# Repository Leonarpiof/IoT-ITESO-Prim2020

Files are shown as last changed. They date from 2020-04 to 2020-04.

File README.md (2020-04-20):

# IoT-ITESO-Prim2020
This repo contains the documentation and generated files during the IoT project of spring 2020 at ITESO, by Leon Arpio Fernandez

## Folders
### Arduino
Contains the source code of the project, in which the sensors are read, and data is sent through cellular network, 
using MQTT. This project is made for the Arduino MKR GSM 1400.

This project uses the following libraries:
- [Arduino MKR GSM libraries](https://github.com/arduino-libraries/MKRGSM)
- [MQTT library for Arduino](https://github.com/256dpi/arduino-mqtt)
- [I2C Soil Moisture Sensor](https://github.com/Apollon77/I2CSoilMoistureSensor)

### Documentation
Contains the documentation made during the project, which contains the research plan, comparative tables, requirements, business model,
customer journey, and others. **All documentas are in Spanish**.

### Lambda
Contains the Lambda deploy package, which has the lambda function handler, and the necessary libraries for the project to work, that are not included in AWS Lambda. Developed in Python 3.8. For the Lambda deploy package download Python library [requests](https://requests.readthedocs.io/en/master/).

To install the library in a specific folder, navigate in the command line to the desired folder, and use the following command.

```
pip install requests -t .
```
- Download [pip](https://pip.pypa.io/en/stable/reference/pip_download/)

### Schematics
Contains the schematic, board file and BOM. Schematic based on [Arduino MKR GSM 1400 schematic](https://store.arduino.cc/usa/mkr-gsm-1400).

### Scripts
Contains Python scripts to test different elements such as Ubidots, Mosquitto, and other features. For this scripts to work, it is necessary to install paho-mqtt and requests. Scripts developed in Python 3.8.1

# Author
León Arpio Fernández

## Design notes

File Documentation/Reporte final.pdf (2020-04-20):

## Instituto Tecnológico y de Estudios

## Superiores de Occidente – ITESO

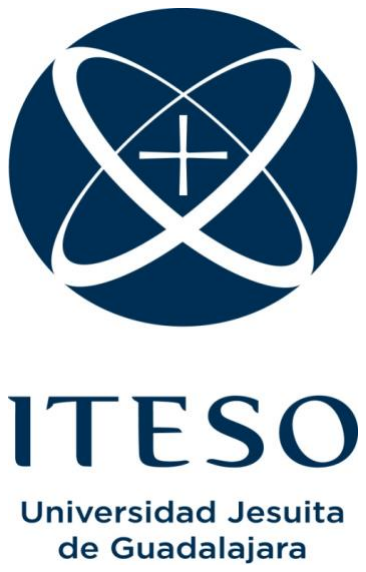
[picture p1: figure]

Reporte final

Materia: | Internet of Things
Maestro: | Héctor Edmundo Ramírez Gómez
Fecha: | 20 de abril de 2020
Autor: | Arpio Fernández, León. IE702086

Índice

Introducción

Planteamiento del problema

Conforme aumenta la población, cada día es más importante el manejo correcto de los

recursos a nuestro alrededor, ya que la demanda de estos aumenta de manera directa e

indirecta, viéndose la agricultura cada vez más afectada por este incremento, ya que no solo

debe de cumplir con el mercado, sino que es más costoso acceder a los recursos necesarios

para mantener la producción. A esto se suma el impacto ambiental de la agricultura, debido al

consumo constante de agua, suelo y energía que requiere para poder proveer alimentos a la

población.

Por eso, se existe la problemática del uso ineficiente de los recursos en la agricultura, ya que

muchas veces se desperdician algunos recursos como agua, sustratos, abonos, y no se

aprovechan de manera correcta otros, como la luz solar. Esto genera una amplia variedad de

problemas, que van desde generar un producto de mala calidad, hasta perder cosechas por

causa de enfermedades y plagas. A esto, se suma el hecho de que se invirtiera mucho dinero,

tiempo, mano de obra y materias primas en el plantío.

También, aunque un plantío no tenga problemas en la calidad del producto, o con

enfermedades en las plantas, este puede ser víctima de un uso muy ineficiente de recursos,

ya sea que estos se utilicen de más o de menos, lo que se ve reflejado en un impacto

monetario, que tal vez no sea tan obvio, pero que, manejando estas materias de manera

correcta, podría aumentar el margen de utilidad.

Objetivo

El objetivo de este proyecto es el de desarrollar un dispositivo capaz de monitorear las

variables más importantes en un cultivo de lechuga, y que pueda transmitir la información a un

servidor remoto, de manera que esta sea desplegada en tiempo real utilizando un tablero para

dar un formato visual y de fácil entendimiento, para de esta manera ayudar a los agricultores

a reducir los desperdicios tanto de productos como de recursos dedicados al cuidado de los

cultivos.

Validaciones

Se realizaron entrevistas a personas con conocimiento sobre el cuidado de cultivos,

especialmente de la lechuga, para conocer cuales son los principales riesgos y desperdicios,

así como las variables más importantes a monitorear para reducir o prevenir estos problemas.

Entrevistas

Laura Bucio – Proyecto de hidroponía para asignatura Internet of Things

¿Cuáles son los riesgos más comunes en el cultivo de la lechuga?

Muy sensible a la falta de higiene, ya que se pueden generar muchas bacterias. Lo más

recomendable es tener el área lo más limpio posible, para evitar que la lechuga se empiece a

pudrir.

¿Qué recursos y/o materias primas se desperdician más en un cultivo?

Los solutos, pues a veces no hay una medición precisa para saber cuánto se necesita para la

hidroponía.

¿Qué es lo que más valor te agregaría a tu negocio?

Tener un sistema autónomo que permita tener el monitoreo del cultivo a través de cualquier

dispositivo. Conectividad y medición de variables.

Si pudieras tener un dispositivo para el monitoreo de cultivos:

¿Cuáles son las variables más importantes por monitorear en un cultivo de lechugas?

Conductividad, luz, temperatura, pH.

¿Con qué frecuencia te gustaría actualizar la información de las variables?

Aproximadamente cada media hora, dependiendo de las hectáreas de lechuga que se tenga.

¿A qué alertas te gustaría tener acceso?

Alertas de todas las mediciones, aunque dependerá de la lechuga a la que se quiera enfocar;

romana, italiana, entre otras. Cada una tiene un tipo de pH, aunque hay un estándar para las

lechugas en general, hay ligeras variaciones para cada una.

¿Te gustaría ver alguna otra característica en el dispositivo?

Que sea visual, ya que algunos agrónomos prefieren que se les dé el dato y otros prefieren

que al final del día se les proporcione una gráfica con la información recolectada.

Álvaro – Verde tu vida

¿Cuáles son los riesgos más comunes en el cultivo de la lechuga?

Plagas, las más comunes son la mosca blanca y el pulgón amarillo. También la refrigeración y

almacenamiento del producto.

¿Qué recursos y/o materias primas se desperdician más en un cultivo?

Comúnmente, el agua, aunque depende mucho del diseño del sistema, también, los

fertilizantes, ya que se desperdician si estos no son asimilables o útiles para la planta, e incluso

se puede ver afectado el rendimiento del cultivo

¿Qué es lo que más valor te agregaría a tu negocio?

Incluir un envase, ya que estos aumentan mucho el precio del producto, y es necesario pues

al consumidor le da mucha confianza ver el producto empacado. Además, esto tiene un

impacto ecológico negativo.

Si pudieras tener un dispositivo para el monitoreo de cultivos:

¿Cuáles son las variables más importantes por monitorear en un cultivo de lechugas?

La luminosidad, el control de la humedad te puede evitar problemas con hongos y con plagas,

así como la temperatura. Otras variables importantes son la conductividad eléctrica y el nivel

de oxígeno en el agua. Sería útil un sistema de detección de plagas, para que la detección sea

en una fase temprana y no cuando el problema sea evidente y mucho más difícil de erradicar

o controlar.

¿Con qué frecuencia te gustaría actualizar la información de las variables?

Sería suficiente cada hora, ya que con este tiempo es suficiente reaccionar ante cualquier

cambio o fluctuación de las variables. Menos de una hora no sería necesario, incluso en

algunas variables por un periodo más prolongado, tal vez 3 horas.

¿A qué alertas te gustaría tener acceso?

Sería interesante tener alertas de bajas y altas temperaturas, de humedad baja y alta, niveles

de pH. Una alerta para detección temprana de presencia de plagas también sería atractiva.

Incluso sería interesante un monitoreo del crecimiento de la planta, por si la producción está

de algún modo escalonada, saber que lote es el más próximo a cosecha, para tenerlas en el

momento más oportuno.

Víctor Mojarro – Inncampo

¿Cuáles son los riesgos más comunes en el cultivo de la lechuga?

Primero, están los climáticos, que son los que tienen que ver con la temperatura, la radiación

solar, la luminosidad, entre otros. También puede haber daños físicos a las plantas, como falta

de cuidado en la manipulación de las plantas, mal manejo de herbicidas, sustratos, abono, etc.

Y están los daños biológicos, que son las plagas, hongos, patógenos y bacterias indeseadas

en el ambiente de cultivo.

Además de estos riesgos, también puede haber una mala selección de la lechuga, ya que

estas se dan por temporadas, una mala planificación del terreno, logística o los recursos

humanos.

¿Qué recursos y/o materias primas se desperdician más en un cultivo?

El principal es el dinero, ya que, como no hay un estándar de “los pasos a seguir”, no se utilizan

correctamente el agua, los fertilizantes y químicos, pues no se usan las cantidades necesarias

en el momento indicado.

Muchas veces el suelo no se aprovecha de manera correcta, ya que este no se estudia lo

suficiente antes de determinar cuántas plantas se cultivarán por metro cuadrado.

¿Qué es lo que más valor te agregaría a tu negocio?

Tener datos tanto climatológicos como eficiencias administrativas. El análisis de datos en todo

momento ayuda para mejorar el uso de los recursos destinados al cultivo, ya que solo se

utilizan las cantidades necesarias, y se disminuye el desperdicio. Además, el uso incorrecto de bienes como el agua, o los sustratos, pueden influir en la presencia de hongos o enfermedades

en la planta de lechuga.

Si pudieras tener un dispositivo para el monitoreo de cultivos:

¿Cuáles son las variables más importantes por monitorear en un cultivo de lechugas?

Humedad en el ambiente y suelo, luminosidad, radiación UVA y UVB, velocidad del viento,

temperatura ambiente y en el suelo, PH en el suelo y en el agua, conductividad eléctrica y

salinidad en el suelo.

También sería interesante tener mediciones del sistema de riego, para tener un control del

volumen de agua que está siendo utilizada para el riego.

¿Con qué frecuencia te gustaría actualizar la información de las variables?

Cada 30 minutos, aproximadamente, a lo largo del día y la noche.

Aproximadamente, ¿Cuantos dispositivos por unidad de área son necesarios?

Dependerá de la planta, y del terreno, pero se necesita al menos 1 dispositivo por cada 100

m2.

¿A qué alertas te gustaría tener acceso?

A mediciones altas y bajas de todas las variables leídas por el dispositivo.

¿Hay alguna relación entre los valores de las variables y la existencia de plagas?

Hay enfermedades, como la cenicilla, que se presenta cuando tienes alta humedad,

temperatura y un pH desfavorable. También, el exceso de ácido nítrico (Compuesto químico

usado en abonos) puede generar putrefacción en la planta.

Hay que tomar en cuenta que estas condiciones favorecen las enfermedades en las plantas,

mas no son indicadores de que el cultivo presenta estos males.

¿Te gustaría ver alguna otra característica en el dispositivo?

Algo que no he visto en ningún dispositivo, y que sería muy útil su monitoreo, es el de la vida

microbiana en el suelo, aunque esto es extremadamente difícil de lograr.

Consideraciones

La lechuga es muy sensible, y necesita mucho cuidado, desde la selección de la semilla, ya

que las diferentes lechugas son para diferentes temporadas; hay de frío a frío, frío a calor,

calor a calor y calor a frío.

La lechuga puede crecer en invernadero, marcotúnel, hidroponía o en campo abierto, y

siempre es necesario hacer un análisis de suelo adecuado, ya que, por ejemplo, un suelo

arenoso no tiene mucha retención de agua, lo que significa que se necesitará un riego constate,

o utilizar sustratos para cambiar esta propiedad. Además, es importante considerar que la

planta requiere de diferentes cantidades de recursos durante el día, por ejemplo, en la mañana,

consume más agua y nutrientes, ya que está en proceso de fotosíntesis.

También, es importante diseñar el sistema, y el monitoreo que sea de fácil uso, pues la mayoría

de los agricultores prefieren no invertir mucho tiempo en configurar una aplicación, o en instalar

un dispositivo, además de que, si se presentan problemas en el sistema, rápidamente

desecharán la solución.

Investigación en fuentes secundarias

Se realizó una investigación sobre el cuidado de la lechuga en fuentes secundarias para validar

y extender la información obtenida de las entrevistas. Específicamente de las variables a

monitorear, sus rangos óptimos, para poder determinar también las alarmas.

Temperatura

La lechuga necesita diferentes rangos de temperatura durante el día y la noche, además de

que estos rangos cambian dependiendo de la etapa de crecimiento de la lechuga.

Durante la germinación la temperatura requerida por la lechuga oscila entre los 18°C y los 20C.

En la fase de crecimiento la lechuga requiere de 14°C a 18°C durante el día y 5°C a 8°C

durante la noche. Por último, en la fase de acogollado, se requieren 12°C durante el día y 3°C

a 5°C durante la noche.

Humedad relativa

Durante toda la vida de la lechuga, se requiere una humedad relativa de 60% a 80%.

Suelo

El pH óptimo para el crecimiento de la lechuga se encuentra entre 6.7 a 7.4

Luz

La lechuga se desarrolla mejor entre 10 klx y 40 klx, que corresponde a disminuir la luz de un

día soleado con una protección, como plástico lechoso o malla sombra.

Cuando los recursos mencionados anteriormente no se controlan o suministran de manera

correcta, se aumenta el riesgo de que la planta contraiga alguna enfermedad, que afecte la

calidad del producto, o incluso, implique la pérdida parcial o total del cultivo. Algunas de estas

enfermedades son las siguientes.

Cenicilla

La cenicilla polvorienta es una enfermedad que ataca a diferentes hortalizas, causada por

hongos. Esta enfermedad ataca primeramente la hoja de la planta, y generando un polvo

blanco, que la cubre. Cuando evoluciona la enfermedad, la planta se defolia, y se deshidrata,

causando la pérdida total del producto, además de que es altamente contagiosa. Esta

enfermedad se presenta cuando el clima es seco, y demasiado humedad.

Botritis

Esta enfermedad genera manchas de aspecto húmedo en las hojas, las cuales se tornan

amarillas, y se cubren de moho gris. Si la humedad aumenta, la planta quedará cubierta de

hongo blanco, pero, si disminuye demasiado, se produce putrefacción en la planta. Esta

enfermedad se puede controlar disminuyendo la profundidad y densidad del cultivo, y

reduciendo los excesos de humedad.

Mancha parda

Esta enfermedad se caracteriza por manchas grandes de color amarillo rojizo en los nervios

de las hojas, las cuales pueden se pueden obscurecer o agrandar con el tiempo. Esta

enfermedad es causada por la exposición a atmósferas frías, con CO2 mayor al 3%.

Mosca blanca

La mosca blanca es una plaga que se alimenta de la savia de las plantas, robándoles nutrientes

y agua, lo que daña a las plantas. Además, la mosca blanca atrae hormigas, hongos y bacterias

indeseadas. Esta plaga se puede dar cuando la planta es regada en de más o de menos,

cuando hay demasiado nitrógeno en la tierra, y cuando hay demasiado o muy poca luz.

Estas y otras plagas y enfermedades se pueden evitar teniendo un mejor control de los

recursos dedicados al cultivo, evitando pérdidas innecesarias, que, además, pueden afectar a

futuros cultivos, ya que muchas de estas enfermedades se quedan en la tierra. Aquí, la solución

presentada puede prevenir estos agentes indeseados, ya que son causados por no controlar

variables como la humedad, temperatura, luz solar, y otras variables.

Análisis de alternativas

Tecnología de comunicación

Se realizó una comparación de diferentes tecnologías de comunicación inalámbrica, de

manera tal que se elija la que mejor se adecúe a la necesidad de tener un dispositivo con bajo

consumo de energía, posiblemente un gran tamaño de los mensajes, seguridad en la red, amplia

cobertura y bajo costo.

LoRa

Descripción

Es una tecnología de Red de Área Amplia de Bajo Consumo (LPWAN, por sus siglas en inglés),

creada en 2015 para cubrir necesidades de Internet de las Cosas, con el objetivo de permitir

al usuario controlar su propia red. La banda de operación está entre 433 MHz y 915 MHz

dependiendo de la ubicación (En América es de 915 MHz).

Ventajas

- Alta tolerancia a interferencias y jammers.
- Bajo consumo de potencia.
- Largo alcance (10 – 20 km).
- Bidireccional.
- Más capacidad de configuración.

- El uso de la red no requiere costo adicional.

Desventajas

- Más complejidad de uso.
- No ofrece encriptación.
- Se necesita instalar un servidor central para comunicar datos a internet.

ZigBee

Descripción

Tecnología de Redes Inalámbricas de Área Personal (WPAN, por sus siglas en inglés)

diseñada en 2004 para usos industriales, científicos y médicos, ya que esta ofrece espacio

para una gran cantidad de dispositivos conectados al mismo tiempo asegurando la integridad

de la red y los datos. La banda de operación es de 868 MHz para Europa y 915 para América,

aunque a nivel mundial se puede utilizar la banda de 2.4 GHz.

Ventajas

- No se ve afectada por la existencia de otras redes dentro de la misma banda (Bluetooth,

Wifi y otras).

- Permite alta densidad de operación.
- Permite la existencia de muchas redes y nodos ZigBee sin afectar su comunicación

(Hasta 16,000 diferentes redes, cada una con 65,000 dispositivos).

- Autorrecuperación en caso de fallas dentro de la red.
- Encriptación AES128.
- Enfocada al bajo consumo.

Desventajas

- Corto rango de cobertura (10 – 75 m).
- Requiere un servidor central (Coordinador) y varios intermediarios (Ruteador) para el

funcionamiento de la red.

- Diseñada para paquetes de información pequeños.

Sigfox

Descripción

LPWAN desarrollada en 2010 por la empresa homónima y diseñada para ultra bajo consumo

manteniendo una amplia cobertura. Además, Sigfox ofrece una API sencilla de utilizar, y

servicio en la nube para almacenamiento y manejo de datos, incluida con la subscripción. La

banda de operación es de 868 MHz para Europa y 902 MHz para América.

Ventajas

- Diseñada para bajo consumo.
- Bajo costo por paquete.
- Alta tolerancia a interferencias y jammers.
- Sigfox se encarga de la instalación de la red.
- Ofrece servicio de un servidor para almacenamiento de datos y ejecución de callbacks.
- Ofrece encriptación para mensajes pequeños (Propia de Sigfox).

Desventajas

- Límite de paquetes y de tamaño de cada paquete.
- Unidireccional.
- Tecnología patentada por Sigfox, por lo que reduce las opciones del servicio.
- Al ser provista por otra empresa, no se tiene control sobre la red como si fuera

desarrollada por el usuario.

- Al ser patentada, no permite un desarrollo más eficiente de múltiples compañías como

en tecnologías libres.

- Requiere una subscripción por dispositivo.

Wifi

Descripción

Estándar de la IEEE que define una tecnología para interconexión inalámbrica de dispositivos

entre sí, permitiendo, además, la conexión con internet, lo que facilita el acceso de dispositivos

a diversos servidores en la nube. Trabaja sobre las bandas de 2.4 GHz o 5 GHz, en todo el

mundo. Wifi permite tanto redes locales o públicas.

Ventajas

- Soporta encriptación, aunque no está configurada por defecto.
- Soporta diferentes protocolos de comunicación (MQTT, TCP, SSH, HTTP, etc.).
- Soporta varios niveles de encriptación.
- Puede utilizarse para comunicación tanto local como pública.
- Alta velocidad de comunicación (Hasta 54 Mbps).

Desventajas

- Fácil de interferir.
- Requiere de mediadores entre los dispositivos y un servidor central (AP/Routers).
- Corto alcance (100 m).
- No está enfocado al bajo consumo.
- Alto costo para una red con acceso a internet.

Red celular (2G/3G/4G)

Descripción

Medio de comunicación inalámbrico, utilizado para dispositivos móviles, que permite la

conexión de ellos a internet, además de la intercomunicación entre ellos por medio de

protocolos como SMS. El acceso a la web es provisto por diversos operadores. Las bandas de

operación van desde 800 MHz hasta 2.1 GHz.

Ventajas

- Gran cobertura en todo el mundo.
- Costo ajustable dependiendo del uso.
- Encriptación por defecto de A5/1 y A5/2.
- Posibilidad de incluir más capas de encriptación como SSL y TLS.
- Variedad de proveedores de red.
- Fácil cambio entre 2G/3G/4G y futuras.
- Futuro cambio de 2G a NB, red celular diseñada para IoT (Bajo consumo, bajo costo y

pago por uso).

Desventajas

- “Huecos” de cobertura en ciertas áreas geográficas.
- Alto costo por mensaje.
- Sensible a interferencias o jammers.
- No se tiene control sobre la red.
- No diseñada para bajo consumo.
- Actualización de la red no dependiente del usuario.
- Obliga a trabajar con un operador y al pago por el uso del servicio.

Elección de la tecnología

Tomando en cuenta las redes investigadas, se llegó a la conclusión de que la red celular es la

mejor opción, ya que permite la mayor libertad para métodos tanto de encriptación y protocolos

de comunicación, además de que no se requiere instalar mediadores entre el dispositivo y un

servidor. El mayor inconveniente es que la red no está diseñada para el bajo consumo, pero

dado que la frecuencia de muestreo es baja (Al menos un mensaje cada minuto), es posible

llevar al dispositivo a modo de bajo consumo de energía para el ahorro de esta. Por último,

esta tecnología permite una gran variación en el tamaño del mensaje, y seguridad mucho más

robusta que otras redes.

Sensores

Se realizó una tabla comparativa de diferentes sensores de temperatura en el ambiente,

humedad relativa en la tierra, luminosidad y conductividad eléctrica en la tierra, que son las

variables más importantes por monitorear, de acorde a las entrevistas realizadas.

Nombre | Precio (USD) | Protocolo de comunicación | Voltaje de alimentación | Variables que mide | Rango | Precisión
Catnip I2C Soil Moisture Sensor | $ 13.00 | I2C | 3.3V - 5V | Temperatura en el ambiente | 0°C - 85°C | ± 2%
| | | | Humedad relativa en la tierra | 10% - 100% | ± 2%
SEN0114 | $ 6.23 | Analógico | 3.3V - 5V | Humedad relativa en la tierra | 0% - 100% | No especificado
SHT11 | $ 51.87 | I2C | 3V - 5V | Temperatura en el ambiente | -40°C - 123°C | ± 0.4°C
| | | | Humedad relativa en la tierra | 0% - 100% | ± 3% RH

LM35 | $ | 7.31 | Analógico | 4V - 30V | Temperatura en el ambiente
-55°C - 150°C | ± 0.1°C
MAX6627 | $ 8.57 | SPI | 3V - 5.5V | Temperatura en el ambiente | -55°C - 125°C | ± 2.4°C
VEML7700 | $ 6.44 | I2C | 2.5V - 3.6V | Luz ambiental | 0.0072lx -120000 lx | ± 0.0036 lx
APDS9007 | $ 2.07 | Analógico | 2V - 3.6V | Luz ambiental | 3lx - 75000lx | ± 10 lx
GA1AS202WP | $ 1.16 | Analógico | 2.3V - 3.2V | Luz ambiental | 3lx - 55000lx | ± 0.5 lx
Liyuan conductivity, temperature and humidity | $ 51.00 | RS232 (UART) | 5V - 30V | Temperatura en el ambiente | 0 μS/m -200000 μS/m | ± 3%
| | | | Humedad relativa en la tierra | 0% - 100% | ± 3%
| | | | Conductividad eléctrica de la tierra | -40°C - 80°C | ± 3%
Arduino Conductivity Sensor | $ 85.00 | Analógico | 5V - 12V | Conductividad eléctrica de la tierra | 0 μS/m - 5000 μS/m | ± 0.2%
Isolated EC probe | $ 60.00 | I2C | 2V - 5V | Conductividad eléctrica de la tierra | 0.5 mS/cm - 20 mS/m | No especificado
| | | | Sólidos disueltos | 250 PPM -10000 PPM | No especificado
| | | | Temperatura en el ambiente | -55°C - 125°C | No especificado

Tabla 1. Tabla comparativa de los posibles sensores a utilizar. Referencias en capítulo Hojas de

datos consultadas.

De la tabla 1, se decidió elegir Catnip I2C Soil Moisture Sensor, ya que cubre 2 variables

(Temperatura en el ambiente, y humedad en la tierra), cubriendo el rango necesario para ser

medido, pues la temperatura mínima que soporta la lechuga es de 3°C, y este sensor es capaz

de leer hasta los 0°C sin problema alguno. La planta de lechuga requiere una humedad relativa

en la tierra entre el 60% y el 80%, entrando también en el rango de lectura del sensor. Por

último, aunque otros sensores tienen una mejor precisión, no es indispensable que esta sea

muy pequeña, ya que no se trata de un sistema extremadamente sensible.

Para la luminosidad, se decidió elegir el sensor GA1AS202WP, ya que cubre el rango

necesario, pues la lechuga necesita entre 10 klx y 40 klx, y el sensor es capaz de medir entre

3 lx y 50 klx. Además, ofrece el mejor precio, y tiene una muy buena precisión de 0.5 lx.

Por último, se decidió no elegir ningún sensor de conductividad eléctrica en la tierra, ya que,

además de que ya se están cubriendo las variables más esenciales, el menor precio por unidad

es de $51 USD, lo cual implica un aumento en el costo total que dificultaría la compra del

dispositivo por muchos usuarios.

Plataforma de desarrollo

Se realizó una tabla comparativa para elegir la plataforma de desarrollo y su respectivo

microcontrolador que se utilizará para resolver la problemática, para esto, se deberá tomar en

cuenta los sensores a utilizar, es decir, si la plataforma soporta el protocolo de comunicación

del sensor y la tecnología de comunicación utilizada.

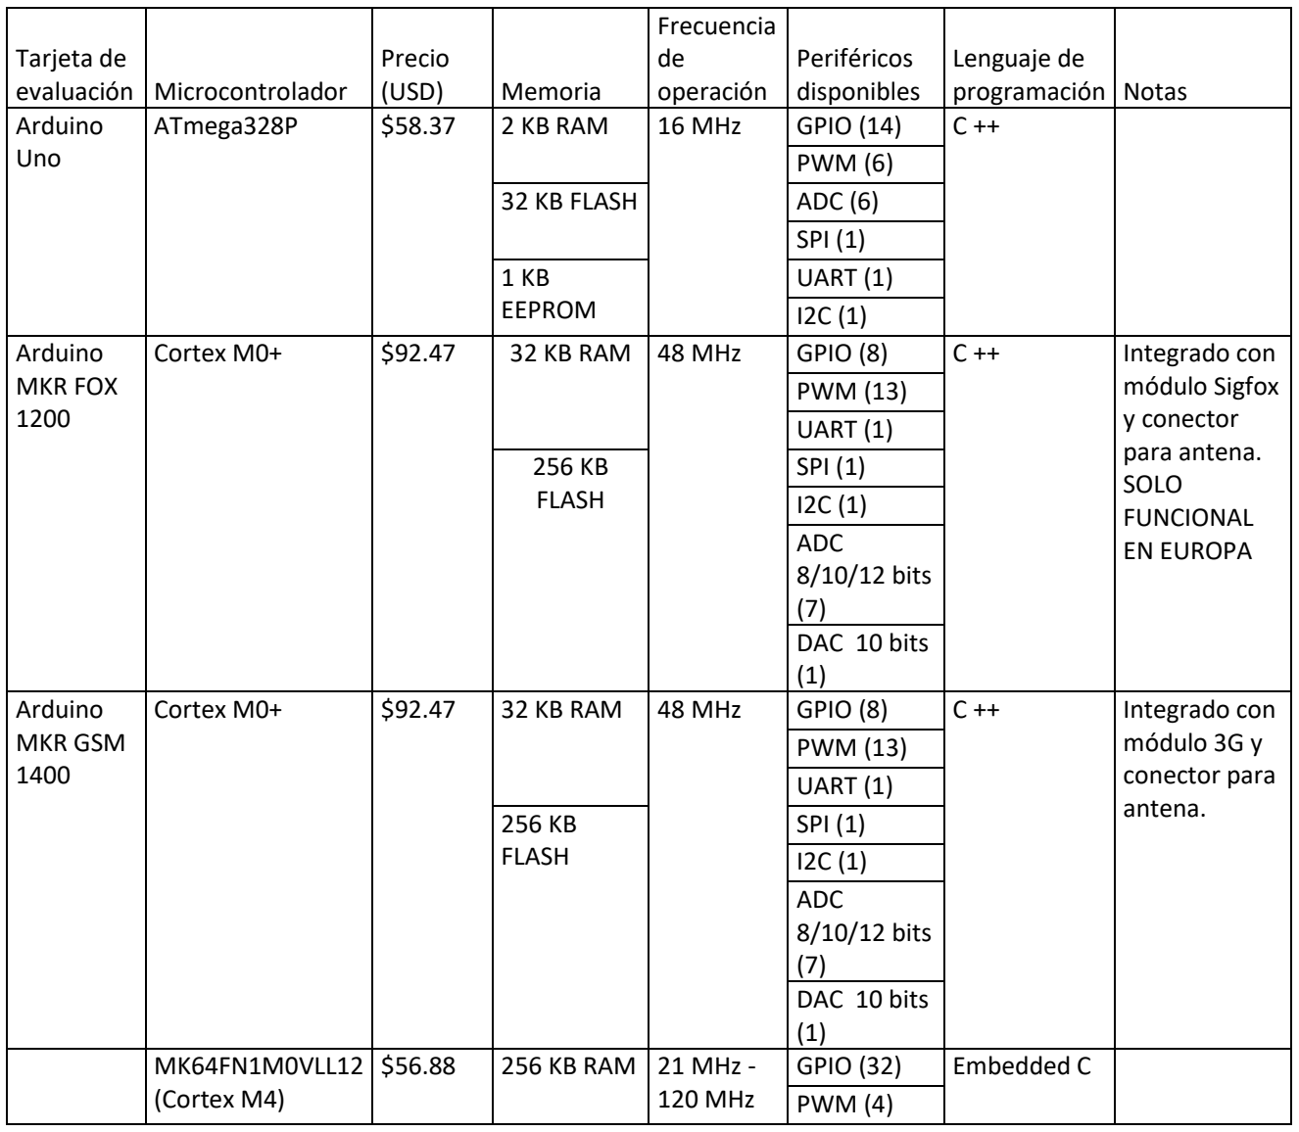
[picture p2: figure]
PWM (6); 32 KB FLASH; ADC (6); SPI (1); 1 KB EEPROM; UART (1) I2C (1); Arduino MKR FOX 1200; módulo Sigfox y conector para antena. SOLO FUNCIONAL EN EUROPA; PWM (13) UART (1); 256 KB FLASH; SPI (1) I2C (1) ADC 8/10/12 bits (7) DAC 10 bits (1); Arduino MKR GSM 1400; módulo 3G y conector para antena.; MK64FN1M0VLL12 (Cortex M4); 256 KB RAM; 21 MHz -; 120 MHz; GPIO (32); Embedded C; PWM (4)

Tarjeta de evaluación | Microcontrolador | Precio (USD) | Memoria | Frecuencia de operación | Periféricos disponibles | Lenguaje de programación | Notas
Arduino Uno | ATmega328P | $58.37 | 2 KB RAM | 16 MHz | GPIO (14) | C ++
Cortex M0+ | $92.47 | 32 KB RAM | 48 MHz | GPIO (8) | C ++ | Integrado con
Cortex M0+ | $92.47 | 32 KB RAM | 48 MHz | GPIO (8) | C ++ | Integrado con

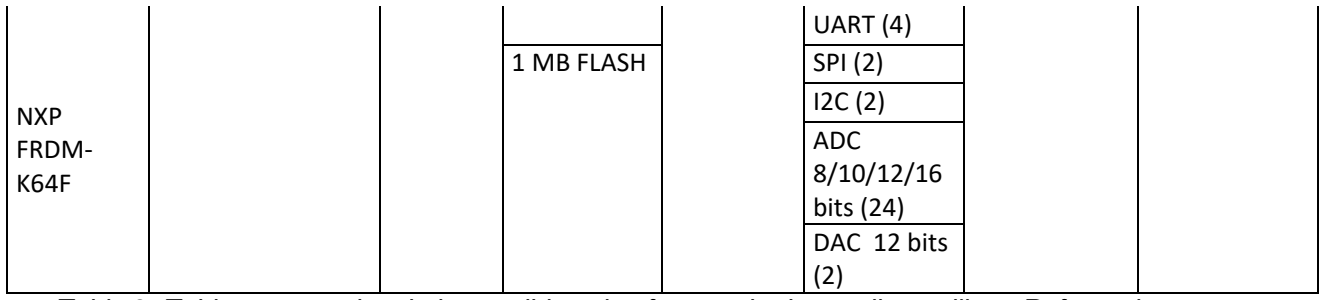
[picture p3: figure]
NXP FRDM- K64F; UART (4); 1 MB FLASH; SPI (2); I2C (2) ADC 8/10/12/16 bits (24) DAC 12 bits (2)

Tabla 2. Tabla comparativa de las posibles plataformas de desarrollo a utilizar. Referencias en capítulo: Hojas de datos consultadas.

Tomando como base la tabla 2, y en conjunto con la elección de la red a utilizar (Red celular),

se decidió elegir la plataforma Arduino MKR GSM 1400. Esta tarjeta viene integrada con un

módulo GSM 3G, y con un Cortex-M0 con los periféricos necesarios para comunicarse casi

con cualquier sensor (ADC, UART, SPI, I2C, etc), además de tener una alta frecuencia de

operación, que permite operaciones en tiempo real. Dado que la frecuencia de muestreo del

sistema es lenta (Mínimo 15 minutos entre una muestra y otra), esta frecuencia de operación

es más que suficiente para ejecutar los cálculos necesarios antes de enviar la información.

La programación de este módulo es por medio de C++, en el IDE (Integrated Developmente

Environment) de Arduino. Al ser abierto tanto el hardware como el software, se tiene acceso a

los esquemáticos, en caso de que se desee diseñar una PCB para el proyecto. También, se

tiene acceso a las librerías para el manejo del módulo GSM, de manera que facilita el desarrollo

de la solución.

Por último, una ventaja de esta plataforma es el hecho de que la documentación de este

dispositivo es extensa, y muy utilizada, por lo que también se pueden encontrar foros en donde

se presentan soluciones a diversos problemas que se pueden presentar durante su uso.

Servidor

Se realizó una comparación entre diferentes servidores para recibir la información enviada por

el dispositivo, procesarla y almacenarla, así como redirigirla a la aplicación en la que se

presentarán los datos.

Amazon Web Services (AWS)

Servidor en la nube de Amazon, que ofrece servicios como bases de datos, procesamiento de

información, respuestas a eventos, y comunicación por MQTT y HTTP de manera segura. AWS permite el manejo de los datos por medio de la función Lambda, la cual, ante un mensaje u

otro tipo de evento, se ejecuta, a manera de callback, permitiendo manejar la información de

la manera deseada. Además, el servicio de Dynamo DB, permite el almacenamiento de datos

de manera rápida y segura. Este servicio es gratuito hasta 25 GB de almacenamiento, y un

millón de solicitudes de Lambda al mes.

Microsoft Azure

Este proveedor de servicios en la nube ofrece beneficios similares a los mencionados en AWS,

pues ofrece comunicación por MQTT y HTTP, también con posibilidad de brindar una conexión

segura. También, Azure ofrece Function como procesador de eventos, permitiendo hasta 1

millón de solicitudes cada mes, sin embargo, Azure no provee un servicio de bases de datos

gratuito, de manera que, o habría que pagar este servicio, o se debe de implementar en un

servidor aparte, una base de datos controlada por el usuario.

Mosquitto

Mosquitto es un proyecto open-source que ofrece comunicación MQTT de manera segura y

siempre gratis. A diferencia de las otras dos opciones revisadas anteriormente, esta solución

debe de ser instalada en un servidor por el usuario, además de que no ofrece un servicio de

base de datos. La ventaja del uso de este broker es el de tener el control total del servidor, sin

tener que pagar en ningún momento por su uso, aunque, si en algún momento el hardware ya

no es capaz de procesar las solicitudes, se tendrá que mudar a otro dispositivo, o aumentar de

alguna manera su capacidad.

Después de revisar las opciones para el servidor, se decidió utilizar AWS, ya que ofrece un

servicio de base de datos, comunicación por MQTT y procesamiento de los mensajes recibidos

de manera gratis. Aunque el servidor de Amazon tiene un límite para su uso gratuito, este

permitirá, a una frecuencia de envío de 15 minutos, aproximadamente 320 dispositivos. A

diferencia de Azure o Mosquitto, el servicio de Amazon también ofrece almacenamiento de la

información recibida, lo cual es benéfico pues ya no se requiere instalar un servidor para

manejar la información, o pagar extra por el espacio de almacenamiento.

Costos de desarrollo

Elemento | Costo (USD)
Arduino MKR 1400 | $ 92.47
Antena GSM | $ 5.71
Batería Li-Po | $ 14.95
I2C Soil Moisture Sensor | $ 13.00
GA1AS202 | $ 5.14
AWS | $ -
Ubidots | $ -
SIM | $ 1.00
Saldo | $ 2.50
Protoboard | $ 4.00
Componentes extra (Alambre, resistencias, capacitores, LED) | $ 2.00
Envios | $ 5.00
Total | $ 145.77
Tabla 3. Costos de desarrollo.

Diseños y desarrollos técnicos

Arquitectura general

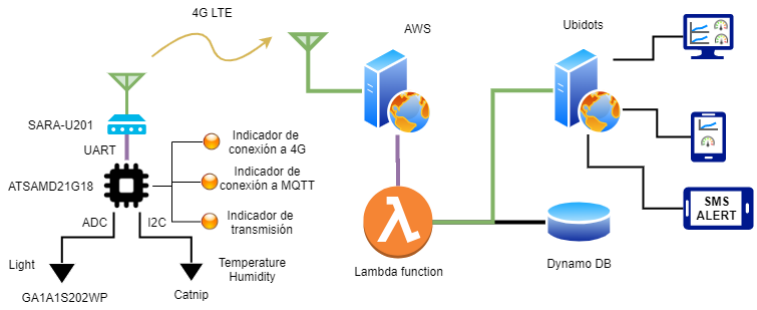
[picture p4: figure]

Figura 1. Arquitectura general del sistema.

La primera etapa del sistema consiste en la lectura de los sensores utilizando el

microcontrolador ATSAMD21G18, donde este enviará la información encriptada al módulo de

comunicación celular SARA-U201, el cual se encargará de transmitir la información recibida

por medio del protocolo de Transporte de Colas de Mensajes por Telemetría (MQTT), encriptada con Capa de Puertos Seguros (SSL) a la plataforma de Amazon Web Services

(AWS).

Una vez recibido el mensaje por el servidor, la función Lambda desencriptará la información y

la guardará en el servicio de bases de datos de Amazon llamado Dynamo DB, además, enviará

la información a Ubidots, plataforma utilizada para presentar los datos, la cual puede ser

accedida por medio de una computadora, tableta o un celular inteligente, en esta aplicación se

presentará la información tanto en forma de gráfica, pudiendo el usuario elegir el periodo de

tiempo que se mostrará en la gráfica. Además, Ubidots enviará una alerta en caso de que una

variable esté en un modo indeseado durante cierto tiempo, permitiendo reaccionar

rápidamente al evento sin necesidad de estar al pendiente de la información arrojada por la

aplicación.

Diseño electrónico

Para el desarrollo con el Arduino, no fue necesaria ninguna etapa de adecuación, ya que el

sensor de luminosidad ya viene integrado con una resistencia, necesaria para la interpretación

del sensor, y un capacitor para filtrar ruido, de manera que solo se necesita conectar a voltaje

y tierra para que la salida de un valor interpretable. La salida de este sensor está definida de

la siguiente manera.

Io = 10 log(Ev

)

Donde:

Ev: Luminosidad en Lux.

Io: Corriente de salida del sensor.

Dado que la resistencia que viene integrada con el transductor es de 68 kΩ, el cálculo de la

corriente con respecto a la iluminación está dado de la siguiente manera.

Io[μA] =

Vo
R

= 10(1μA) log(Ev

)

Donde:
R: Resistencia del sensor (68 kΩ).

Vo = Voltaje de salida del sensor.

Despejando para Ev.

log(Ev

) =

Vo
(10)(R)(1μA)

Ev = 10

Vo
(10)(R)(1μA) = 10

Vo
(10)(68x10³)(1x10⁻⁶)

De igual manera, el sensor de humedad y temperatura de I2C no necesita nada extra de

hardware para se usado con el Arduino MKR 1400, ya que este cuenta con resistencias

integradas de pull-up necesarias para el funcionamiento de I2C. Este sensor devuelve la

temperatura en decimales de °C y la humedad en decimales de % RH, por lo que únicamente

hay que dividir el valor obtenido de cada variable entre 10 para obtener su valor en unidades.

Se agregaron 3 LED indicadores para conocer el estatus del microcontrolador sin necesidad

de conectarse al puerto serial, estos LED representan la conexión a red 4G, conexión al

servidor MQTT y envío de mensaje exitoso; este último se encenderá durante 2 segundos,

cada vez que se publique exitosamente a AWS. Para esto, se utilizaron resistencias de 1kΩ

para proveer la corriente necesaria al LED.

Nota: Nunca se deberá de utilizar el dispositivo sin antena de red celular, ya que este se puede

dañar parcial o totalmente.

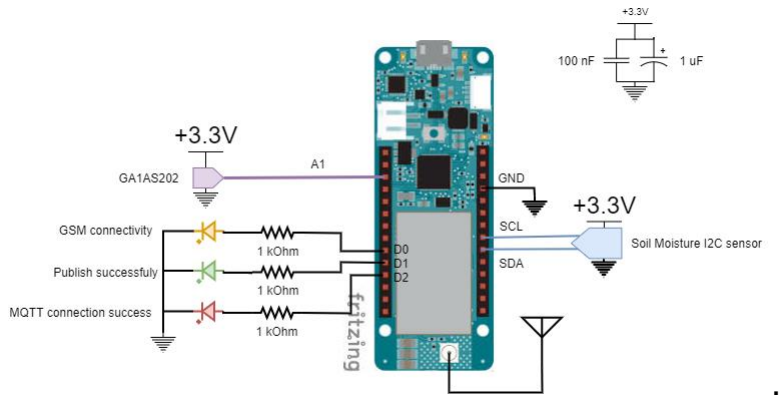
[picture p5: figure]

Figura 2. Esquemático del sistema con Arduino GSM 1400.

El mensaje enviado por el dispositivo a AWS es una cadena de caracteres, en formato JSON,

con el siguiente formato:

{
"time":timestamp,
"IMEI":"imei",
"temp":temperature,
"hum":humidity,
"lum":luminosity
}

Donde:

- Timpestamp: Cantidad de segundos que han pasado desde el 1 de enero de 1970

(Tiempo Unix).

- IMEI (Identidad Internacional de Equipo Móvil, por sus siglas en inglés): Identificador

único del dispositivo, compuesto por una cadena de 16 dígitos.

- Temperatura: Temperatura en decimas de °C.
- Humidity: Humedad relativa en decimas de %.
- Luminosity: Luminosidad en lx.

Todos los valores enviados deberán estar en formato ASCII.

Seguidamente se procedió a diseñar el esquemático, en Eagle, para el diseño de la PCB,

tomando como referencia el del Arduino MKR GSM 1400, al cual se eliminaron los elementos

que no son requeridos para el producto final, como los headers, y hardware extra, y se

agregaron los pads para soldar los sensores, así como los LED y sus respectivas resistencias.

Para poder acceder a todos los componentes, tanto la figura del esquemático, como su

footprint para la PCB, ir a File>Import>EAGLE drawing y seleccionar el archivo .sch deseado.

Al ir al botón Generate/switch to board, aparecerán todos los footprint correspondientes del

esquemático.

Figura 3. Botón para generar o cambiar al diseño de la PCB.

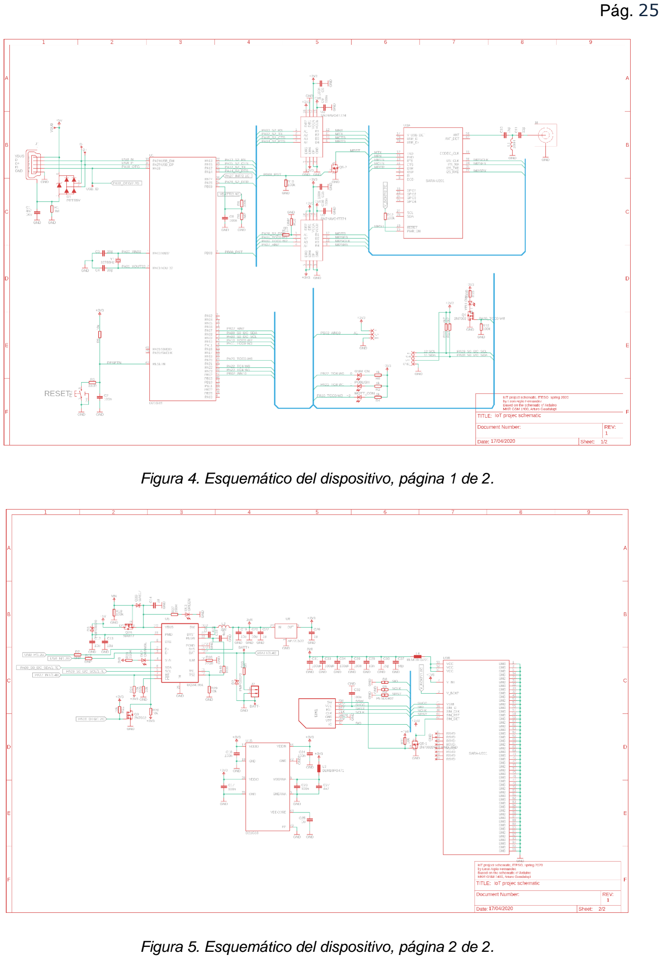
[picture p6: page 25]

Figura 4. Esquemático del dispositivo, página 1 de 2.

Figura 5. Esquemático del dispositivo, página 2 de 2.

Después de diseñar el esquemático, se procedió al diseño de la PCB, utilizando también Eagle.

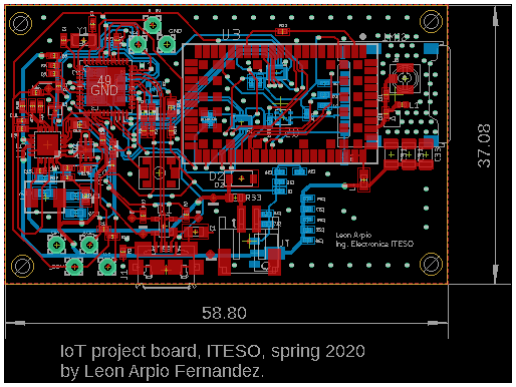
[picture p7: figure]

Figura 6. Diseño de la PCB.

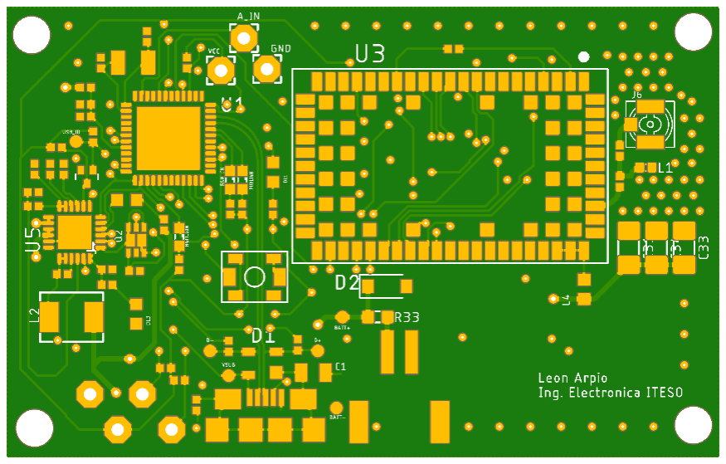
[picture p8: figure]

Figura 7. Vista de la PCB final (Top).

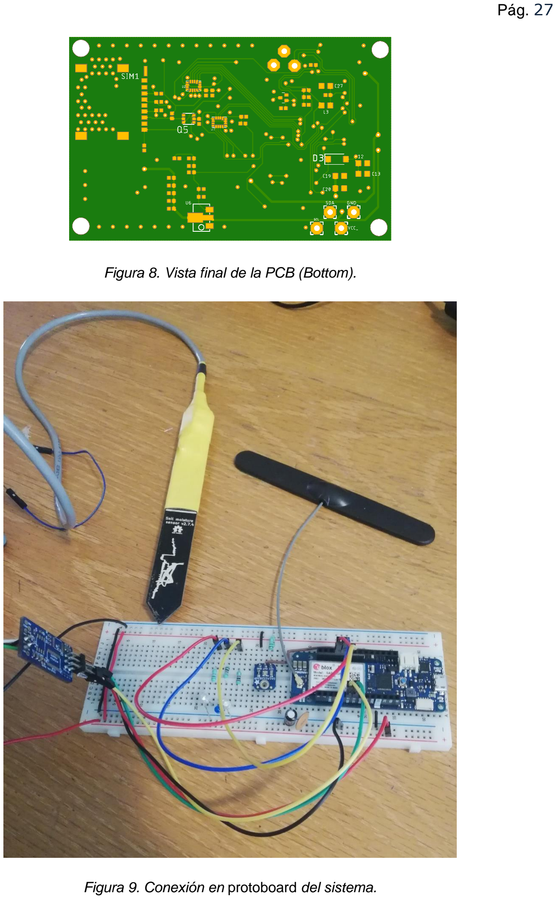
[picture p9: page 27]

Figura 8. Vista final de la PCB (Bottom).

Figura 9. Conexión en protoboard del sistema.

Diseño informático

Para el desarrollo informático, primero se procedió a configurar AWS de manera que el

dispositivo se pueda conectar, publicar y recibir mensajes por medio del protocolo de

Transporte de Colas de Mensajes por Telemetría (MQTT, por sus siglas en inglés). Una vez

configurados los dispositivos que podrán publicar o recibir información de un tema por MQTT

(Ver el tutorial de AWS, en el repositorio de este proyecto), se procedió a programar la función

Lambda que se encargará de recibir y procesar los mensajes para mandarlos al servicio de

bases de datos Dynamo DB, así como a la aplicación Ubidots, publicando la información por

medio HTTPS.

Dado los datos por almacenar no requieren de una base de datos compleja, además de que el

servicio DynamoDB provee de una base de datos NoSQL, solamente se requiere que el

dispositivo envíe su IMEI, el cual será la clave principal, y el timestamp, el cual será la clave

de ordenación, dando la flexibilidad de que se utilicen dispositivos que midan diferentes

variables y envíen la información recolectada al mismo servidor. En otras palabras, cualquier

otro campo puede ser enviado y será almacenado sin mayor problema en la base de datos.

La aplicación Ubidots, recibirá la información de cada dispositivo, reenviado a este por la

función Lambda, y la graficará permitiendo un análisis rápido y sencillo de este. Además, esta

plataforma podrá enviar una alarma, ya sea un correo, mensaje SMS u otro, en caso de que

una alarma tenga un valor mayor o menor que cierto umbral.

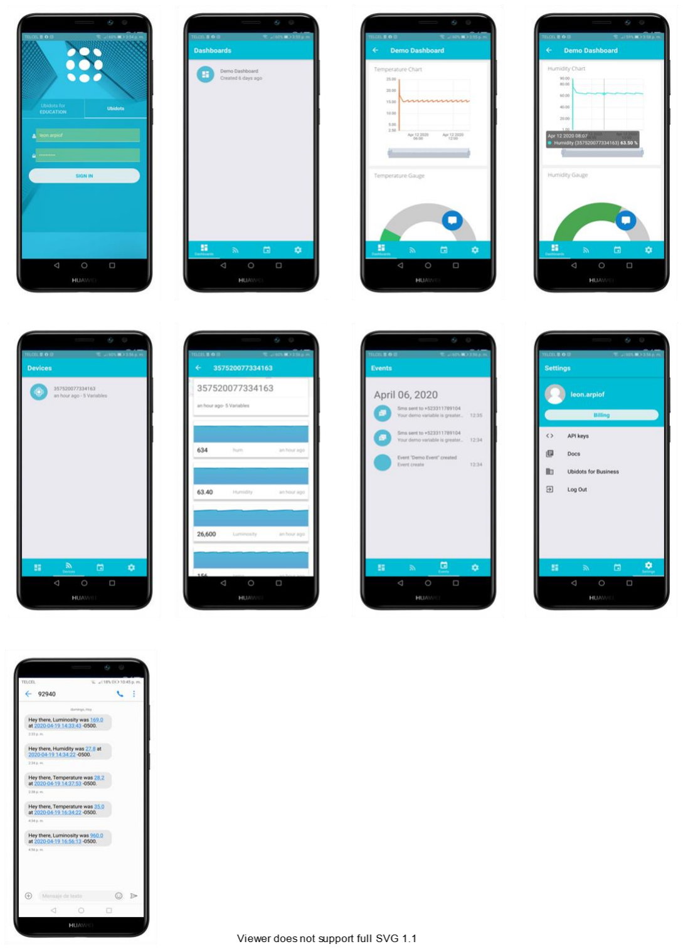
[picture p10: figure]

Figura 10. Interfaz de usuario en aplicación móvil de Ubidots.

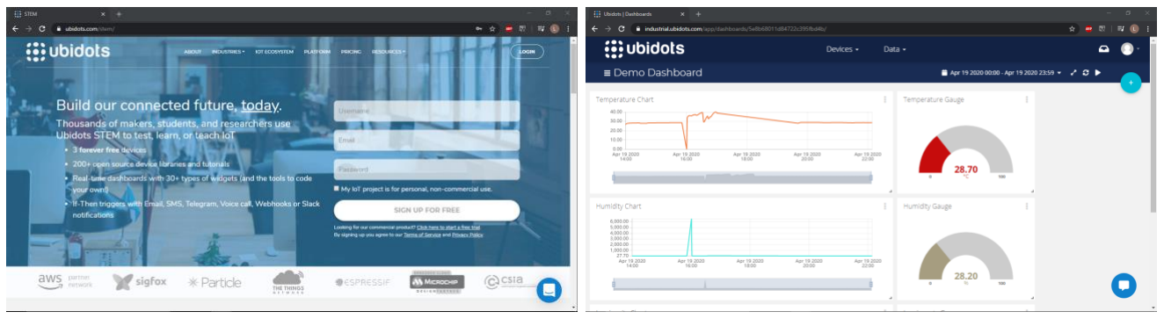
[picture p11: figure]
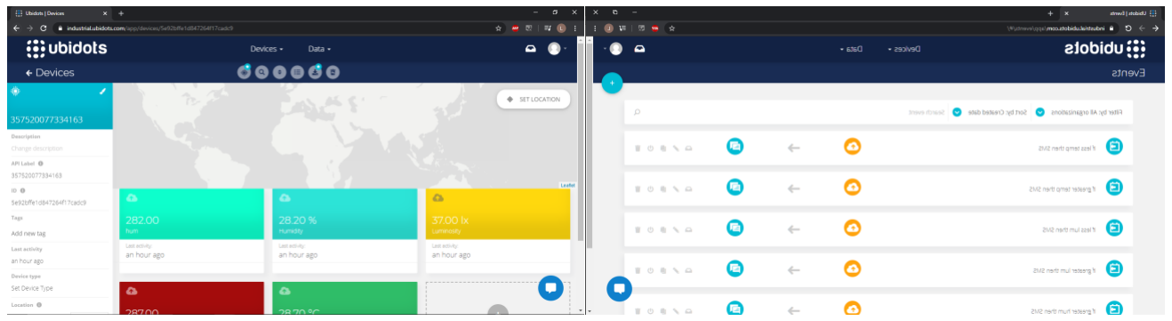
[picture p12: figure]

Figura 11. Interfaz de usuario en aplicación web de Ubidots.

Análisis de riesgos y seguridad de la información

Tras analizar la arquitectura del sistema, se lograron identificar los siguientes riesgos:

Comunicación entre microcontrolador y módulo celular

Dado que el microcontrolador y el módulo celular se encuentran conectados por UART,

fácilmente alguien podría conectarse a estas líneas y recibir la información que se enviará por

MQTT, ya que el dispositivo enviará la información recolectada para que esta pueda ser

transmitida a internet.

Comunicación del dispositivo a AWS

Al enviar los datos por comunicación celular, la información se vuelve accesible para quien

tenga una antena de 2.4 GHz, ya que, al ser comunicación inalámbrica, cualquiera puede

escuchar los datos transmitidos. Además, esta información llega a internet, donde es

susceptible a ataques.

Comunicación de AWS a Ubidots

Al igual que en el punto anterior, la información enviada a la aplicación en la que se desplegará

la información es vulnerable, si esta no tiene la seguridad suficiente, aunque es menos

propensa a ataques porque se ve protegida por la seguridad de los servidores que la emiten.

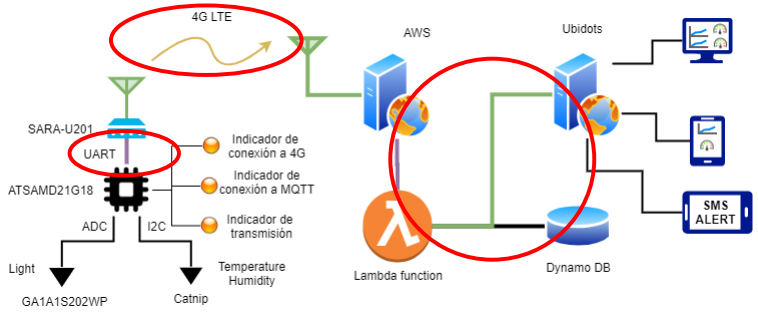
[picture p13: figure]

Figura 12. Riesgos de seguridad en la arquitectura.

Para resolver el primer riesgo, solamente se requiere una encriptación sencilla de los datos

sensibles, por ejemplo, cifrado por XOR. Aunque este método es fácil de descifrar, para lograrlo

se tiene que estar físicamente con el dispositivo, además de que, para encontrar la contraseña,

se debe de alimentar con datos conocidos al sistema, lo cual se dificulta debido a que la

manera de que el sistema recibe los datos es por medio de ADC o de I2C. Es importante hacer

notar que sólo se puede cifrar la información medida, es decir, dado que los datos se envían

en formato JSON, sólo podemos cifrar el valor de algunos datos, pues AWS solamente recibe

mensajes en dicho formato. Además, una encriptación más compleja pudiera afectar el

rendimiento del dispositivo.

La manera más efectiva de resolver el segundo riesgo es encriptando la conexión por medio

de TLS, ya que con este protocolo se vuelve prácticamente imposible descifrar la información

sin los certificados y llaves con los que fueron encriptados. Además, la red celular ya viene con

encriptación A1/5 por defecto, aunque esta capa no es lo suficientemente segura. De igual

manera, el tercer riesgo se debe de resolver con TLS.

Código desarrollado

Descripción de la arquitectura del software y firmware

Códigos en capítulo Anexos.

Arduino

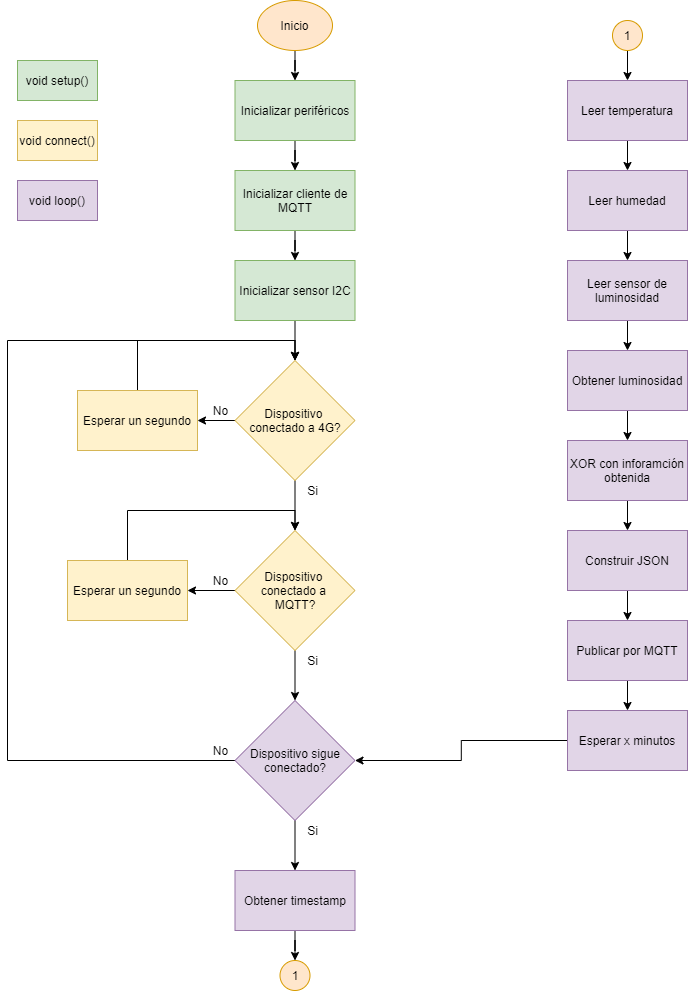
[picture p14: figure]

Figura 13. Diagrama de flujo del código de Arduino.

En la figura 13 se puede observar el proceso que lleva a cabo el Arduino, el cual inicializa el

módulo celular, y el sensor de I2C (El sensor de luminosidad no requiere de inicialización), y

después intenta conectarse a la red celular, y después al servidor MQTT, una vez que se logra

esto, se obtiene la información de los sensores de humedad, temperatura, luminosidad, y

también obtiene el timestamp del módulo celular, construye el mensaje en formato JSON, para

lo cual, convierte todas las variables a string, y finalmente lo publica por MQTT al servidor de

AWS. Por último, después de esperar x tiempo, definido por el usuario, revisa la que la conexión con el servidor MQTT, o con la red GSM, no se haya perdido; en caso de falla en la

conexión, repite el proceso inicial, de lo contrario, continúa leyendo los sensores.

En el proceso de desarrollo del código de Arduino, se descubrió que, debido a un bug del

módulo celular, este no acepta certificados, necesarios para la comunicación por SSL, y por lo

tanto con AWS. Para resolver este problema se configuró el Arduino para que este publicara,

por MQTT, a un servidor de pruebas público llamado Mosquitto, el cual no requiere de conexión

segura para recibir la información. Por otro lado, se desarrolló un código en Python el cual se

conecta a Mosquitto y a AWS, y envía la información recibida de el primer servidor al segundo,

utilizando TLS v1.2.

Lambda

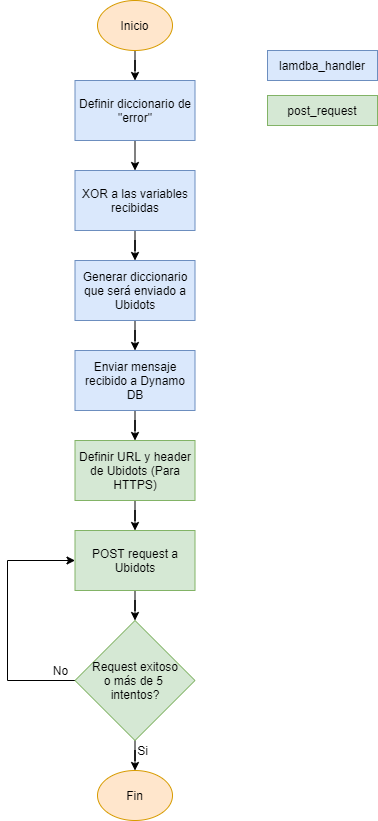
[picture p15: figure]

Figura 14. Diagrama de flujo de la función Lambda.

En la figura 14, se muestra el proceso de la función Lambda al recibir un mensaje por MQTT.

Este mensaje se recibe como un diccionario de Python, aunque éste se enviado como una

cadena de caracteres, y se envía a Dynamo DB. También, se extrae la información necesaria

para Ubidots, y se envía por medio de HTTPS. Originalmente, esta transmisión iba a ser por

medio de MQTT, utilizando la librería de paho-mqtt, pero no funcionaba correctamente, sin

razón alguna, y la información no siempre la recibía Ubidots, por lo que se decidió utilizar el

protocolo HTTP.

Repositorio en GitHub

https://github.com/Leonarpiof/IoT-ITESO-Prim2020

Modelo de negocios

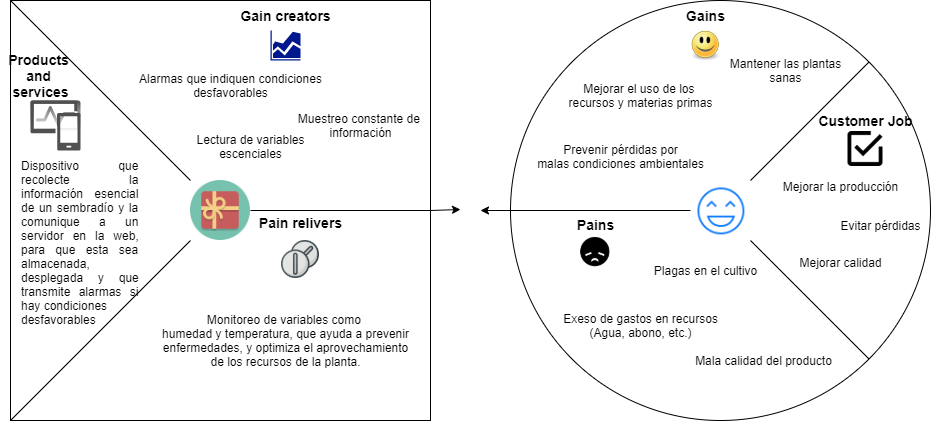
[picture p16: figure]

Figura 15. Canvas de propuesta de valor.

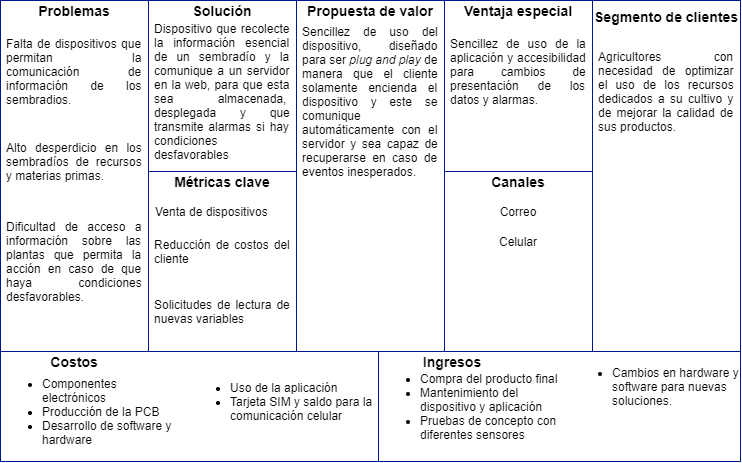
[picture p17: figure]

Figura 16. Lean canvas.

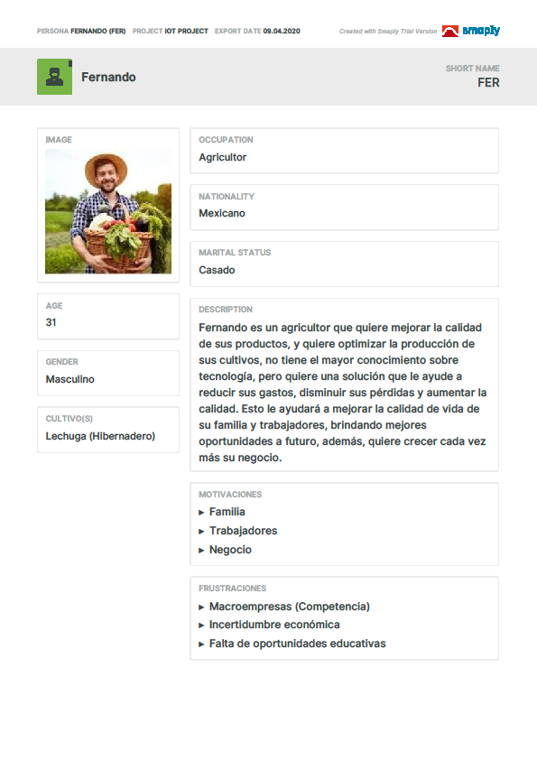
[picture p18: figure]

Figura 17. Arquetipo de persona.

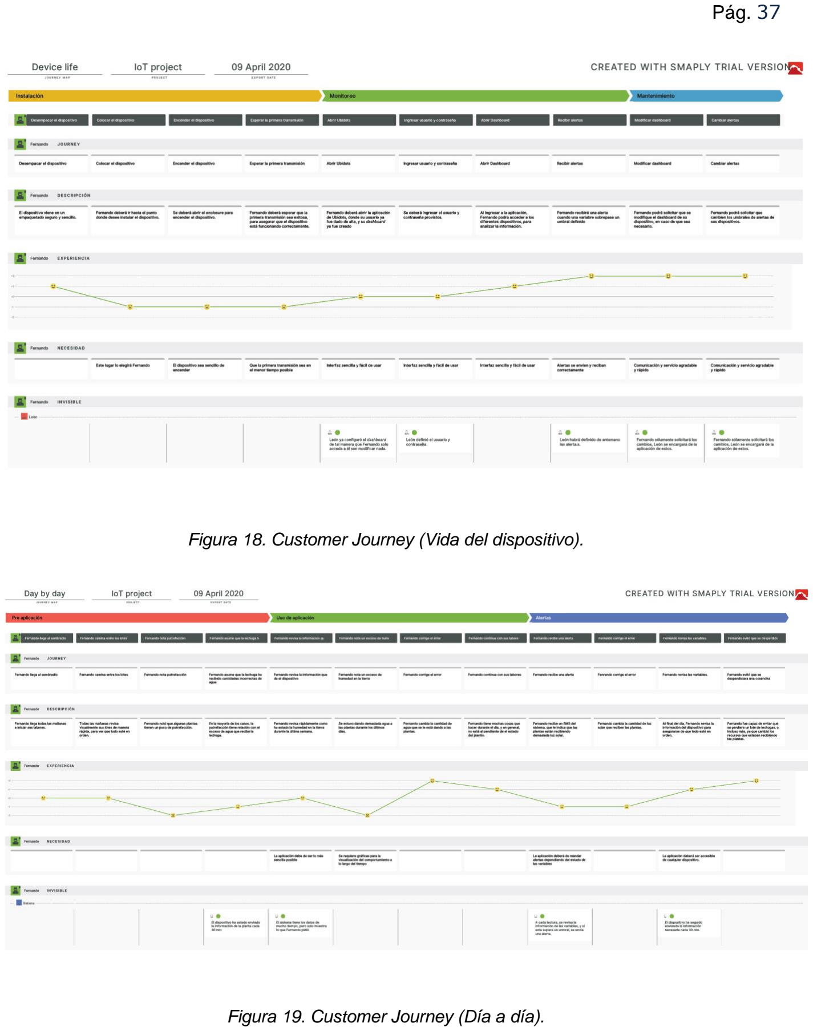
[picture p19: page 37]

Figura 18. Customer Journey (Vida del dispositivo).

Figura 19. Customer Journey (Día a día).

Next steps

Para lograr concluir este proyecto, lo primero es revisar una alternativa para el módulo celular,

especialmente otras alternativas del mismo fabricante, y la misma línea, para verificar si es

que existe otro módulo que utilice el mismo instruction set de comandos AT, y que sea pin-to-

pin compatible, de manera que el dispositivo se pueda comunicar directamente con AWS, es

decir, utilizando SSL/TLS. En caso de que no exista un módulo que cumpla estos

requerimientos, se deberá buscar otro módulo de comunicación celular que permita lograr una

conexión por MQTT segura.

Otro paso importante que debe de ejecutarse es el de la producción de un prototipo de la PCB,

y la prueba de este, para asegurarse de que esta fue diseñada correctamente, y en caso de

que haya algún error, corregirlo, para poder producir el dispositivo en masa, ya con una PCB

funcional. De igual manera, aunque este paso se deberá adecuar a cada cliente, encontrar un

contenedor para el dispositivo que permita que este pueda ser instalado al aire libre sin el

riesgo a que el agua, el sol u otras variables afecten al dispositivo.

Un posible paso, que dependerá de que tanto se quiera escalar el proyecto, sería el de generar

librerías específicas para el control del dispositivo, de manera que se optimice el

funcionamiento del microcontrolador, y que se exploten todos los recursos que este contiene,

como watchdog, RTC, unidad de bajo consumo, y otras, pudiendo así generar una solución

mucho más robusta.

Conclusiones

De este proyecto se concluye la importancia de todo lo que se tiene que hacer antes y después

de desarrollar un dispositivo o un servicio, es decir, la parte innovadora de un producto no es

solo el dispositivo, o el desarrollo tecnológico que hay detrás de este, si no la toma correcta de

decisiones para lograr algo que se vaya a vender, esto implica hacer un análisis asertivo de

las personas a quienes vaya dirigido el producto o servicio, y hacer todo el desarrollo siguiendo

este análisis, pues si no, es altamente probable que no se venda, y que se desperdicie todo el

tiempo, dinero y esfuerzo dedicados.

También, siempre es importante tener en mente las dificultades que se pueden presentar, y

estar preparados para pivotear o incluso cambiar radicalmente uno o varios elementos durante

el desarrollo, como ejemplo, es posible que, para generar un producto que se pueda vender, se tenga que volver a desarrollar casi toda la parte electrónica por un bug del módulo celular,

e incluso es posible que sea conveniente cambiar de tecnología de comunicación, por causa

de un problema que difícilmente se iba a conocer de antemano, pues la manera de descubrirlo

fue haciendo pruebas, y revisando muy a fondo los foros, pues el fabricante no anuncia este

problema.

Estos cambios, ante los cuales se tiene que estar abierto, no solo pueden venir por problemas

en el desarrollo, sino también por necesidades del mercado, es decir, puede ser que algún

mercado más grande requiera de la medición de otras variables, aunque esto impacte en el

costo del dispositivo, o tal vez se descubre que también las personas con interés de tener

cultivos en casa son un mercado más amplio que el de agricultores. Todas estas posibilidades

de cambio siempre están presentes en todos los proyectos, por lo que es importante tener en

cuenta diferentes planes de acción, tanto para cambios pequeños como para cambios grandes,

de manera que se pueda modificar el proyecto rápidamente, y lograr un producto o servicio

exitoso.

Anexos

Video del proyecto

https://www.youtube.com/watch?v=3qBIEVxmApw

Código de Arduino

/**************** INCLUDES **************************************************/ #include <I2CSoilMoistureSensor.h>
#include <Wire.h>

#include <String.h>

#include <GSMSSLClient.h>

#include <GSMSecurity.h>

#include <GSMModem.h>

#include <GPRS.h>

#include <PubSubClient.h>

#include <MQTT.h>

#include "secrets.h"

/**************** INCLUDES **************************************************/

/**************** DEFINES ***************************************************/ /** Use Telcel's APN*/
#define TELCEL | (1)

/** Use AT&T's APN (Mexico)*/
#define AT_T | (0)

/** Use Movistar's APN*/

#define MOVISTAR | (0)

/** Sets a test message to the buffer*/
#define TEST_MSG | (0)

/** Enables or disables the use of SSL*/
#define SSL_EN | (0)

/** Use Mosquitto test broker DO NOT PUBLISH SENSITIVE DATA*/ /** Mosquitto test broker is public, so anyone may be listening, do not publish any sensitive data.*/
#define MOSQUITTO_BRK (1)

/** Use AWS broker*/
#define AWS_BRK | (0)

/** Port to which the device will connect. Usually:
1883 -> MQTT not secure
8883 -> MQTT secure*/
#define PORT | (1883)

/** Max message size*/
#define MSG_SIZE | (100)

/** IMEI size*/
#define IMEI_SIZE | (16)

/** Size for the temp buffer*/ #define TEMP_BUFF_SIZE (20)

/** Serial port baud rate*/
#define SER_PORT_BR | (115200)

/** Defines the time between two messages (ms)*/
#define DELAY_TIME | (60000)

/** Defines the delay between two I2C readings (ms)*/
#define I2C_DELAY | (50)

/** Defines the value to set decimal base (itoa function)*/
#define DECIMAL_BASE | (10)

/** Defines the digital pin 0*/
#define DIG_0 | (0)

/** Defines the digital pin 1*/
#define DIG_1 | (1)

/** Defines the digital pin 2*/
#define DIG_2 | (2)

/** LED off state for pull-down*/
#define LED_OFF | (LOW)

/** LED on stat for pull-down*/
#define LED_ON | (HIGH)

/** Reference voltage for the ADC*/
#define V_REF | (3.3)

/** ADC resolution of the MKR GSM 1400*/
#define ADC_RES_BITS | (1023)

/** Resistor of the luminosity sensor*/ #define LIGHT_SENSOR_R (68000)
/** Value to define 1 micro A*/
#define uA_1 | (0.000001)

/** Defines a delay of 1 second*/
#define ONE_SEC_DELAY (1000)

/** Defines the time the publish LED will be on (ms)*/
#define PUB_LED_DELAY (2000)

/**************** DEFINES ***************************************************/

/**************** VARIABLES *************************************************/ /** Object for the I2C sensor*/
I2CSoilMoistureSensor sensor;

/** Analog pin for the light sensor*/
int light_pin = A1;
/** Variable for the light sensor reading*/ int light_read = 0;
/** Variable to calculate the luminosity*/ double light_calc = 0;

/** Variable for the humidity*/
int humidity = 0;
/** Variable for the temperature*/
int temperature = 0;
/** Variable to store light as an integer*/ int luminosity = 0;

/** Variable for the timestamp*/
unsigned long timestamp = 0;

/** LED for when de device is connected to GPRS*/ int gprs_led = DIG_0;
/** LED for when the device has published*/
int publish_led = DIG_1;
/** LED for when the device has connected to MQTT*/ int mqtt_led = DIG_2;

/** SIM pin*/
const char pin[] = "1111";

#if(TELCEL)

/** Telcel APN*/
const char apn[] = "internet.itelcel.com"; const char login[] = "webgprs";
const char password[] = "webgprs2002"; #elif(AT_T)
/** AT&T APN*/
const char apn[] = "modem.nexteldata.com.mx"; /** AT&T no tiene usuario ni contraseña para la APN utilizar NULL para ambos parámetros*/
#else

/** Movistar APN*/
const char apn[] = "internet.movistar.mx"; const char login[] = "movistar";
const char password[] = "movistar"; #endif

#if(MOSQUITTO_BRK)

/** Mosquitto server address*/
const char mqtt_server[] = "test.mosquitto.org";
#else

/** AWS server address*/
const char mqtt_server[] = "your-aws.broker.address.dom"; #endif

/** Variables to store the device's IMEI*/
String imei_str;
char IMEI[IMEI_SIZE] = {0};

/** MQTT topic into which the data will be published*/ const char topic[] = "/your/topic";

/** Array to store the message to be sent*/
char msg_to_be_sent[MSG_SIZE] = {0};
/** Buffer to construct the message and then send it*/ String msg_buff = "";
/** Length of the message to be sent*/
int msg_to_be_sent_len = 0;
/** Temporal buffer to convert from integers to ASCII*/ char temp_buff[TEMP_BUFF_SIZE] = {0};
/** Length of the content of the temporal buffer*/
int temp_buff_len = 0;

/** Password to encrypt temperature value*/
int temperature_pswd = 0x4D3;
/** Password to encrypt humidity value*/ int humidity_pswd = 0x6FA;
/** Password to encrypt luminosity value*/ int luminosity_pswd = 0xC37B8;

/** Counter for the XOR application*/ int xor_counter = 0;

/** JSON string for IMEI*/
const char imei_json[] = "{\"IMEI\":"; /** JSON string for timestamp*/
const char time_json[] = "\"timestamp\":"; /** JSON string for temperature*/
const char temp_json[] = "\"temp\":"; /** JSON string for humidity*/
const char hum_json[] = "\"hum\":"; /** JSON string for luminosity*/
const char lum_json[] = "\"lum\":"; /** Quotes character for JSON message*/ const char quotes[] = "\"";
/** Comma character for JSON message*/ const char comma[] = ",";
/** Closing braces for JSON message*/ const char eom[] = "}";

#if(SSL_EN)

/** Object for the SSL client*/

GSMSSLClient net_client;
/** Secure MQTT SSL client*/
PubSubClient mqttClient(mqtt_server, PORT, net_client);

#else

/** Object for the client (Not SSL)*/
GSMClient net_client;
/** Object for the MQTT client*/ MQTTClient client;

#endif

/** Object for security*/
GSMSecurity profile;
/** Object to access IMEI*/ GSMModem modem;
/** Object to attach to a network*/ GPRS gprs;
/** Object to acces the SIM*/
GSM gsmAccess;

/** Variable to keep count of time*/
unsigned long lastMillis = 0;
/**************** VARIABLES *************************************************/

/**************** CONNECT ***************************************************/ /** Connects to both cellular network, and MQTT server*/
void connect()
{
/** Connection state*/
bool connected = false;

Serial.print("\nconnecting to cellular network ...");

/** After starting the modem with gsmAccess.begin()
attach to the GPRS network with the APN, login and password */ while (!connected)
{
if ((gsmAccess.begin(pin) == GSM_READY) && (gprs.attachGPRS(apn, login, password) == GPRS_READY)) {
connected = true;
}

else
{
Serial.print(".");
delay(ONE_SEC_DELAY);
}
/** Repeats process until connected to network*/ }
/** Turns on connectivity LED*/ digitalWrite(gprs_led, LED_ON);

Serial.print("\nconnecting...");

/** Connects to the MQTT server*/ #if(SSL_EN)
while (!mqttClient.connect(IMEI)) #else
while (!client.connect(IMEI)) #endif
{
Serial.print(".");
delay(ONE_SEC_DELAY);
}

/** Turns on MQTT connection LED*/ digitalWrite(mqtt_led, LED_ON);

Serial.println("\nconnected!");
}
/**************** CONNECT ***************************************************/

/**************** SETUP *****************************************************/ /** Setup functions*/
void setup()
{
/** Initializes serial communication through USB*/ Serial.begin(SER_PORT_BR); Serial.print("Initialized\n");

/** Initializes the 3 LED pins*/ pinMode(gprs_led, OUTPUT); pinMode(publish_led, OUTPUT); pinMode(mqtt_led, OUTPUT);

/** Turns off the 3 LEDs*/ digitalWrite(gprs_led, LED_OFF); digitalWrite(publish_led, LED_OFF); digitalWrite(mqtt_led, LED_OFF);

#if(!SSL_EN)

/** Connects to MQTT broker*/ client.begin(mqtt_server, PORT, net_client); #endif
/** Initializes modem functions*/
modem.begin();

/** Gets the device's IMEI, and sets it to a char variable*/ imei_str = (modem.getIMEI());
imei_str.toCharArray(IMEI, sizeof(IMEI)); Serial.print(imei_str);

/** Initializes I2C for sensor reading*/ Wire.begin();
/** Initializes the I2C Soil Moisture sensor*/ sensor.begin();

/** Connects to cellular network and MQTT broker*/

connect();
}
/**************** SETUP *****************************************************/

/**************** LOOP ******************************************************/ /** Loop forever*/
void loop()
{
/** MQTT loop*/
client.loop();

/** If the device is disconnected, tries to connect again */
#if(SSL_EN)

if (!mqttClient.connected())
#else

if (!client.connected())
#endif

{
/** Turns off both MQTT and GPRS connection LEDs*/ digitalWrite(gprs_led, LED_OFF); digitalWrite(mqtt_led, LED_OFF);
connect();
}

/** Publish a message roughly every minute*/ if(DELAY_TIME < (millis() - lastMillis))
{
/** Gets current time*/
lastMillis = millis();

/** Gets the timestamp
The timestamp format for MKR GSM 1400 is the seconds passed since January 1st, 1970*/
timestamp = gsmAccess.getTime();

/** Reads the temperature*/
temperature = sensor.getTemperature();
/** Gives a small delay for the I2C buffer to respond*/ delay(I2C_DELAY);
/** Reads the humidity*/
humidity = sensor.getCapacitance();

/** Reads the light sensor*/
light_read = analogRead(light_pin);
/** Gets the voltage value read by the ADC*/
light_calc = ((double)(light_read) * V_REF) / (ADC_RES_BITS); /** Calculates the luminosity in Lux*/
light_calc = (light_calc / (10 * LIGHT_SENSOR_R * uA_1)); light_calc = pow(10, light_calc); Serial.println(light_calc);

/** Cast into integer to be sent by the device*/ luminosity = (int)(light_calc);

/** Pass the variables through the passwords*/ temperature ^= temperature_pswd;
humidity ^= humidity_pswd;
luminosity ^= luminosity_pswd;

#if(TEST_MSG)

msg_to_be_sent[0] = 'W';
msg_to_be_sent[1] = 'o';
msg_to_be_sent[2] = 'r';
msg_to_be_sent[3] = 'l';
msg_to_be_sent[4] = 'd';
msg_to_be_sent_len = 5;
#else

/** Erases string buffers*/
memset(msg_to_be_sent, '\0', sizeof(msg_to_be_sent));

/** Sets the first variable {"IMEI":"value"*/ strcat(msg_to_be_sent, imei_json); strcat(msg_to_be_sent, quotes); strcat(msg_to_be_sent, IMEI); strcat(msg_to_be_sent, quotes);

strcat(msg_to_be_sent, comma);

/** Sets the timestamp "timestamp":value*/ strcat(msg_to_be_sent, time_json); memset(temp_buff, '\0', sizeof(temp_buff)); itoa(timestamp, temp_buff, DECIMAL_BASE); strcat(msg_to_be_sent, temp_buff);

strcat(msg_to_be_sent, comma);

/** Sets the temperature "temp":value*/ strcat(msg_to_be_sent, temp_json); memset(temp_buff, '\0', sizeof(temp_buff)); itoa(temperature, temp_buff, DECIMAL_BASE); strcat(msg_to_be_sent, temp_buff);

strcat(msg_to_be_sent, comma);

/** Sets the humidity "hum":value*/ strcat(msg_to_be_sent, hum_json); memset(temp_buff, '\0', sizeof(temp_buff)); itoa(humidity, temp_buff, DECIMAL_BASE); strcat(msg_to_be_sent, temp_buff);

strcat(msg_to_be_sent, comma);

/** Sets the luminosity "lum":value*/ strcat(msg_to_be_sent, lum_json); memset(temp_buff, '\0', sizeof(temp_buff)); itoa(luminosity, temp_buff, DECIMAL_BASE); strcat(msg_to_be_sent, temp_buff);

strcat(msg_to_be_sent, eom);

/** Gets the string length*/ msg_to_be_sent_len = strlen(msg_to_be_sent); #endif

/** Publishes a message*/
#if(SSL_EN)

mqttClient.publish(topic, msg_to_be_sent, msg_to_be_sent_len); #else
client.publish(topic, msg_to_be_sent, msg_to_be_sent_len); #endif

/** Turns off the publish LED only for one second*/ digitalWrite(publish_led, LED_ON);
delay(PUB_LED_DELAY);
digitalWrite(publish_led, LED_OFF);

Serial.println("\nPublish!");
}
}
/**************** LOOP ******************************************************/

Script de comunicación entre Mosquitto y AWS:

import paho.mqtt.client as mqtt
import datetime
import json
import ssl
import logging, traceback
import sys
import time

# Port for Mosquitto connection PORT = 1883

# Port for AWS connection

SSL_PORT = 443

# Mosquitto broker address mosq_broker = "test.mosquitto.org"

# Mosquitto client ID (Random string) mosq_client_id = "e275e7835e404b4a7ca"

# ALPN protocol name (AWS) IoT_protocol_name = "x-amzn-mqtt-ca"

# AWS broker address

aws_broker = "aws.broker.example.com"
# AWS client ID (Configured in AWS policies) aws_client_id = "AWS_Client_ID_Example"

# CA certificate path

ca = "C:/your/path/to/cartificate/cert_name.pem"
# Client certificate path

cert = "C:/your/path/to/cartificate/cert_name.pem.crt" # Private Key path
private = "C:/your/path/to/key/key_name.pem.key"

# Variable to define if a message must be sent msg_ready = False

# Message to be sent

msg_to_be_sent = ""

# Topic to which the data will be published and received from topic = "/topic/to/publish/example"

# Callback for Mosquitto connection

def on_connect_mosq(client, userdata, flags, rc):
# Message to state a connection

print("Connected to Mosquitto with result code " + str(rc))

# Subscribe to Mosquitto topic to which the data will be

# published by Arduino

client.subscribe(topic)

# Callback for when a message is received from Mosquitto def on_message_mosq(client, userdata, msg):

global msg_ready
global msg_to_be_sent

# Sets the message to be sent as ready msg_ready = True

# Sets the message to be sent

msg_to_be_sent = msg.payload

# Sets the SSL configuration for a secure connection def ssl_alpn():

try:
# Creates an SSL context

ssl_context = ssl.create_default_context()
# Sets the AWS protocol for ALPN ssl_context.set_alpn_protocols([IoT_protocol_name]) # Sets the CA certificate

ssl_context.load_verify_locations(cafile = ca)
# Sets the client certificate and the private key ssl_context.load_cert_chain(certfile= cert, keyfile = private)

# Returns the SSL context to be configured into MQTT

return ssl_context

except Exception as e:
print("exception ssl_alpn()") raise e

if __name__ == '__main__':

try:
# Creates the Mosquitto MQTT aws_client mosq_client = mqtt.Client(mosq_client_id) # Sets the callbacks

mosq_client.on_connect = on_connect_mosq mosq_client.on_message = on_message_mosq

# Connects to Mosquitto

mosq_client.connect(mosq_broker, PORT)

# Creates the AWS MQTT client aws_client = mqtt.Client(aws_client_id) # Configures the SSL context

ssl_ctx = ssl_alpn()
# Sets the SSL context

aws_client.tls_set_context(context = ssl_ctx) # Connects to AWS
aws_client.connect(aws_broker, port = SSL_PORT)

# Starts both MQTT connections aws_client.loop_start()

print("Connected to AWS")
mosq_client.loop_start()

while True:

# When a message is received if True == msg_ready:

# Sets the message as sent

msg_ready = False
print("Publish")
# Publishes the message to Topic in AWS aws_client.publish(topic, msg_to_be_sent)

# Exception to exit at CTRL + C

except KeyboardInterrupt:
# Disconnects from both servers aws_client.disconnect()

print("Disconnected from AWS") mosq_client.disconnect()

print("Disconnected from Mosquitto")

print("END")

Código de función Lambda:

import json
import requests
import time
import boto3

# Ubidots access token

TOKEN = "your-ubidots-token"
# Ubidots stem address

address = "http://industrial.api.ubidots.com"

# Passwords to decrypt the message

temp_pswd = 0x4D3
hum_pswd = 0x6FA
lum_pswd = 0xC37B8

# Object to manage DynamoDB

dynamodb = boto3.resource('dynamodb') # Object to manage the table IoT_DB table = dynamodb.Table('IoT_DB')

# Posts via HTTP to ubidots

def post_request(payload, device_label):
# sets the address and the label to the URL

url = "{}/api/v1.6/devices/{}".format(address, device_label)
# Headers for the post request

headers = {"X-Auth-Token": TOKEN, "Content-Type": "application/json"}

# Status of the post request

status = 400
# Number of attempts to post

attempts = 0

# If the status is not successful, tries to post_request # 5 times

while status >= 400 and attempts <= 5:
# Post request

req = requests.post(url=url, headers=headers, json=payload) # Gets the request status

status = req.status_code
# Retries in 1 second

attempts += 1
time.sleep(1)

# If could not publish in 5 trues, returns error if status >= 400:

return False

# Otherwise, returns success return True

# Lambda function handler

def lambda_handler(event, context):
# Dictionary to be sent to Ubidots with error values msg_to_be_sent = {"temp":-1, "hum":-1, "lum":-1}

# Decrypts the messages

event["temp"] ^= temp_pswd
event["hum"] ^= hum_pswd
event["lum"] ^= lum_pswd

# Sets the dictionary to be sent to Ubidots msg_to_be_sent["temp"] = event["temp"] msg_to_be_sent["hum"] = event["hum"] msg_to_be_sent["lum"] = event["lum"]

# Puts data received into DynamoDB

table.put_item(Item = event)

# Publishes the message to ubidots via HTTP, to the proper device post_request(msg_to_be_sent, event["IMEI"])

# Return value

return {'statusCode': 200, 'body': json.dumps(msg_to_be_sent)}

Hojas de datos consultadas

I2C Soil Moisture Sensor: https://www.tindie.com/products/miceuz/i2c-soil-moisture-sensor/

SEN0114: https://datasheetspdf.com/pdf-file/770442/DFROBOT/SEN0114/1

SHT11: https://www.seeedstudio.com/Soil-Moisture-Temperature-Sensor-p-1356.html

LM35: http://www.ti.com/lit/ds/symlink/lm35.pdf?HQS=TI-null-null-mousermode-df-pf-null-wwe

MAX6627: https://www.mouser.mx/datasheet/2/256/MAX6627-MAX6628-370438.pdf

VEML7700: https://www.vishay.com/docs/84286/veml7700.pdf

APDS9007: https://docs.broadcom.com/doc/AV02-0512EN

GA1AS202WP: | https://pdf1.alldatasheet.com/datasheet-

pdf/view/582599/SHARP/GA1A1S202WP.html (https://pdf1.alldatasheet.com/datasheet-pdf/view/582599/SHARP/GA1A1S202WP.html)

Li-Yuan | Conductivity, | temperature | and | humidity:

https://es.aliexpress.com/item/32793236869.html

Arduino Conductivity Sensor:

http://vi.raptor.ebaydesc.com/ws/eBayISAPI.dll?ViewItemDescV4&item=132746823890&cate

gory=57520&pm=1&ds=0&t=1559965893000&ver=0 (http://vi.raptor.ebaydesc.com/ws/eBayISAPI.dll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)

Isolated EC probe: https://ufire.co/shop/

Arduino | Uno: | https://components101.com/microcontrollers/arduino-uno

https://store.arduino.cc/usa/arduino-uno-rev3

Arduino MKR FOX 1200: https://store.arduino.cc/usa/arduino-mkrfox1200

Arduino MKR GSM 1400: https://store.arduino.cc/usa/mkr-gsm-1400

NXP | FRDM-K64F: | https://www.mouser.com/datasheet/2/813/K64P144M120SF5RM-

1074828.pdf, (https://www.mouser.com/datasheet/2/813/K64P144M120SF5RM-1074828.pdf) https://os.mbed.com/media/uploads/GregC/frdm-k64f_ug_rev0.1.pdf

Referencias

(n.d.). Retrieved from http://www.infoagro.com/hortalizas/lechuga.htm

Zen | Cart® | Team. | (n.d.). | Guía: | La | luz | en | tus | plantas. | Retrieved | from

https://www.hydroenv.com.mx/catalogo/index.php?main_page=page&id=221

REVISTA DE CIENCIAS AGRÍCOLAS. (2014, November 11). PRODUCTIVIDAD DE

LECHUGA Lactuca sativa EN CONDICIONES DE MACROTÚNEL EN SUELO Vitric

haplustands | [Dataset]. | Retrieved | May | 21, | 2019, | from

http://www.scielo.org.co/pdf/rcia/v31n2/v31n2a08.pdf

Seminis. (2017). Que es la cenicilla polvorienta. abril 20, 2020, de Seminis Sitio web:

https://www.seminis.mx/blog-que-es-la-cenicilla-polvorienta/

Gosálbez, C.. (2012). ¿Cómo combato la mosca blanca?. abril 20, 2020, de Planeta Huerto

Sitio web: https://www.planetahuerto.es/revista/como-combato-la-mosca-blanca_00107

Casanova, M. (2017). ¿Qué es LoRa? Marzo 13, 2020, de Alfa IoT Sitio web:

https://alfaiot.com/blog/ultimas-noticias-2/post/que-es-lora-2

García, C. (2012). Zigbee, Comunicación para Dispositivos. Marzo 13, 2020, de SG Sitio web:

https://sg.com.mx/content/view/310

Ferrer, V. (2019). Qué es Sigfox. Marzo 13, 2020, de Vicente Ferrer Sitio web:

https://vicentferrer.com/sigfox/

Munera, S. (2019). Modelado y evaluación de la tecnología Sigfox para NS3. (Tesis Ingeniería

Informática). Marzo 13, 2020. Sitio web:

https://pdfs.semanticscholar.org/a425/374d9b01f457c5f448247af9b7428e05febe.pdf

Villagómez, C. (2018). Introducción a wifi (802.11 o WiFi). Marzo 13, 2020, de CMM Sitio web:

https://es.ccm.net/contents/789-introduccion-a-wifi-802-11-o-wifi

Buchanan, B. (2019). So what is the encryption in 3G/4G networks?. Marzo 13, 2020, de

Medium | Sitio web: | https://medium.com/asecuritysite-when-bob-met-alice/so-what-is-the-

encryption-in-3g-4g-networks-139b8c0da3eb (https://medium.com/asecuritysite-when-bob-met-alice/so-what-is-the-encryption-in-3g-4g-networks-139b8c0da3eb)

Kroodo, M. (2019). 2G / 3G / 4G / 5G / LPWAN – Which to Choose for Your IoT Project?. Marzo

13, 2020, de 1oT Sitio web: https://1ot.mobi/resources/blog/gsm-3g-4g-lte-which-one-to-

choose-for-your-iot-project?gclid=Cj0KCQjw6sHzBRCbARIsAF8FMpWvagfQZ-9xAXuXuw-

kQYQ--0R_Y7GuCW4r-eOfSl0XPxCtXnD-BsUaAlX-EALw_wcB (https://1ot.mobi/resources/blog/gsm-3g-4g-lte-which-one-to-choose-for-your-iot-project)

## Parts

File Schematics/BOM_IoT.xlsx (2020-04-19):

Item | Schematic reference | Qty | Price per unit (USD) | Total price (USD) | Price per 10 pcs, per unit (USD) | Total price per 10 pcs (USD) | Decription | Value | Package | Manufacturer part number | Manufacturer | Distributor | Link | Notas
1 | C1 | 1 | $0.63 | $0.63 | $0.25 | $2.48 | CAP CER 1000V 4.7nF 10% 0805 | 4.7 nF | 0805 | C0805C472KDRACTU | KEMET | Mouser | https://www.mouser.mx/ProductDetail/KEMET/C0805C472KDRACTU
2 | C2, C6, C8, C9, C17, C18, C23, C24, C29, C32, C3, C36 | 12 | $0.16 | $1.87 | $0.25 | $29.76 | CAP CER 50V 100nF 10% 0402 | 100 nF | 0402 | C1005X5R1H104K050BB | TDK | Mouser | https://www.mouser.mx/ProductDetail/TDK/C1005X5R1H104K050BB
3 | C3, C4 | 2 | $0.25 | $0.49 | $0.18 | $3.58 | CAP CER 50V 20pF 5% 0402 | 20 pF | 0402 | CBR04C200J5GAC | KEMET | Mouser | https://www.mouser.mx/ProductDetail/KEMET/CBR04C200J5GAC
4 | C10, C30 | 2 | $0.13 | $0.26 | $0.05 | $1.02 | CAP CER 50V 15pF 5% 0402 | 15 pF | 0402 | GRM1555C1H150JA01D | Murata | Mouser | https://www.mouser.mx/ProductDetail/Murata-Electronics/GRM1555C1H150JA01D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 | Revisar tiempos de entrega. Comprar con anticipación
5 | C11 | 1 | $0.13 | $0.13 | $0.03 | $0.27 | CAP CER 50V 33pF 5% 0402 | 33 pF | 0402 | GRM1555C1H330JA01D | Murata | Mouser | https://www.mouser.mx/ProductDetail/Murata-Electronics/GRM1555C1H330JA01D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 | Revisar tiempos de entrega. Comprar con anticipación
6 | C12, C13, C19, C20 | 4 | $0.56 | $2.24 | $0.39 | $15.56 | CAP CER 16V 10uF 10% 0603 | 10 uF | 0603 | GRM188R61C106KAALD | Murata | Mouser | https://www.mouser.mx/ProductDetail/Murata-Electronics/GRM188R61C106KAALD
7 | C14, C22, C25, C26 | 4 | $0.13 | $0.52 | $0.09 | $3.64 | CAP CER 25V 1uF 10% 0402 | 1 uF | 0402 | GRM155R61E105KA12D | Murata | Mouser | https://www.mouser.mx/ProductDetail/Murata-Electronics/GRM155R61E105KA12D
8 | C15 | 1 | $0.13 | $0.13 | $0.08 | $0.82 | CAP CER 25V 47nF 10% 0402 | 47 nF | 0402 | GRM155R71E473KA88D | Murata | Mouser | https://www.mouser.mx/ProductDetail/Murata-Electronics/GRM155R71E473KA88D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
9 | C16 | 1 | $0.20 | $0.20 | $0.15 | $1.48 | CAP CER 6.3V 4.7uF 20% 0402 | 4.7 uF | 0402 | GRM155R60J475ME47D | Murata | Mouser | https://www.mouser.mx/ProductDetail/Murata-Electronics/GRM155R60J475ME47D
10 | C27 | 1 | $0.53 | $0.53 | $0.37 | $3.69 | CAP CER 25V 4.7uF 10% 0603 | 4.7 uF | 0603 | GRM188R61E475KE11D | Murata | Mouser | https://www.mouser.mx/ProductDetail/Murata-Electronics/GRM188R61E475KE11D
11 | C28 | 1 | $0.13 | $0.13 | $0.05 | $0.49 | CAP CER 50V 10nF 10% 0402 | 10 nF | 0402 | GRM155R71H103KA88J | Murata | Mouser | https://www.mouser.mx/ProductDetail/Murata-Electronics/GRM155R71H103KA88J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
12 | C21, C33, C34 | 3 | $0.99 | $2.97 | $0.73 | $21.87 | CAP CER 6.3V 100uF 20% 1206 | 100 uF | 1206 | GRM31CD80J107ME39L | Murata | Mouser | https://www.mouser.mx/ProductDetail/Murata-Electronics/GRM31CD80J107ME39L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
13 | C37 | 1 | $0.13 | $0.13 | $0.03 | $0.26 | CAP CER 25V 56pF 5% 0402 | 56 pF | 0402 | GRM1555C1E560JA01D | Murata | Mouser | https://www.mouser.mx/ProductDetail/Murata-Electronics/GRM1555C1E560JA01D
14 | D1 | 1 | $0.66 | $0.66 | $0.55 | $5.45 | DIO 5.5V ESD PROTECTION SOT143 | PRTR5V | SOT-143 | PRTR5V0U2X,215 | Nexperia | Mouser | https://www.mouser.mx/ProductDetail/Nexperia/PRTR5V0U2X215?qs=sGAEpiMZZMvKM5ialpXrmha212gV%252BN%252Bb
15 | D2, D3 | 2 | $0.59 | $1.18 | $0.40 | $8.00 | DIO RECT 60V 2A SOD123 | PMEG6020 | SOD-123 | PMEG6020AELRX | Nexperia | Mouser | https://www.mouser.mx/ProductDetail/Nexperia/PMEG6020AELRX
16 | D4, D5, D6 | 3 | $0.66 | $1.98 | $0.54 | $16.26 | DIO 14V 0402 | PESD0402 | 0402 | PESD0402-140 | Littelfuse | Mouser | https://www.mouser.mx/ProductDetail/Littelfuse/PESD0402-140
17 | DL1 | 1 | $0.53 | $0.53 | $0.37 | $3.74 | LED YELLOW 2.1V 20mA 0603 | Yellow | 0603 | HSMY-C190 | Broadcom | Mouser | https://www.mouser.mx/ProductDetail/Broadcom-Avago/HSMY-C190
18 | DL2 | 1 | $0.53 | $0.53 | $0.37 | $3.74 | LED ORANGE 2.1V 20mA 0603 | Orange | 0603 | HSMD-C190 | Broadcom | Mouser | https://www.mouser.mx/ProductDetail/Broadcom-Avago/HSMD-C190
19 | DL3, PUBLISH | 2 | $0.53 | $1.06 | $0.37 | $7.48 | LED GREEN 2.1V 20mA 0603 | Green | 0603 | HSMG-C190 | Broadcom | Mouser | https://www.mouser.mx/ProductDetail/Broadcom-Avago/HSMG-C190
20 | GSM_CN | 1 | $0.82 | $0.82 | $0.37 | $3.74 | LED AMBER 1.9V 20mA 0603 | Amber | 0603 | HSMA-C191-T0000 | Broadcom | Mouser | https://www.mouser.mx/ProductDetail/Broadcom-Avago/HSMA-C191-T0000
21 | J1 | 1 | $1.04 | $1.04 | $0.83 | $8.28 | USB MICRO AB RECP | NA | SMT | ZX62-AB-5PA | Hirose | Mouser | https://www.mouser.mx/ProductDetail/Hirose-Connector/ZX62-AB-5PA31
22 | J6 | 1 | $1.43 | $1.43 | $1.13 | $11.30 | RF MALE SMT UFL | NA | SMT | U.FL-R-SMT-1(60) | Hirose | Mouser | https://www.mouser.mx/ProductDetail/Hirose-Connector/UFL-R-SMT-160
23 | J7 | 1 | $0.58 | $0.58 | $0.55 | $5.47 | BATT MALE CONN 2 POS | NA | SMT | S2B-PH-SM4-TB | JST | Digi-Key | https://www.digikey.com.mx/product-detail/es/jst-sales-america-inc/S2B-PH-SM4-TB-LF-SN/455-1749-1-ND/926846
24 | L1 | 1 | $0.13 | $0.13 | $0.09 | $0.86 | IND 200 mA 39nH 0402 | 39 nH | 0402 | LQG15HN39NJ02D | Murata | Mouser | https://www.mouser.mx/ProductDetail/Murata-Electronics/LQG15HN39NJ02D
25 | L2 | 1 | $0.70 | $0.70 | $0.70 | $7.02 | IND 6A 2.2uH 4020 | 2.2 uH | 4020 | SRP4020TA-2R2M | Bourns | Mouser | https://www.mouser.mx/ProductDetail/Bourns/SRP4020TA-2R2M
26 | L3, L4 | 2 | $0.13 | $0.26 | $0.07 | $1.30 | FERR 1A 470Ohm 0603 | 470 Ohm | 0603 | BLM18PG471SN1D | Murata | Mouser | https://www.mouser.mx/ProductDetail/Murata-Electronics/BLM18PG471SN1D
27 | MQTT_CON | 1 | $1.00 | $1.00 | $0.64 | $6.41 | LED RED 3.4V 20mA 0603 | Red | 0603 | HSMG-C190 | Broadcom | Mouser | https://www.mouser.mx/ProductDetail/Broadcom-Avago/HSMR-C190
28 | PB1 | 1 | $0.60 | $0.60 | $0.58 | $5.81 | PUSH BUTTON | NA | SMT | PTS820J25KSMTRLFS | C&K | Mouser | https://www.mouser.mx/ProductDetail/CK/PTS820J25KSMTRLFS?qs=sGAEpiMZZMsgGjVA3toVBGTSKfeK9LPKMi50kEjnltE%3D
29 | Q1, Q3 | 2 | $0.52 | $1.04 | $0.34 | $6.76 | MOSFET 60V 150mW SOT523 | NA | SOT523 | 2N7002T-7-F | Diodes Inc. | Mouser | https://www.mouser.mx/ProductDetail/Diodes-Incorporated/2N7002T-7-F
30 | Q2 | 1 | $0.65 | $0.65 | $0.53 | $5.28 | MOSFET 30V 12V | NA | SMT | SIA817EDJ-T1-GE3CT-ND | Vishay | Mouser | https://www.mouser.mx/ProductDetail/Vishay-Semiconductors/SIA817EDJ-T1-GE3
31 | Q5 | 1 | $0.39 | $0.39 | $0.17 | $1.68 | MOSFET 60V 200mW | NA | SMT | 2N7002DW-7-F | Diodes Inc. | Mouser | https://www.mouser.mx/ProductDetail/Diodes-Incorporated/2N7002DW-7-F
32 | R1 | 1 | $0.10 | $0.10 | $0.02 | $0.16 | RES 1/16W 1MOhm 1% 0402 | 1 Mohm | 0402 | RC0402FR-071ML | Yaego | Digi-Key | https://www.digikey.com.mx/product-detail/es/yageo/RC0402FR-071ML/311-1-00MLRCT-ND/729462
33 | R2, R4, R6 | 3 | $0.13 | $0.39 | $0.02 | $0.48 | RES 1/16W 1kOhm 1% 0402 | 1 kOhm | 0402 | RC0402FR-071KL | Yaego | Mouser | https://www.mouser.mx/ProductDetail/Yageo/RC0402FR-071KL
34 | R3, R15, R23 | 3 | $0.13 | $0.39 | $0.02 | $0.48 | RES 1/16W 330Ohm 1% 0403 | 330 Ohm | 0402 | RC0402FR-07330RL | Yaego | Mouser | https://www.mouser.mx/ProductDetail/Yageo/RC0402FR-07330RL
35 | R5, R21, R24, R25, R26, R29, R31 | 7 | $0.13 | $0.91 | $0.02 | $1.19 | RES 1/16W 10kOhm 1% 0402 | 10 kOhm | 0402 | RC0402FR-0710KL | Yaego | Mouser | https://www.mouser.mx/ProductDetail/Yageo/RC0402FR-0710KL
36 | R7, R17, R18 | 3 | $0.00 | $0.00 | $0.00 | $0.00 | RES DNP | DNP | 0402 | DNP | DNP | DNP | DNP | DNP = Do not populate
37 | R8 | 1 | $0.13 | $0.13 | $0.01 | $0.13 | RES 1/16W 330kOhm 5% 0402 | 330 kOhm | 0402 | RC0402JR-07330KL | Yaego | Mouser | https://www.mouser.mx/ProductDetail/Yageo/RC0402JR-07330KL
38 | R9 | 1 | $0.13 | $0.13 | $0.02 | $0.16 | RES 1/16W 1.2MOhm 1% 0402 | 1.2 Mohm | 0402 | RC0402FR-071M2L | Yaego | Mouser | https://www.mouser.mx/ProductDetail/Yageo/RC0402FR-071M2L
39 | R10, R12, R16, R19 | 4 | $0.13 | $0.52 | $0.02 | $0.64 | RES 1/16W 100kOhm 1% 0402 | 100 kOhm | 0402 | RC0402FR-07100KL | Yaego | Mouser | https://www.mouser.mx/ProductDetail/Yageo/RC0402FR-07100KL
40 | R11, R33 | 2 | $0.13 | $0.26 | $0.01 | $0.26 | RES 1/16W 0Ohm 1% 0402 | 0 Ohm | 0402 | RC0402FR-070RL | Yaego | Mouser | https://www.mouser.mx/ProductDetail/Yageo/RC0402FR-070RL
41 | R13, R14 | 2 | $0.13 | $0.26 | $0.02 | $0.32 | RES 1/16W 4.7kOhm 1% 0402 | 4.7 kOhm | 0402 | RC0402FR-074K7L | Yaego | Mouser | https://www.mouser.mx/ProductDetail/Yageo/RC0402FR-074K7L
42 | R27 | 1 | $0.13 | $0.13 | $0.02 | $0.16 | RES 1/16W 390Ohm 1% 0402 | 390 Ohm | 0402 | RC0402FR-07390RL | Yaego | Mouser | https://www.mouser.mx/ProductDetail/Yageo/RC0402FR-07390RL
43 | R28 | 1 | $0.13 | $0.13 | $0.05 | $0.51 | RES 1/16W 220Ohm 1% 0402 | 220 Ohm | 0402 | CRCW0402220RFKED | Vishay | Mouser | https://www.mouser.mx/ProductDetail/Vishay-Dale/CRCW0402220RFKED
44 | R30 | 1 | $0.13 | $0.13 | $0.02 | $0.16 | RES 1/16W 5.49kOhm 1% 0402 | 5.49 kOhm | 0402 | RC0402FR-075K49L | Yaego | Mouser | https://www.mouser.mx/ProductDetail/Yageo/RC0402FR-075K49L
45 | SIM1 | 1 | $2.24 | $2.24 | $1.98 | $19.80 | MICRO SIM 8 CONTACT 1 ROW | NA | SMT | 2199337-5 | TE connectivity | Mouser | https://www.mouser.mx/ProductDetail/TE-Connectivity/2199337-5
46 | U1 | 1 | $3.90 | $3.90 | $3.54 | $35.40 | ARM MCU 256KB 32KB 48QFN 48MHz | NA | 48QFN | ATSAMD21G18A-MU | Microchip | Mouser | https://www.mouser.mx/ProductDetail/Microchip-Technology/ATSAMD21G18A-MU
47 | U2, U7 | 2 | $1.56 | $3.12 | $1.33 | $26.60 | 4B DUAL SUPPLY BUS | NA | UQFN-16 | SN74AVC4T774RSVR | Texas Instruments | Mouser | https://www.mouser.mx/ProductDetail/Texas-Instruments/SN74AVC4T774RSVR
48 | U3 | 1 | $61.44 | $61.44 | $46.08 | $460.80 | GSM CELLULAR MODULE 96-SMD | NA | 96-SMD | SARA-U201 | U-Blox | Digi-Key | https://www.digikey.com.mx/product-detail/es/u-blox/SARA-U201-03B-00/672-SARA-U201-03B-00CT-ND/6150684
49 | U5 | 1 | $4.17 | $4.17 | $3.65 | $36.50 | I2C BATTERY CONTROLLER VQFN-24 | NA | VQFN-24 | BQ24195LRGET | Texas Instruments | Mouser | https://www.mouser.mx/ProductDetail/Texas-Instruments/BQ24195LRGET
50 | U6 | 1 | $0.69 | $0.69 | $0.56 | $5.64 | VOLTAGE REGULATOR 3.3V 0.6A SOT89 | NA | SOT89 | AP7215-33YG-13 | Diodes Inc. | Mouser | https://www.mouser.mx/ProductDetail/Diodes-Incorporated/AP7215-33YG-13
51 | Y1 | 1 | $0.92 | $0.92 | $0.77 | $7.68 | XTAL 32.768kHz | 32.768 kHz | SMT | ABS07-32.768KHZ-T | Abracon | Mouser | https://www.mouser.mx/ProductDetail/ABRACON/ABS07-32768KHZ-T
52 | ANT | 1 | $5.71 | $5.71 | $5.71 | $57.10 | 2G/3G/4G/5G ANTENNA UFL | NA | SMT | X000016 | Arduino | Mouser | https://www.mouser.mx/ProductDetail/485-X000016
53 | BATTERY | 1 | $14.95 | $14.95 | $14.95 | $149.50 | Li-Po BATTERY 2pin JST-PH 2500mAH | 2500 mAH | 2 pin JST-PH | 328 | Adafruit | Digi-Key | https://www.digikey.com/products/en?mpart=328&v=1528 | Revisar tiempos de entrega. Comprar con anticipación
 |  |  | Total price: | $125.44 | Price per 10 units | $997.17
 |  |  |  |  | Per device | $99.72

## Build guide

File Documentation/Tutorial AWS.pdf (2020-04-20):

## Instituto Tecnológico y de Estudios

## Superiores de Occidente – ITESO


Seguridad

Materia: | Internet of Things
Maestro: | Héctor Edmundo Ramírez Gómez
Fecha: | 20 de abril de 2020
Autor: | Arpio Fernández, León. IE702086

Índice

Objetivos

El objetivo de este documento es el de mostrar paso a paso como configurar IoT Core de AWS

para que un dispositivo pueda publicar por MQTT, como configurar una función Lambda y

generar un deploy package, y como configurar Dynamo DB.

Lambda

Lo primero que hay que hacer, es crear una cuenta en AWS, siguiendo cuidadosamente los

pasos, agregando un número de teléfono, un método de pago, y asegurándose de que este

sea correcto, para poder acceder a las funciones de AWS.

Una vez dentro de la plataforma, en la pestaña de Servicios, buscar Lambda.

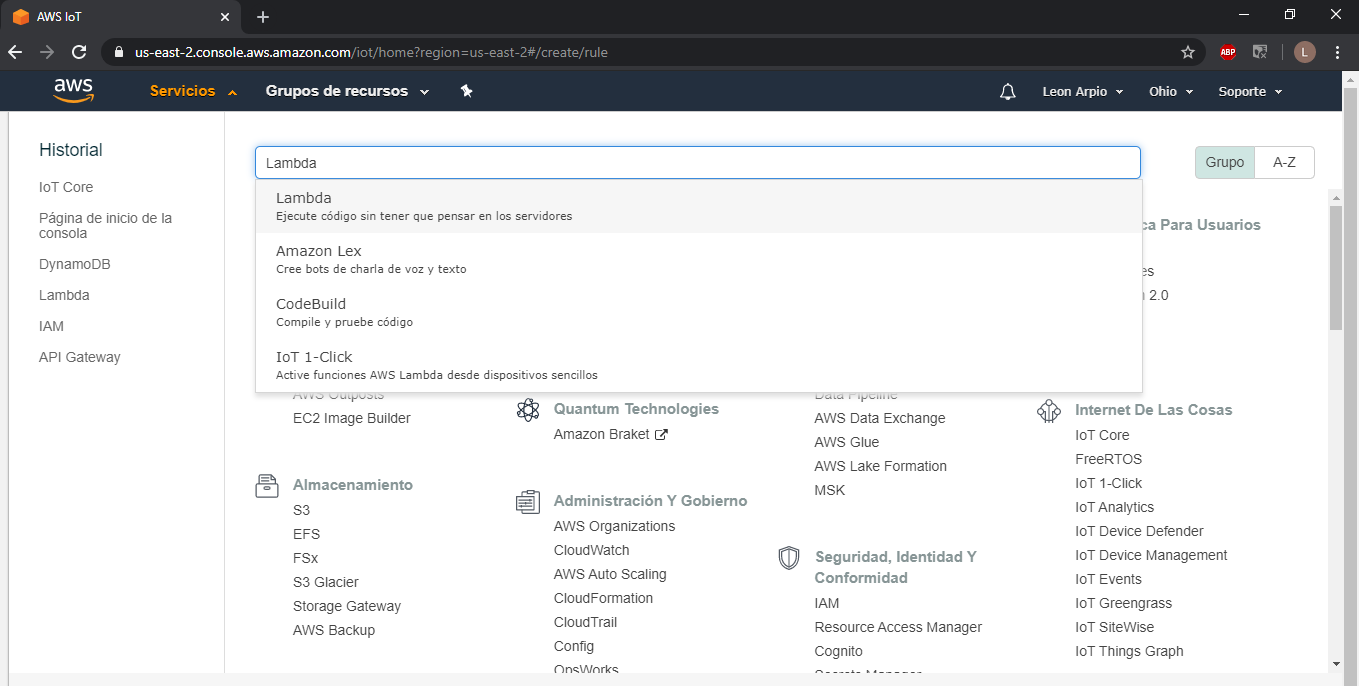
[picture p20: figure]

En la pestaña que se abre, presionar Crear una función

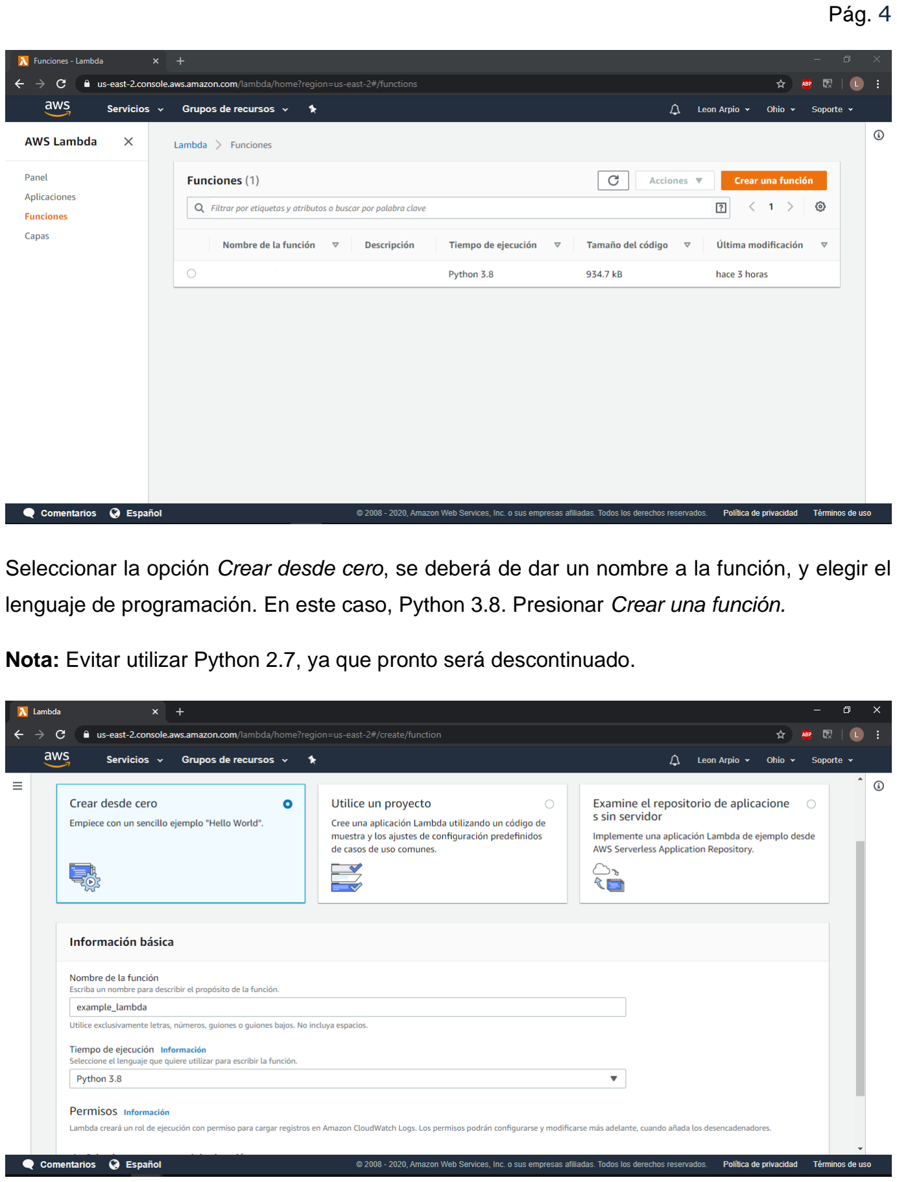
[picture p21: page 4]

Seleccionar la opción Crear desde cero, se deberá de dar un nombre a la función, y elegir el

lenguaje de programación. En este caso, Python 3.8. Presionar Crear una función.

Nota: Evitar utilizar Python 2.7, ya que pronto será descontinuado.

Aparecerá una ventana donde se podrá programar la Lambda, aquí también se puede elegir

un archivo .zip del ordenador que contenga un deploy package, el cual tiene tanto la función

Lambda, como las librerías necesarias para que se ejecute. Para instalar una librería de Python

en una carpeta en específico, abrir la ventana de comandos en la carpeta donde se encuentra

el deploy package y ejecutar el siguiente comando.

pip install my-library -t .

Esto instalará la librería my-library en la carpeta actual. Comprimir la carpeta, y en AWS

seleccionar la opción Cargar un archivo .zip.

Nota: Si no necesitas una librería no soportada por AWS, puedes editar el código en línea sin

mayor problema.

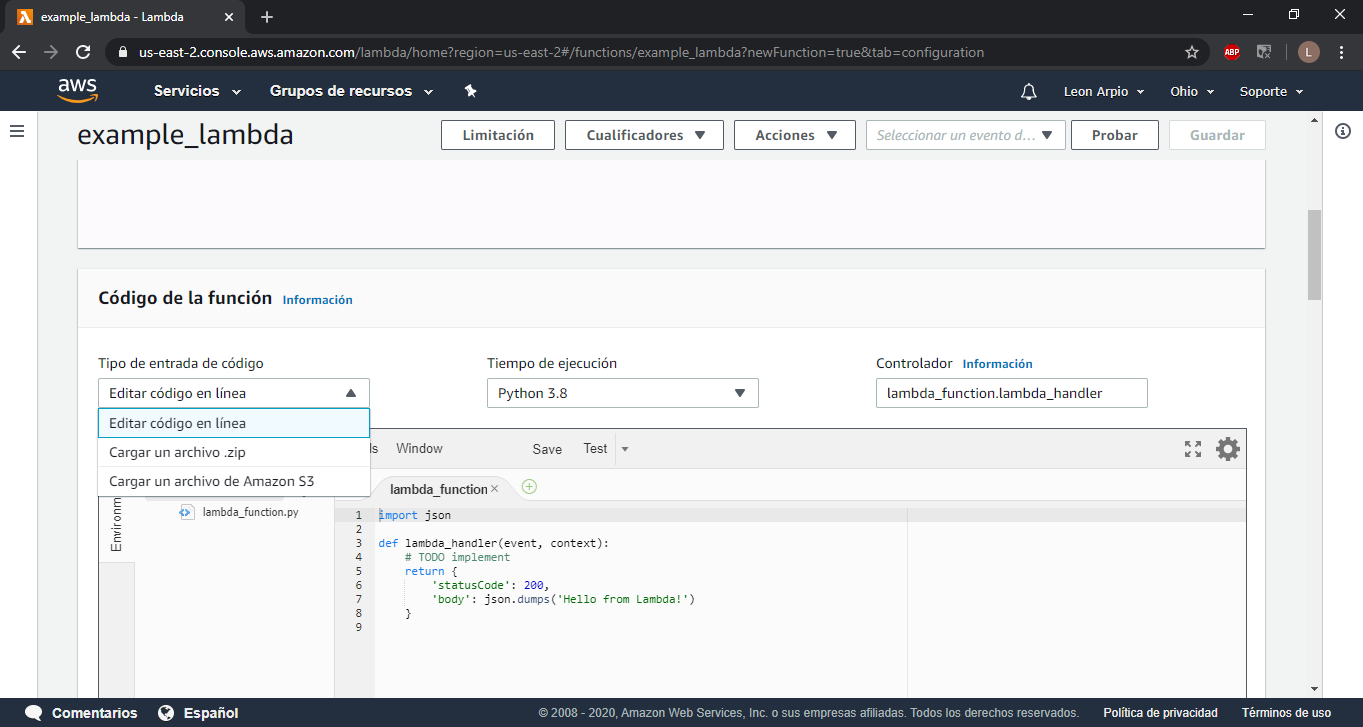
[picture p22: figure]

Presionar Cargar y seleccionar el archivo .zip que se generó. Cuando finalice la carga del

archivo, presionar Guardar.

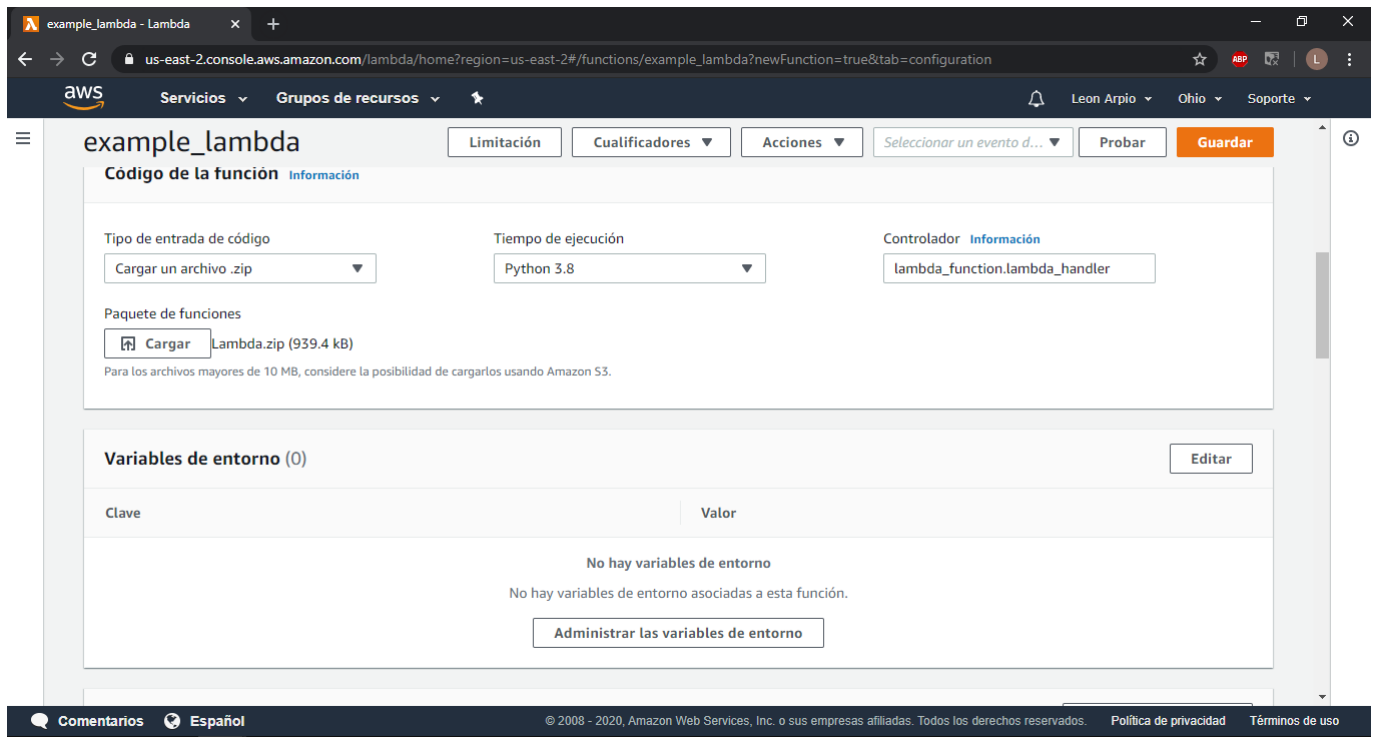
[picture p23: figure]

Ahora puedes seguir editando el código en línea, y hacer pruebas. Lambda recibe como

argumento event el cual contiene el mensaje que fue recibido por MQTT en la forma de un

diccionario.

Nota: Toda la información recibida por Lambda debe ser en formato JSON válido.

Para probar la función, seleccionar Probar, y se abrirá una ventana en la cual podrás configurar

el diccionario que llegará a event. Dar un nombre y los valores deseados, y presionar Crear.

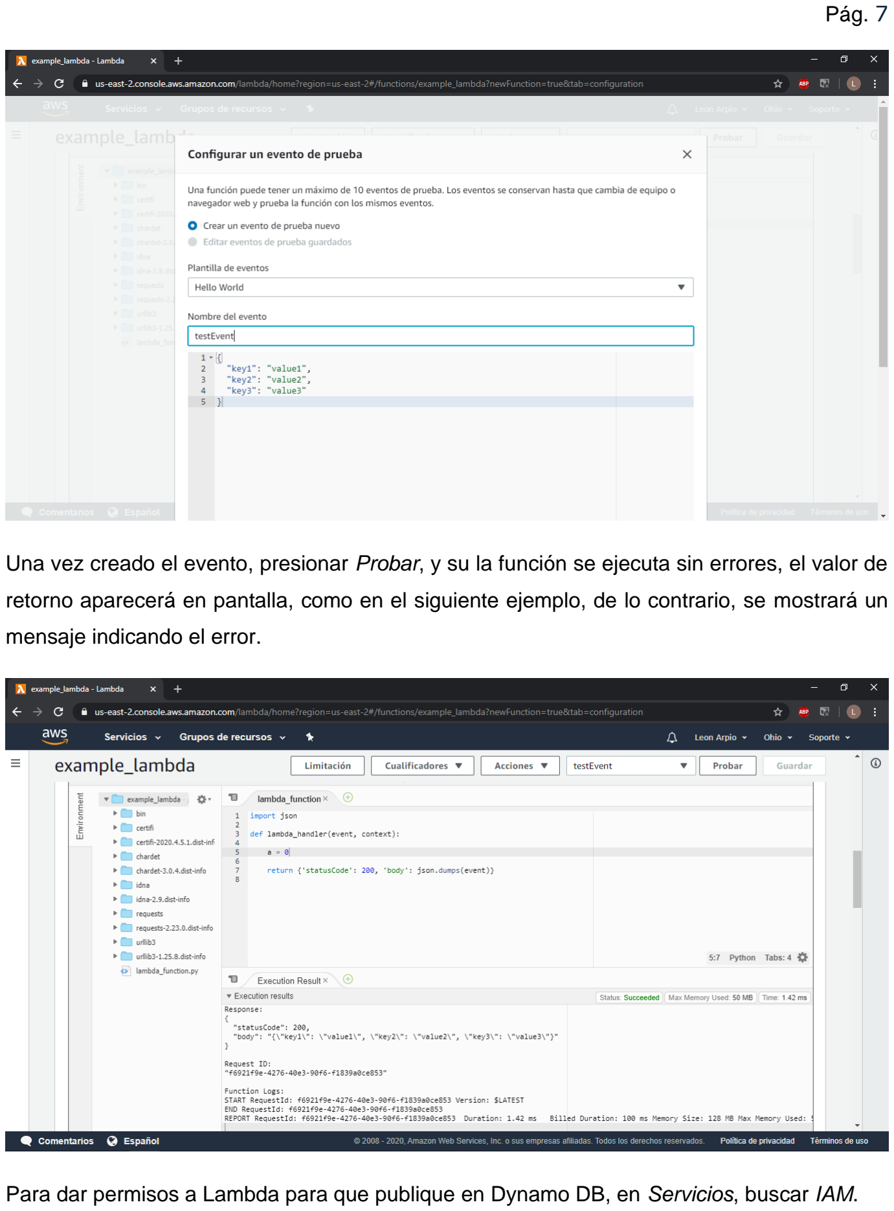
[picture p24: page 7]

Una vez creado el evento, presionar Probar, y su la función se ejecuta sin errores, el valor de

retorno aparecerá en pantalla, como en el siguiente ejemplo, de lo contrario, se mostrará un

mensaje indicando el error.

Para dar permisos a Lambda para que publique en Dynamo DB, en Servicios, buscar IAM.

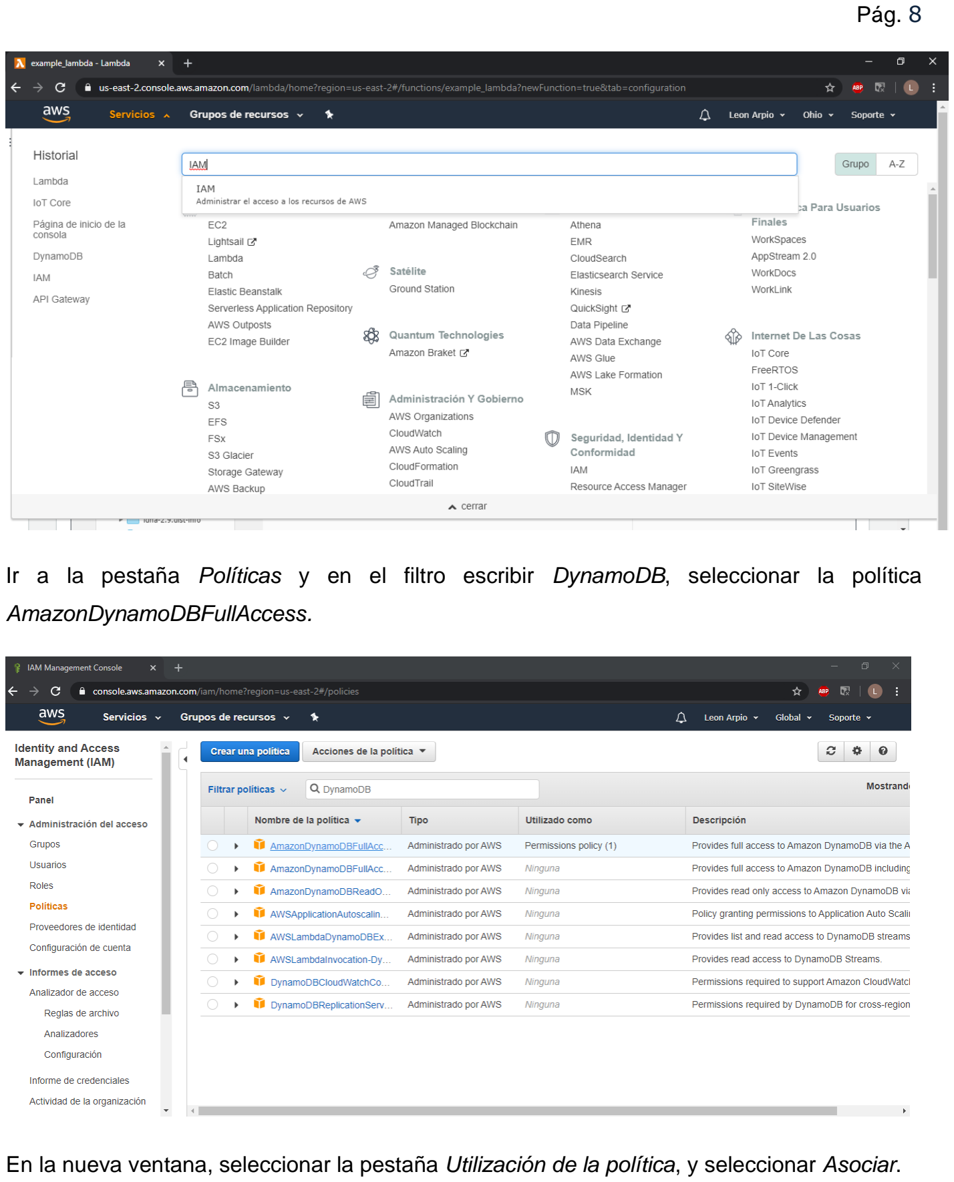
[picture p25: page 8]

Ir a la pestaña Políticas y en el filtro escribir DynamoDB, seleccionar la política

AmazonDynamoDBFullAccess.

En la nueva ventana, seleccionar la pestaña Utilización de la política, y seleccionar Asociar.

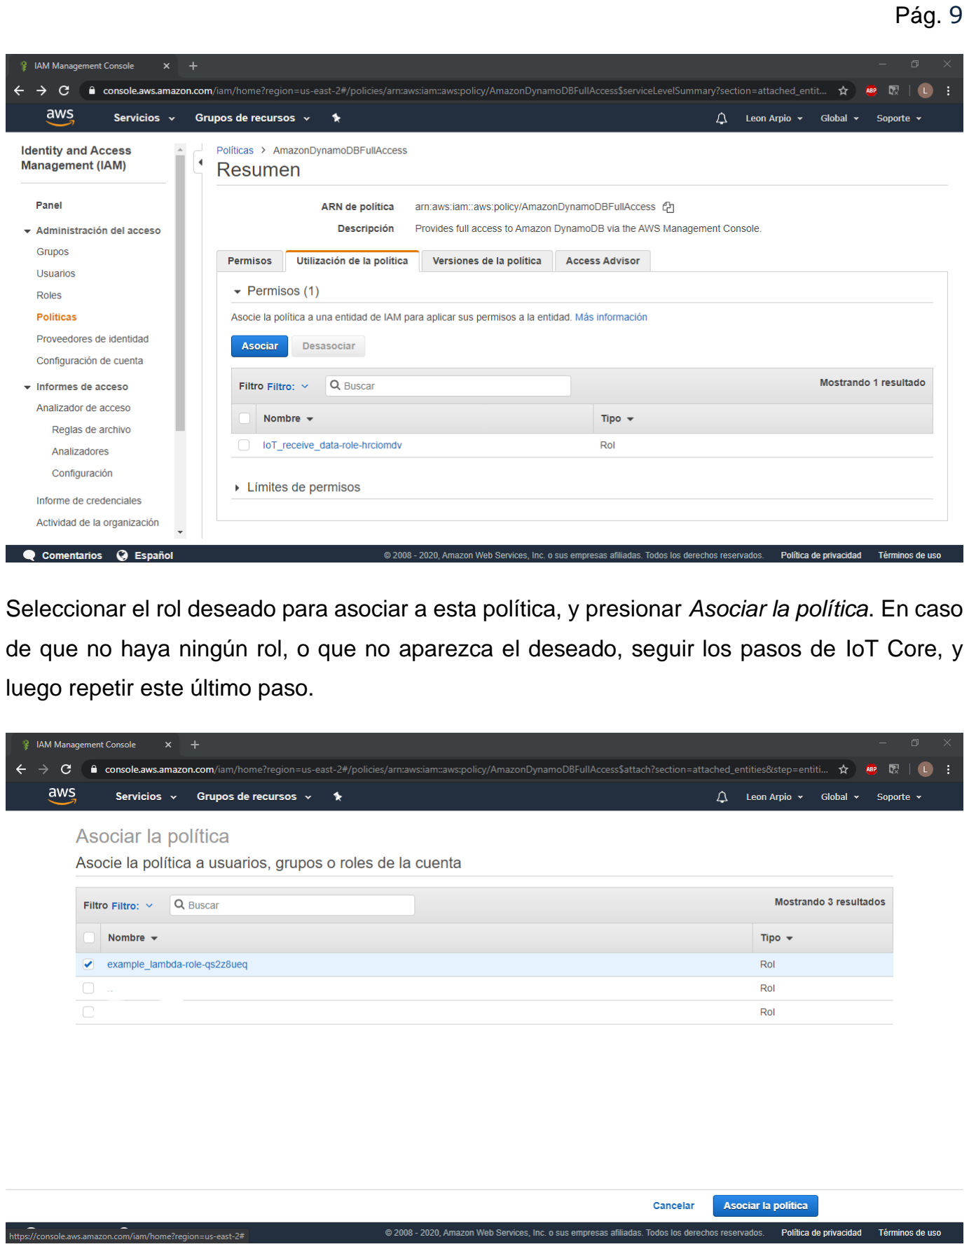
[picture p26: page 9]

Seleccionar el rol deseado para asociar a esta política, y presionar Asociar la política. En caso

de que no haya ningún rol, o que no aparezca el deseado, seguir los pasos de IoT Core, y

luego repetir este último paso.

IoT Core

En la pestaña de Servicios, buscar IoT Core.

Crear una política

Las políticas permiten o prohíben a los dispositivos conectarse, publicar, subscribirse, recibir

mensajes de un tópico, y otras acciones. Ir a Seguro>Políticas, en la ventana del lado izquierdo

de AWS, y elegir Crear.

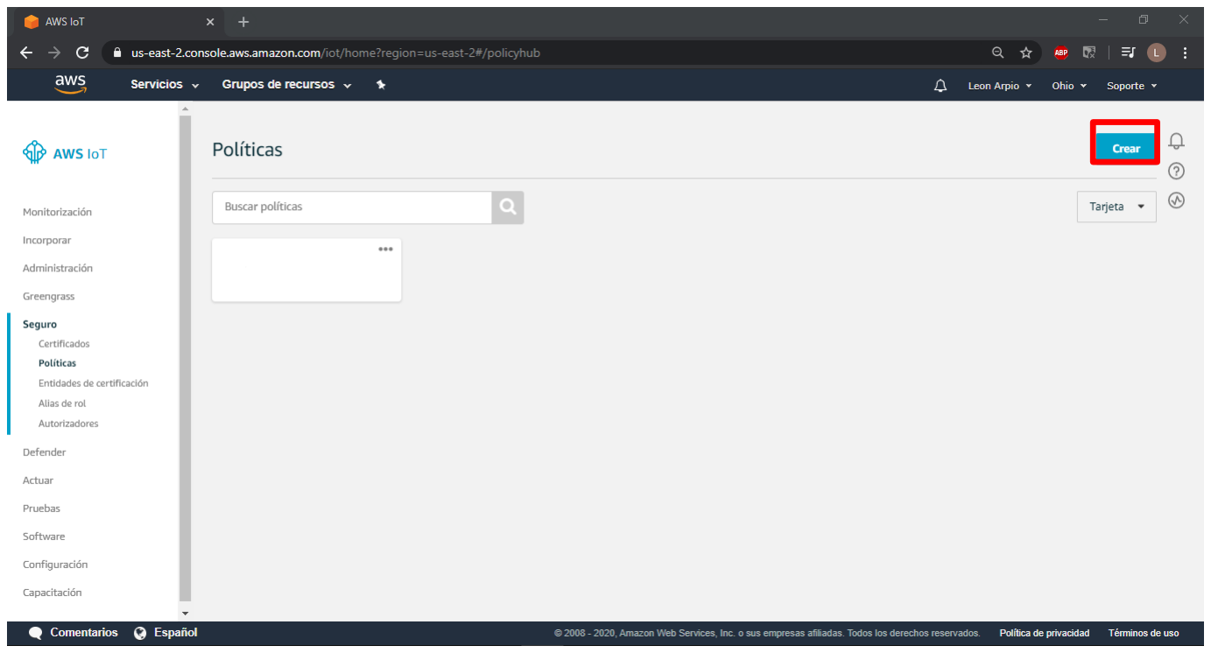
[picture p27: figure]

En esta ventana se solicitará un nombre para la política, y se deberá añadir declaraciones.

Una declaración es una configuración en la que se definirá si permitir o denegar una acción.

Por ejemplo, si permitir que un dispositivo se conecte, o permitir que este se subscriba y reciba

de un tópico, o denegar que publique en algún tópico. Se deberá de añadir cada una de estas

acciones, con su respectivo efecto por separado. Para agregar varios dispositivos o tópicos a

una sola declaración, utilizar una coma para cada ARN (Amazon Resource Number). Al

finalizar de definir las declaraciones, presionar Crear.

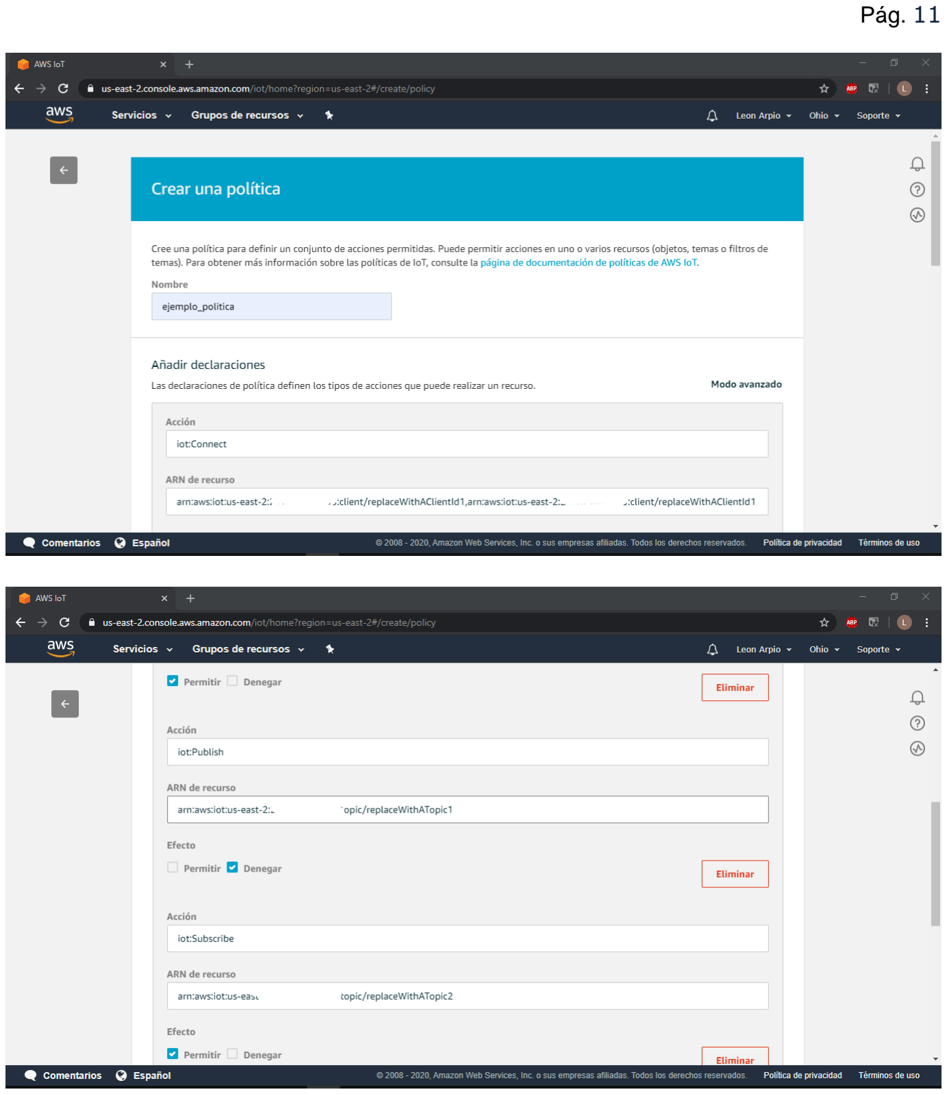
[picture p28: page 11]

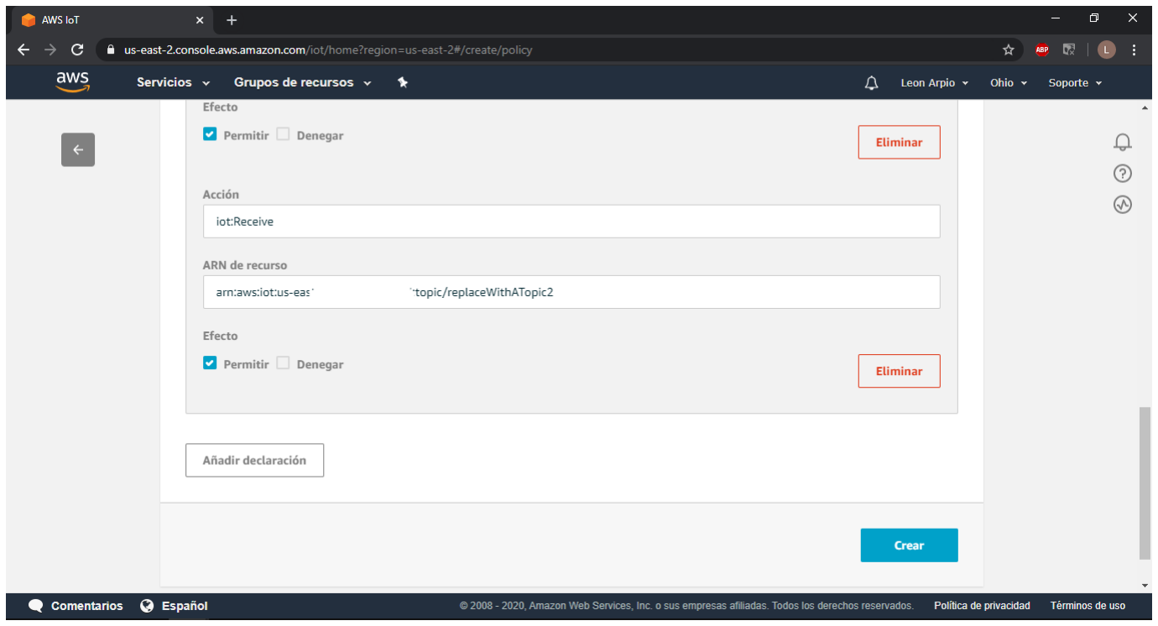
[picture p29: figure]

La política generada, permitirá a los dispositivos con ID de cliente replaceWithAClientId1 y

replaceWithAClientId2 que se conecten por MQTT, y que se subscriban y reciban información

del tópico replaceWithATopic2, pero no permitirá que publique en replaceWithATopic1 (Una

vez generado el certificado). Se puede utilizar “*” como wildcard, por ejemplo, aprobar que se

publique a /example/* permitirá que pueden llegar mensajes a cualquier tópico que empiece

con /example/.

Generar certificados

Ir a Seguir>Certificados para generar uno, y asignarlo a la política.

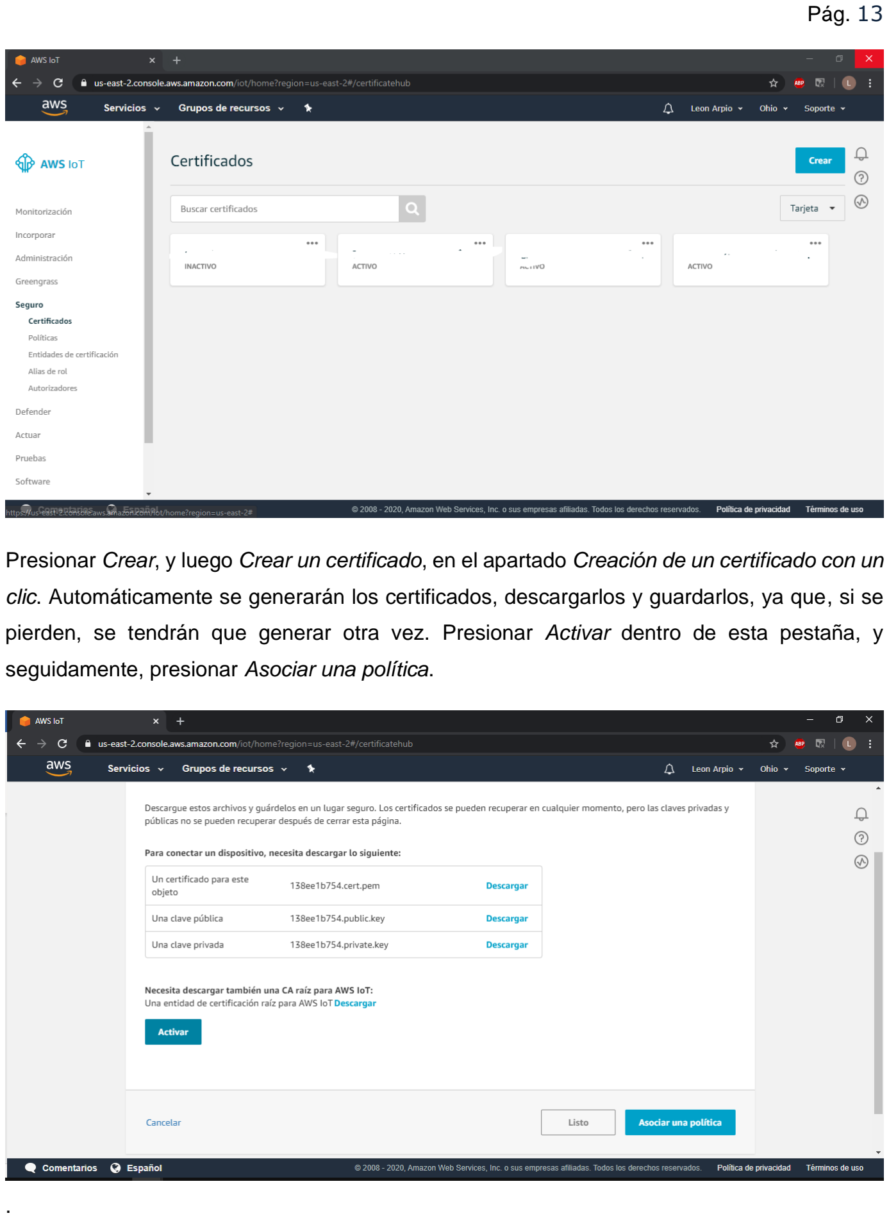
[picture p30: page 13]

Presionar Crear, y luego Crear un certificado, en el apartado Creación de un certificado con un

clic. Automáticamente se generarán los certificados, descargarlos y guardarlos, ya que, si se

pierden, se tendrán que generar otra vez. Presionar Activar dentro de esta pestaña, y

seguidamente, presionar Asociar una política.

En la siguiente pestaña, aparecerán las políticas configuradas, y se deberá seleccionar la o las

políticas que se deseen asociar a este certificado. Al finalizar, presionar Listo.

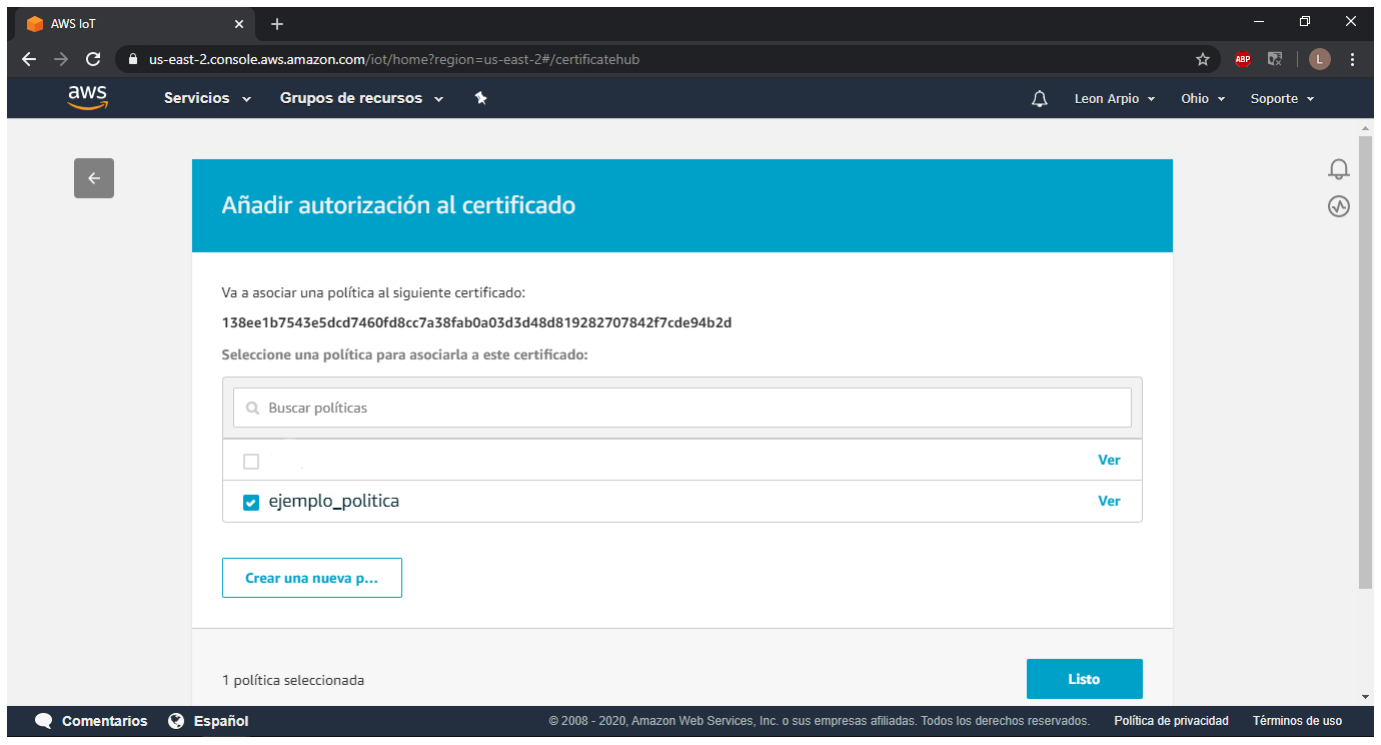
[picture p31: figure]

Esto | implica | que | a | partir | de | ahora | los | dispositivos | replaceWithAClientId1 | y

replaceWithAClientId2 podrán conectarse a AWS, utilizando los certificados que se generaron

en este paso. Al salir de esta pestaña, volverán a aparecer los certificados, pero el último que

generamos aparecerá como inactivo.

Nota: Ningún dispositivo se puede conectar a AWS sin una política que lo permita y los

certificados correspondientes.

Reglas

Las reglas permiten redireccionar los mensajes que llegan a AWS a los diferentes servicios de

este. Ir a la pestaña Actuar>Reglas y presionar Crear.

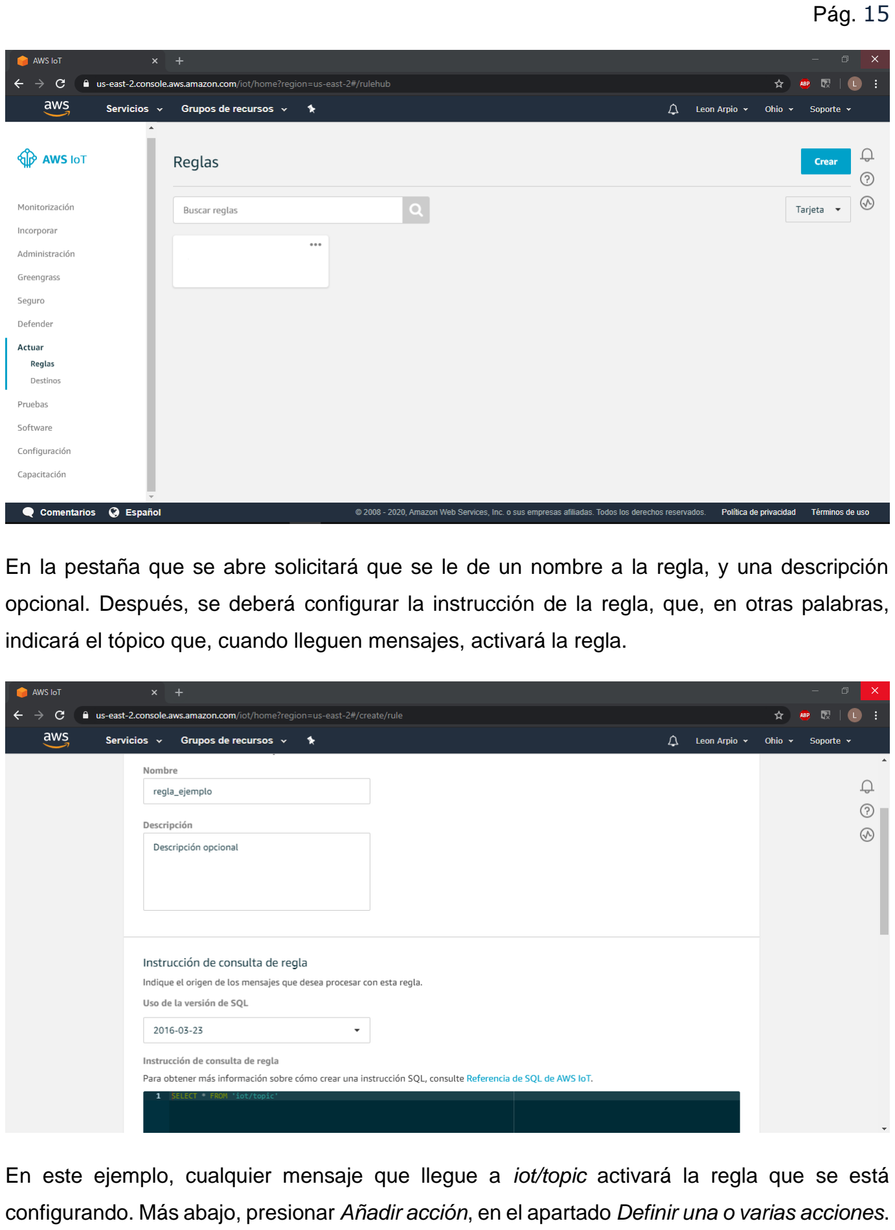
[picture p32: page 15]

En la pestaña que se abre solicitará que se le de un nombre a la regla, y una descripción

opcional. Después, se deberá configurar la instrucción de la regla, que, en otras palabras,

indicará el tópico que, cuando lleguen mensajes, activará la regla.

En este ejemplo, cualquier mensaje que llegue a iot/topic activará la regla que se está

configurando. Más abajo, presionar Añadir acción, en el apartado Definir una o varias acciones.

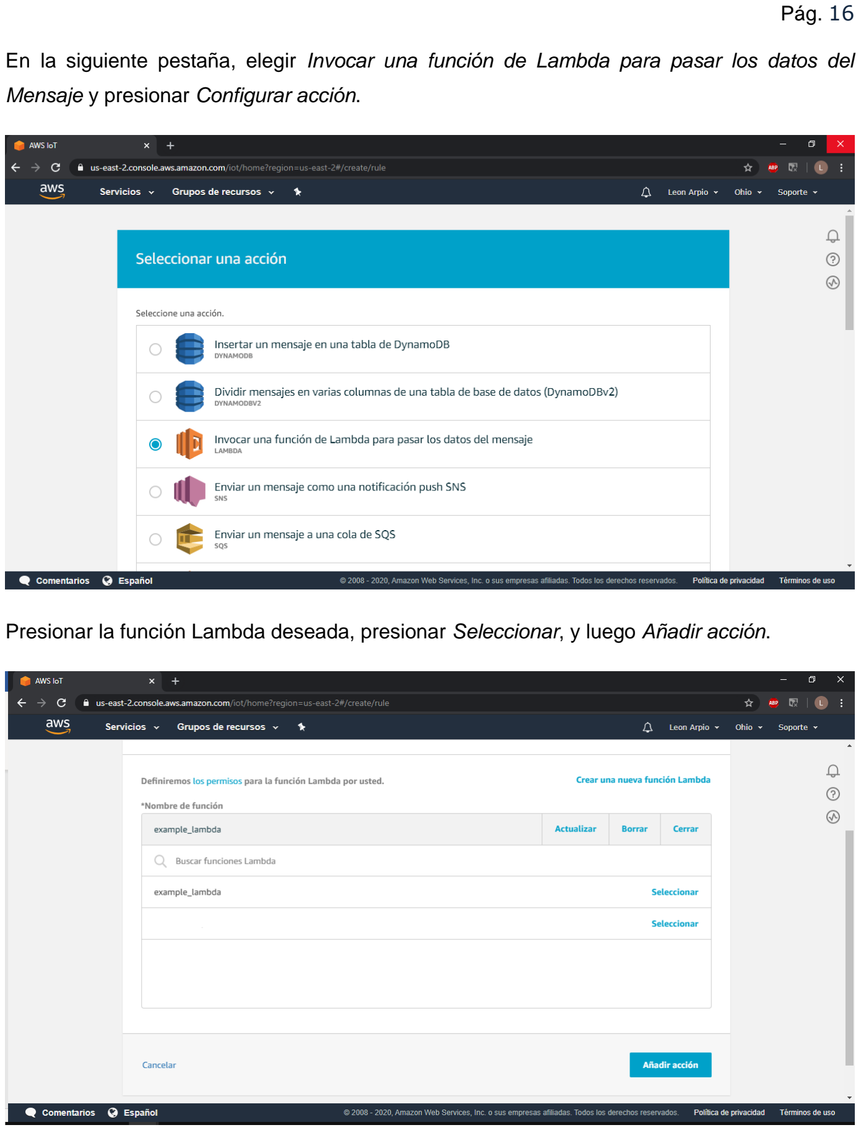
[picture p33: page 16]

En la siguiente pestaña, elegir Invocar una función de Lambda para pasar los datos del

Mensaje y presionar Configurar acción.

Presionar la función Lambda deseada, presionar Seleccionar, y luego Añadir acción.

Regresaremos a la ventana anterior, en la cual debemos de elegir una acción de error, esta se

ejecutará en caso de que la función Lambda produzca algún error, por ejemplo, si el mensaje

que llega no está en formato JSON. Para esta acción se recomienda elegir la opción Volver a

publicar mensajes en un tema de AWS IoT para redirigir el mensaje erróneo a otro tópico.

Presionar configurar acción.

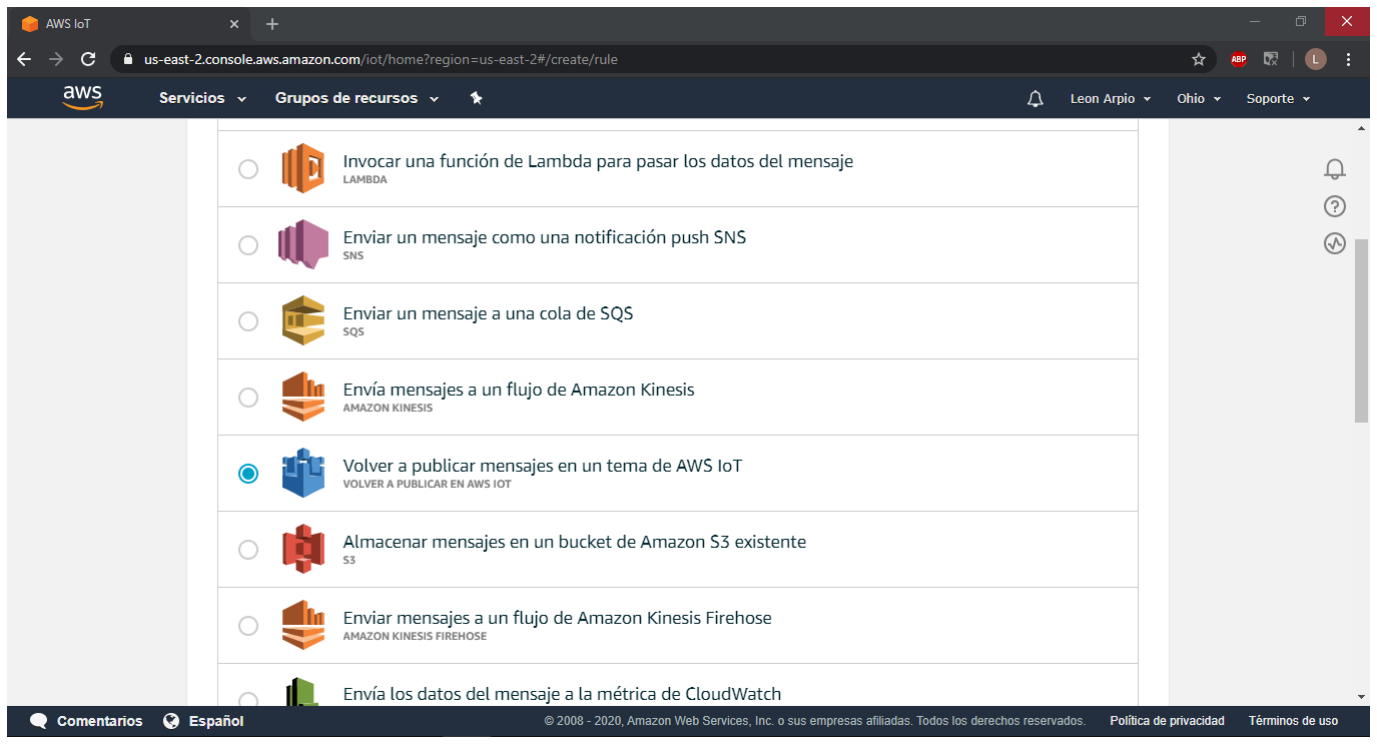
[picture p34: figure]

Después, elegir el tema al cual se publicará el mensaje, también, se deberá de elegir un rol

para dar a AWS IoT acceso a la acción. Presionar Crear un rol.

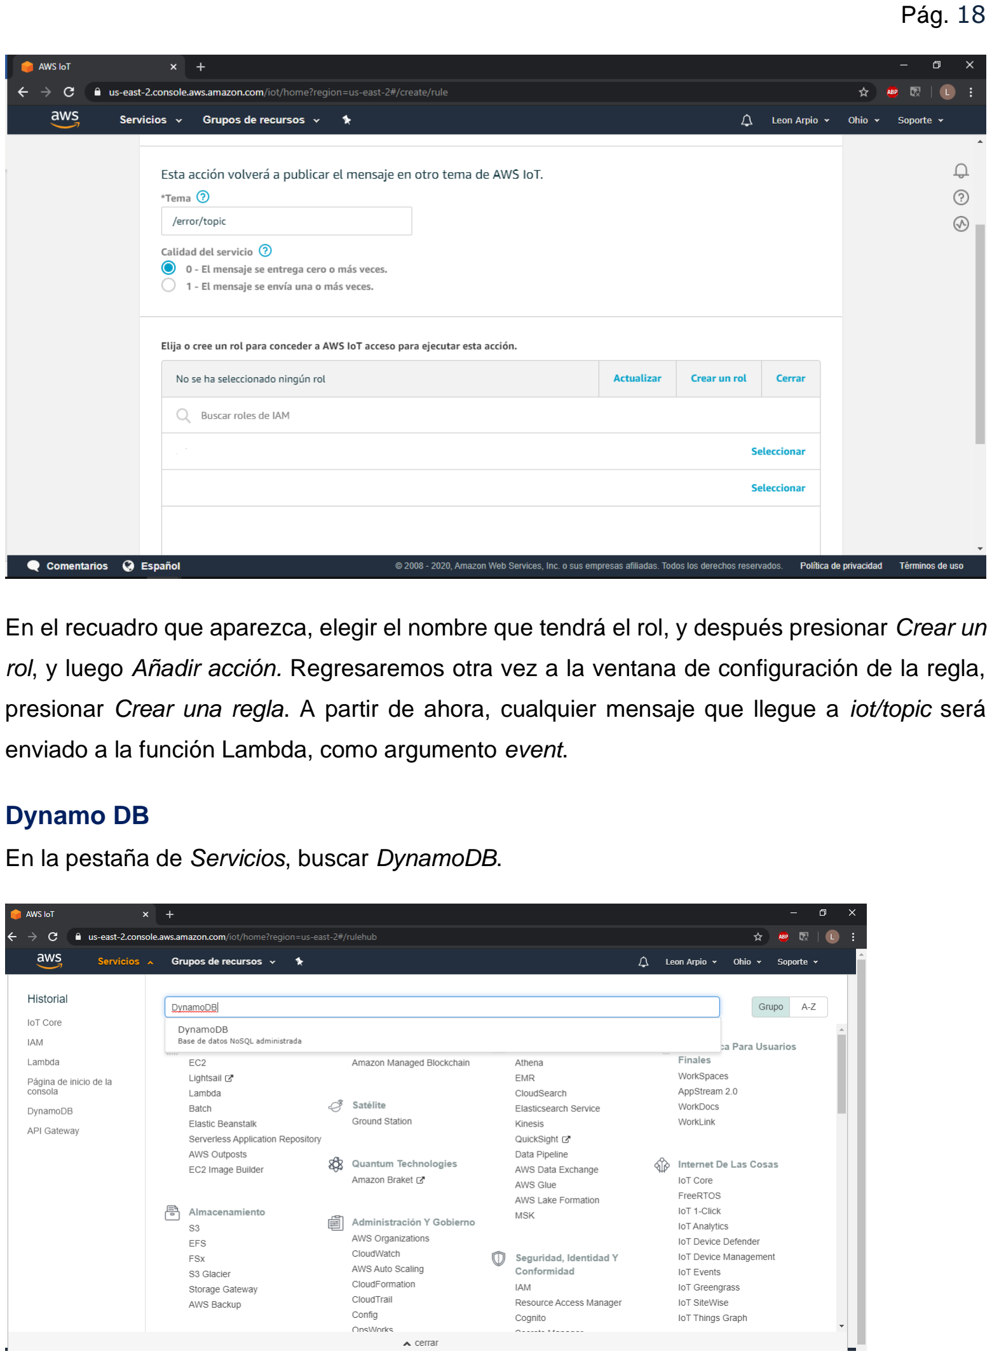
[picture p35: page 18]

En el recuadro que aparezca, elegir el nombre que tendrá el rol, y después presionar Crear un

rol, y luego Añadir acción. Regresaremos otra vez a la ventana de configuración de la regla,

presionar Crear una regla. A partir de ahora, cualquier mensaje que llegue a iot/topic será

enviado a la función Lambda, como argumento event.

Dynamo DB

En la pestaña de Servicios, buscar DynamoDB.

Cuando se abra la nueva ventana, presionar Crear tabla.

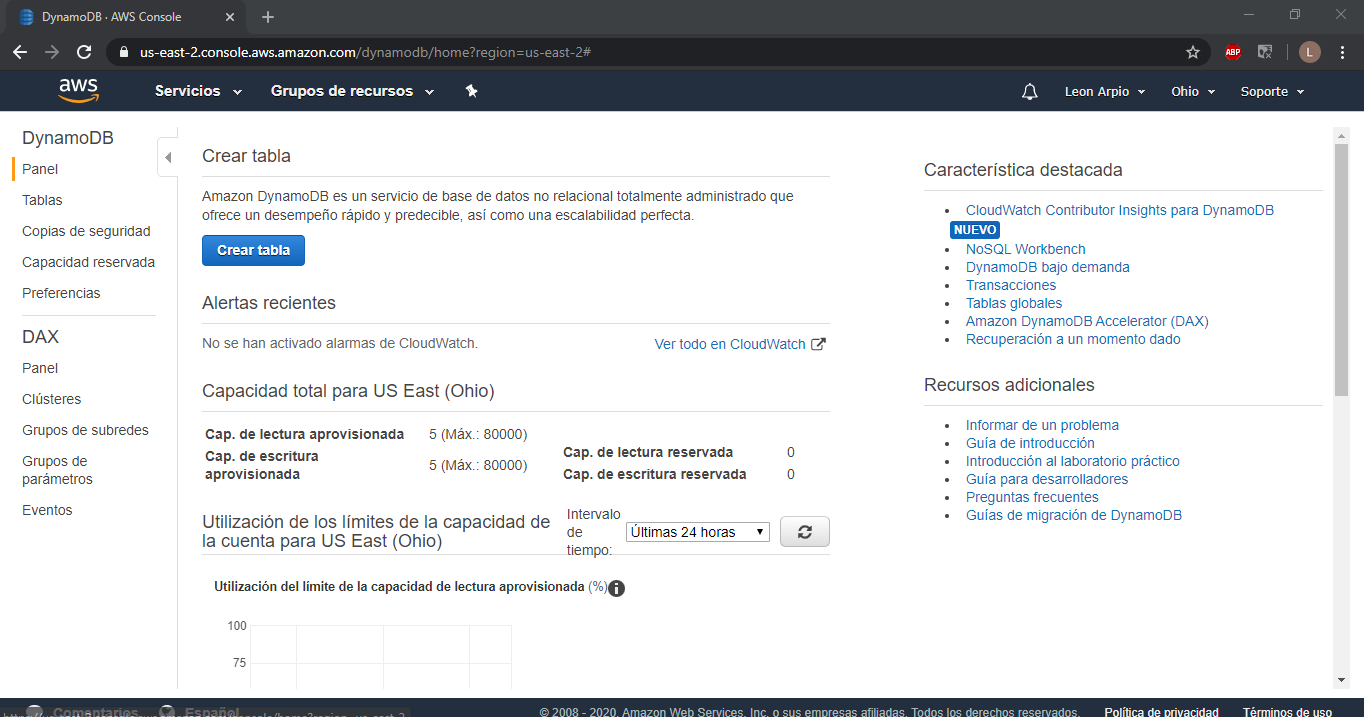
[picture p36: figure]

En la siguiente ventana, se deberá de dar un nombre a la tabla, y elegir una clave de partición,

la cual será un identificador que permita diferenciar entre los dispositivos que publican en la

tabla, por ejemplo, IMEI. Después se deberá de elegir la clave de ordenación, que es un

identificador que permite diferenciar entre los mensajes publicados por un solo dispositivo, por

ejemplo, timestamp. Dado que IMEI es una cadena de caracteres, y timestamp es un valor

numérico, es importante seleccionar cadena y número respectivamente. Al final presionar

Crear.

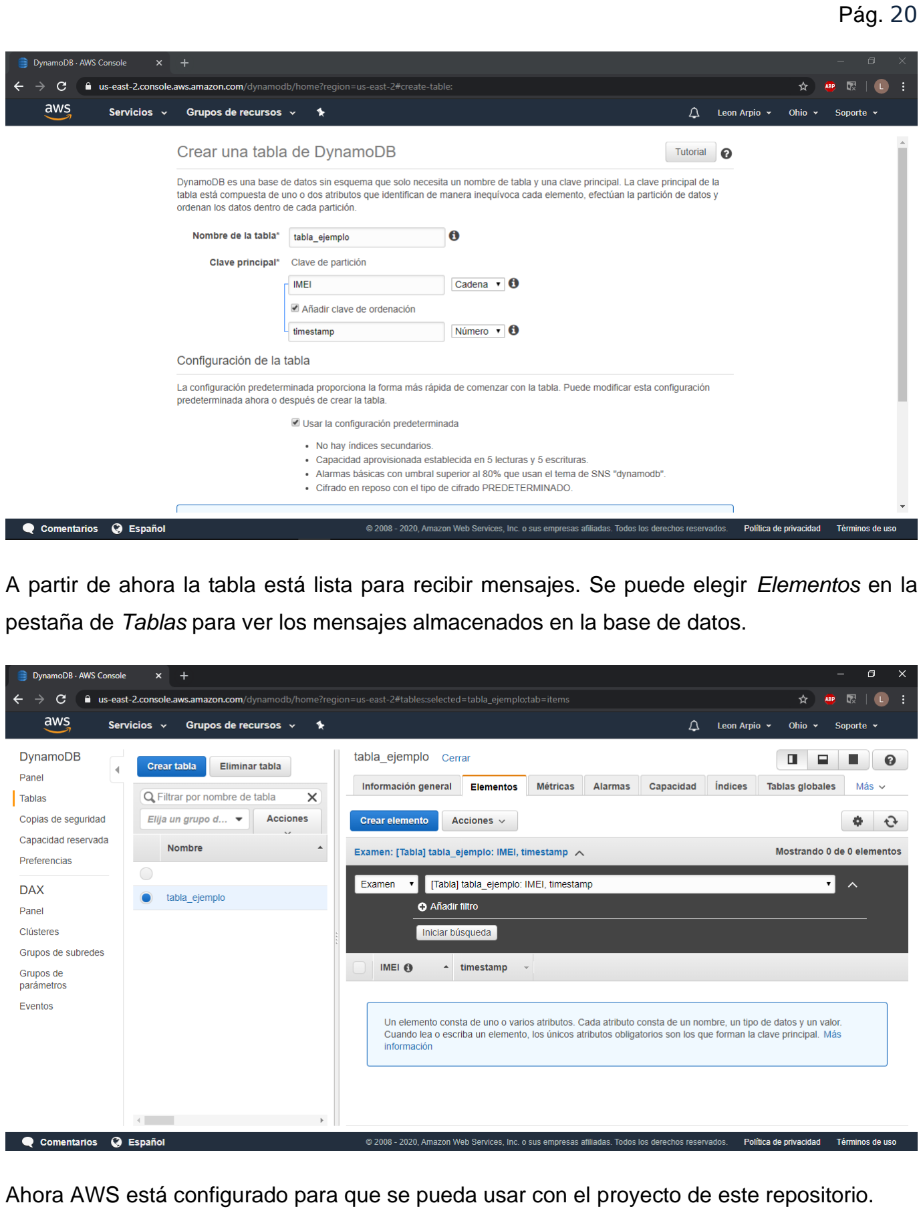
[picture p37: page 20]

A partir de ahora la tabla está lista para recibir mensajes. Se puede elegir Elementos en la

pestaña de Tablas para ver los mensajes almacenados en la base de datos.

Ahora AWS está configurado para que se pueda usar con el proyecto de este repositorio.

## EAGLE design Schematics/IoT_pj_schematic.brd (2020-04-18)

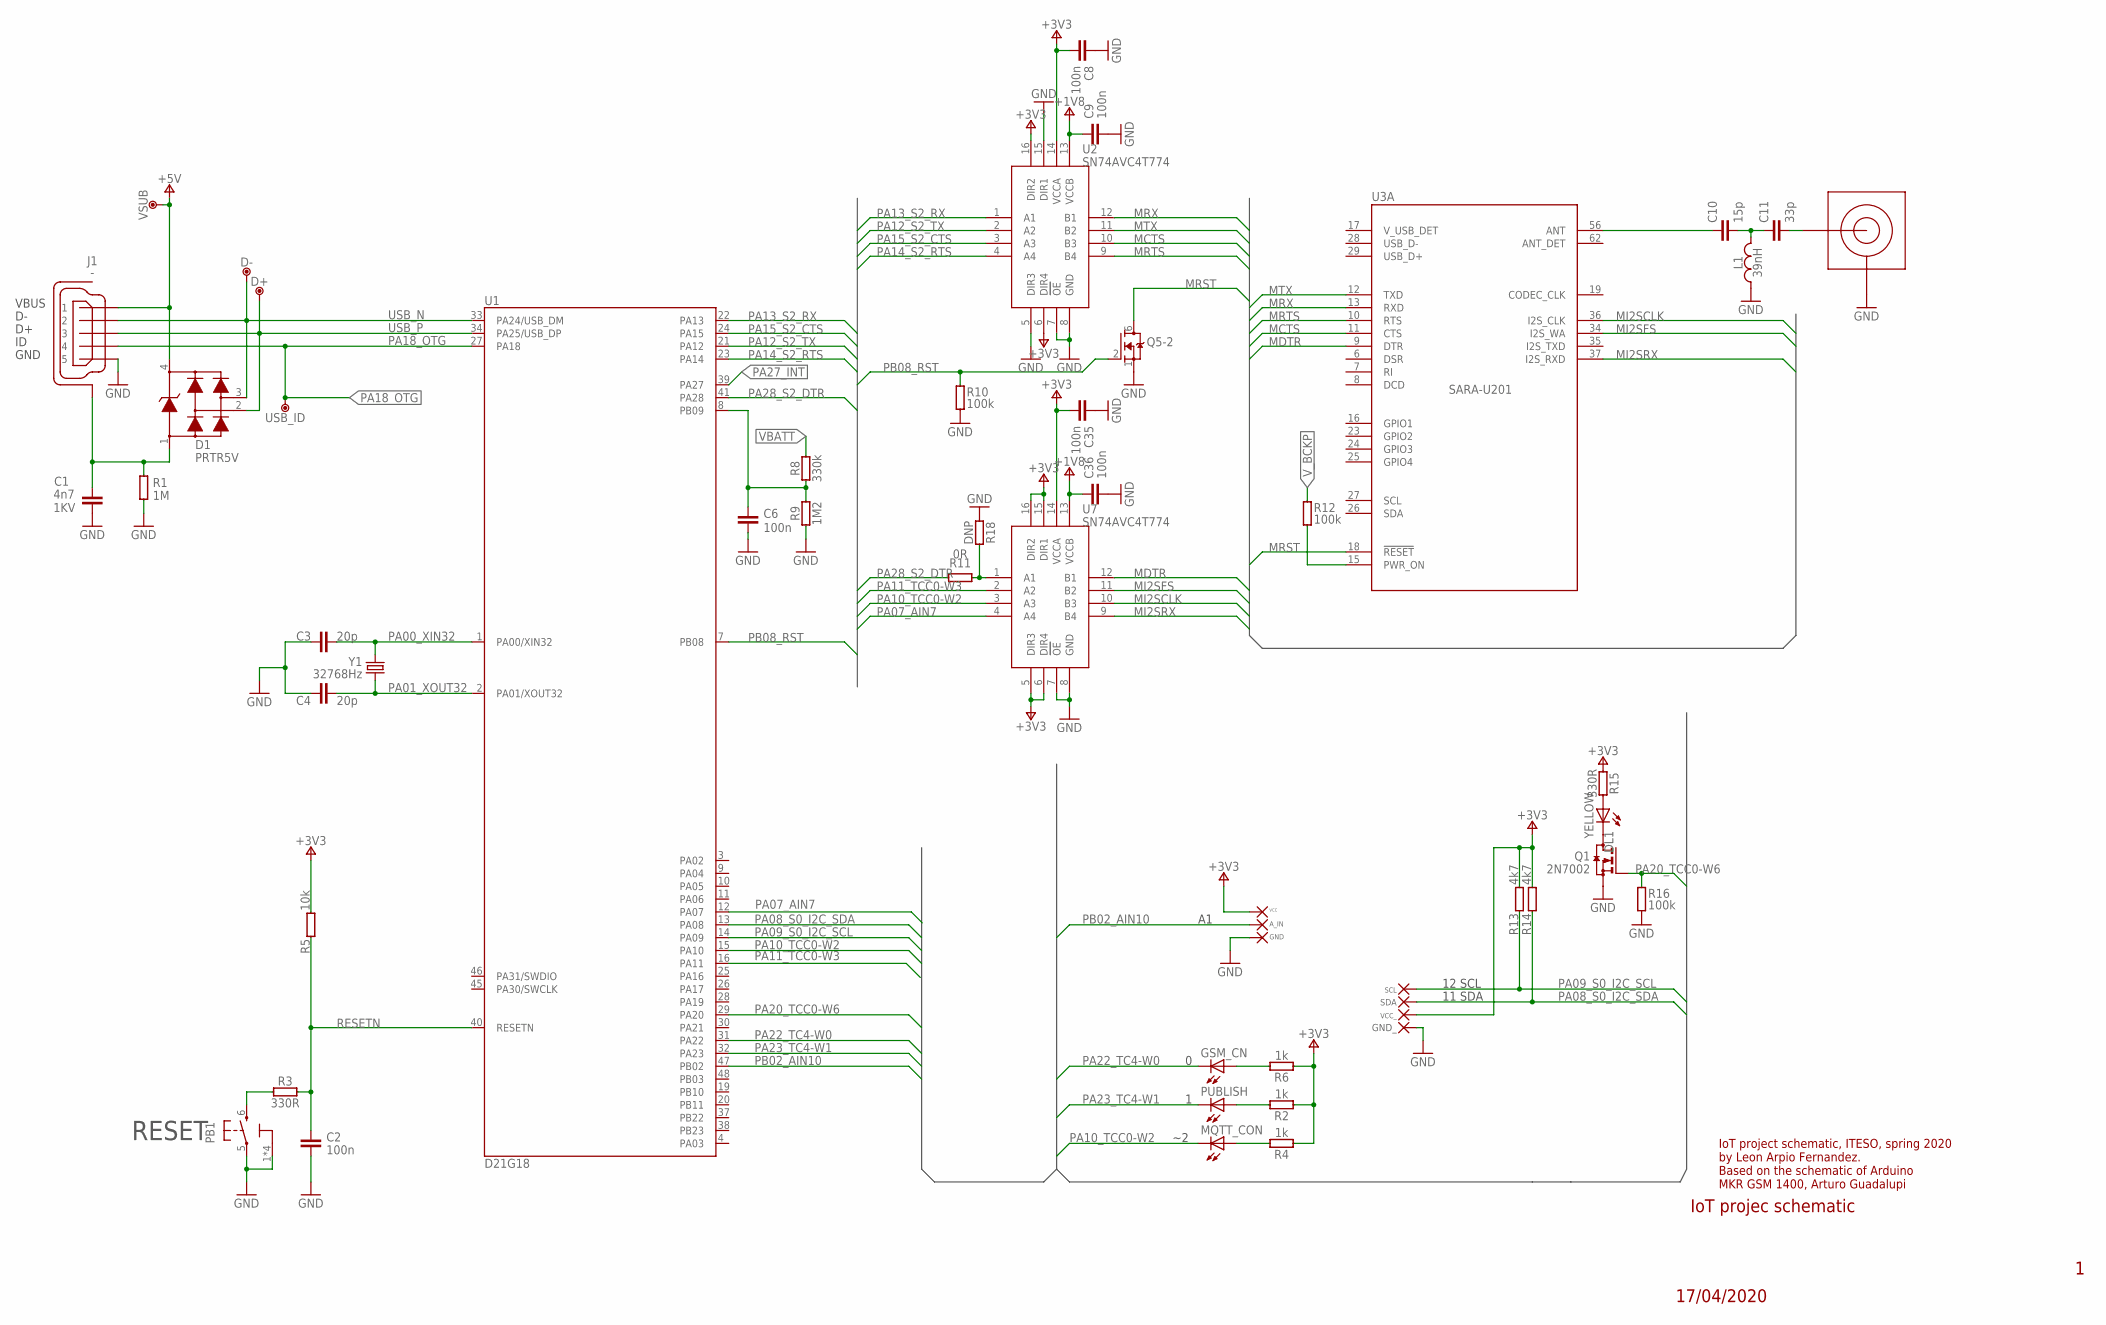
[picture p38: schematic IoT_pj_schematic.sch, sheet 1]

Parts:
A_IN: 2,15/1,0
C1: 4n7; 0805-R2013X50N; VOLTAGE 1KV
C2, C6, C8, C9, C35, C36: 100n; 0402-1005X55N
C3, C4: 20p; 0402-1005X55N
C10: 15p; 0402-1005X55N
C11: 33p; 0402-1005X55N
D1: PRTR5V; SOT190P230X110-4N
D+: DNP; TP-1.00MM
D-: DNP; TP-1.00MM
DL1: YELLOW; LEDC1608X80N-AK
GND: 2,15/1,0
GND_: 2,15/1,0
GSM_CN: LEDSML0603; SML0603
J1: -; ZX62-AB-5PA
J6: -; U.FL-R-SMT-1(60)
L1: 39nH; C0402
MQTT_CON: LEDSML0603; SML0603
PB1: PTS820; C&K_PTS820_NO_HOLES
PUBLISH: LEDSML0603; SML0603
Q1: 2N7002; SOTFL50P160X78-3
Q5: 2N7002DW-7-FNO_PAD; PWR_SC70-6L2
R1: 1M; 0402-1005X55N
R2, R4, R6: 1k; 0402-1005X55N
R3, R15: 330R; 0402-1005X55N
R5: 10k; 0402-1005X55N
R8: 330k; 0402-1005X55N
R9: 1M2; 0402-1005X55N
R10, R12, R16: 100k; 0402-1005X55N
R11: 0R; 0402-1005X55N
R13, R14: 4k7; 0402-1005X55N
R18: DNP; 0402-1005X55N
SCL: 2,15/1,0
SDA: 2,15/1,0
U1: D21G18; QFN50P700X700X90-49XN-EPSQ515
U2, U7: SN74AVC4T774; RSV
U3: SARA-U201; SARA-96
USB_ID: DNP; TP-1.00MM
VCC: 2,15/1,0
VCC_: 2,15/1,0
VSUB: DNP; TP-1.00MM
Y1: 32768Hz; ABS07

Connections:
+1V8: C9.1, C36.1, U2.13 (VCCB), U7.13 (VCCB); also elsewhere on the board
+3V3: C8.2, C35.2, R2.1, R4.1, R5.2, R6.1, R13.2, R14.2, R15.1, U2.6 (DIR4), U2.14 (VCCA), U2.16 (DIR2), U7.5 (DIR3), U7.6 (DIR4), U7.14 (VCCA), U7.15 (DIR1), U7.16 (DIR2), VCC.1, VCC_.1; also elsewhere on the board
+5V: D1.4, J1.1, VSUB.X; also elsewhere on the board
GND: C1.2, C2.2, C3.1, C4.1, C6.2, C8.1, C9.2, C35.1, C36.2, GND.1, GND_.1, J1.5, J6.GND1 (GND), J6.GND2 (GND), L1.1, PB1.1 (3), PB1.2 (3), PB1.3, PB1.4 (3), PB1.5 (1), Q1.S, Q5.1 (S), R1.1, R9.1, R10.1, R16.1, R18.1, U2.5 (DIR3), U2.7 (OE), U2.8 (GND), U2.15 (DIR1), U7.7 (OE), U7.8 (GND); also elsewhere on the board
MCTS: U2.10 (B3), U3.11 (CTS)
MDTR: U3.9 (DTR), U7.12 (B1)
MI2SCLK: U3.36 (I2S_CLK), U7.10 (B3)
MI2SFS: U3.34 (I2S_WA), U7.11 (B2)
MI2SRX: U3.37 (I2S_RXD), U7.9 (B4)
MRST: Q5.6 (D), U3.18 (!RESET)
MRTS: U2.9 (B4), U3.10 (RTS)
MRX: U2.12 (B1), U3.13 (RXD)
MTX: U2.11 (B2), U3.12 (TXD)
N17658775: PB1.6 (2), R3.1
unnamed: C1.1, D1.1, J1.6 (SH), J1.7 (SH), J1.8 (SH), J1.9 (SH), J1.10 (SH), J1.11 (SH), R1.2
unnamed: GSM_CN.A, R6.2
unnamed: PUBLISH.A, R2.2
unnamed: C10.1, U3.56 (ANT)
unnamed: C6.1, R8.1, R9.2, U1.8 (PB09)
unnamed: DL1.A, R15.2
unnamed: C11.2, J6.SIG
unnamed: R11.1, R18.2, U7.1 (A1)
unnamed: DL1.C, Q1.D
unnamed: R12.1, U3.15 (PWR_ON)
unnamed: C10.2, C11.1, L1.2
unnamed: MQTT_CON.A, R4.2
PA00_XIN32: C3.2, U1.1 (PA00/XIN32), Y1.2
PA01_XOUT32: C4.2, U1.2 (PA01/XOUT32), Y1.1
PA07_AIN7: U1.12 (PA07), U7.4 (A4)
PA08_S0_I2C_SDA: R14.1, SDA.1, U1.13 (PA08); also elsewhere on the board
PA09_S0_I2C_SCL: R13.1, SCL.1, U1.14 (PA09); also elsewhere on the board
PA10_TCC0-W2: MQTT_CON.C, U1.15 (PA10), U7.3 (A3)
PA11_TCC0-W3: U1.16 (PA11), U7.2 (A2)
PA12_S2_TX: U1.21 (PA12), U2.2 (A2)
PA13_S2_RX: U1.22 (PA13), U2.1 (A1)
PA14_S2_RTS: U1.23 (PA14), U2.4 (A4)
PA15_S2_CTS: U1.24 (PA15), U2.3 (A3)
PA18_OTG: J1.4, U1.27 (PA18), USB_ID.X; also elsewhere on the board
PA20_TCC0-W6: Q1.G, R16.2, U1.29 (PA20)
PA22_TC4-W0: GSM_CN.C, U1.31 (PA22)
PA23_TC4-W1: PUBLISH.C, U1.32 (PA23)
PA27_INT: U1.39 (PA27); also elsewhere on the board
PA28_S2_DTR: R11.2, U1.41 (PA28)
PB02_AIN10: A_IN.1, U1.47 (PB02)
PB08_RST: Q5.2 (G), R10.2, U1.7 (PB08)
RESETN: C2.1, R3.2, R5.1, U1.40 (RESETN)
USB_N: D1.3, D-.X, J1.2, U1.33 (PA24/USB_DM); also elsewhere on the board
USB_P: D1.2, D+.X, J1.3, U1.34 (PA25/USB_DP); also elsewhere on the board
VBATT: R8.2; also elsewhere on the board
V_BCKP: R12.2; also elsewhere on the board

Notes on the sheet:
12 SCL
11 SDA
RESET
IoT project schematic, ITESO, spring 2020 by Leon Arpio Fernandez. Based on the schematic of Arduino MKR GSM 1400, Arturo Guadalupi
IoT projec schematic
17/04/2020

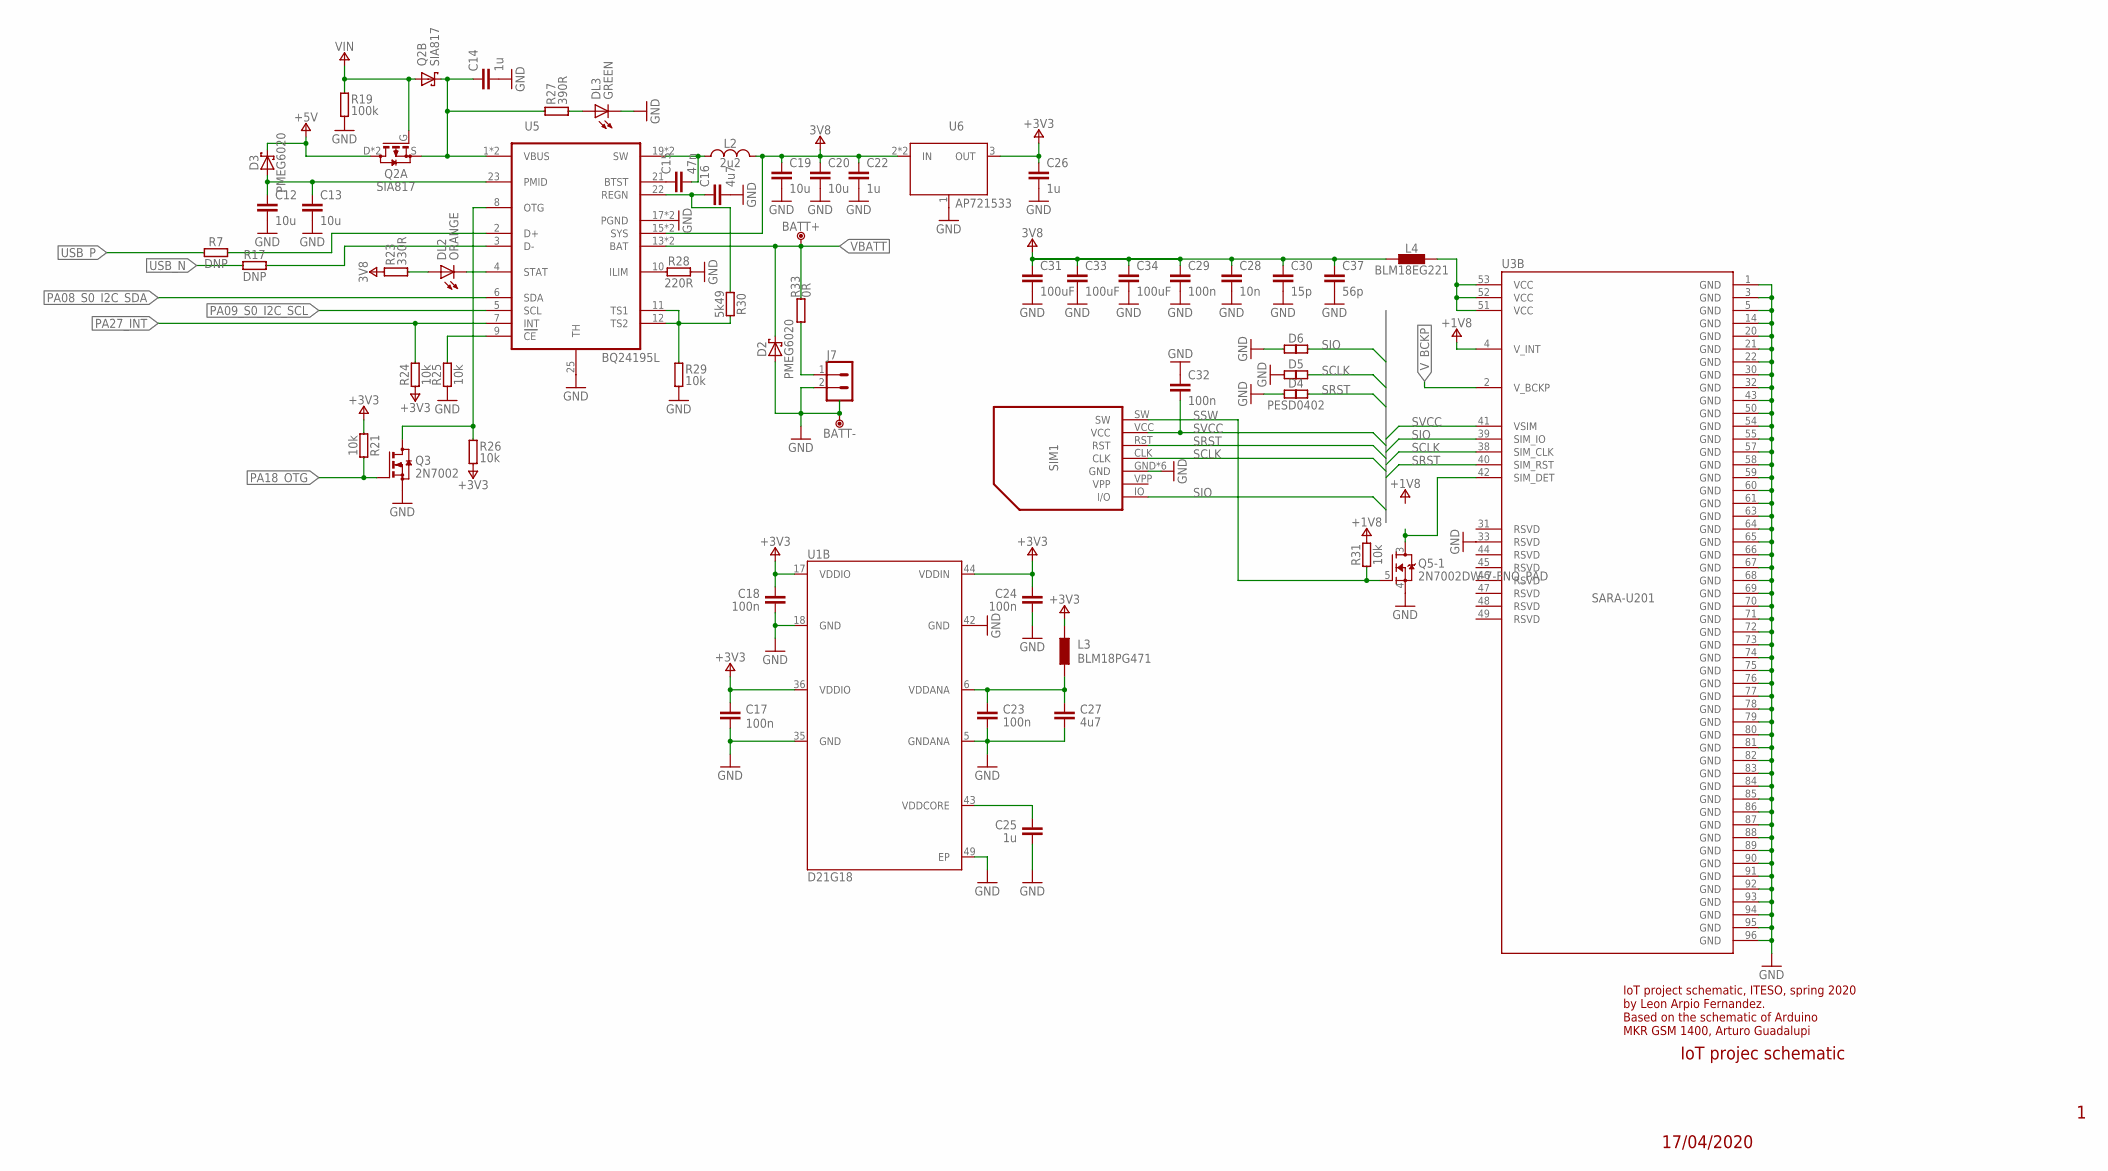
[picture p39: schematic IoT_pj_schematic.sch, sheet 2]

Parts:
BATT+: DNP; TP-1.00MM
BATT-: DNP; TP-1.00MM
C12, C13, C19, C20: 10u; 0603-1608X90N
C14, C22, C25, C26: 1u; 0402-1005X55N
C15: 47n; 0402-1005X55N
C16: 4u7; 0402-1005X55N
C17, C18, C23, C24, C29, C32: 100n; 0402-1005X55N
C27: 4u7; 0603-1608X90N
C28: 10n; 0402-1005X55N
C30: 15p; 0402-1005X55N
C31, C33, C34: 100uF; C1206
C37: 56p; 0402-1005X55N
D2, D3: PMEG6020; SODFL3517X110N
D4, D5, D6: PESD0402; 0402-1005X55N
DL2: ORANGE; LEDC1608X80N-AK
DL3: GREEN; LEDC1608X80N-AK
J7: -; JST-S2B-PH-SM4-TB
L2: 2u2; SRP4020
L3: BLM18PG471; 0603-1608X90N
L4: BLM18EG221; 0603-1608X90N
Q2: SIA817; SON65P205X205X75-8N-MWSD
Q3: 2N7002; SOTFL50P160X78-3
Q5: 2N7002DW-7-FNO_PAD; PWR_SC70-6L2
R7, R17: DNP; 0402-1005X55N
R19: 100k; 0402-1005X55N
R21, R24, R25, R26, R29, R31: 10k; 0402-1005X55N
R23: 330R; 0402-1005X55N
R27: 390R; 0402-1005X55N
R28: 220R; 0402-1005X55N
R30: 5k49; 0402-1005X55N
R33: 0R; C0603
SIM1: -; MICROSIM8
U1: D21G18; QFN50P700X700X90-49XN-EPSQ515
U3: SARA-U201; SARA-96
U5: BQ24195L; QFN24
U6: AP721533; SOT89-3L

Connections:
+1V8: R31.2, U3.4 (V_INT); also elsewhere on the board
+3V3: C17.1, C18.1, C24.1, C26.1, L3.1, R21.1, R24.1, R26.1, U1.17 (VDDIO), U1.36 (VDDIO), U1.44 (VDDIN), U6.3 (OUT); also elsewhere on the board
+3V8: C19.1, C20.1, C22.1, C28.1, C29.1, C30.1, C31.1, C33.1, C34.1, C37.1, L2.2, L4.1, R23.2, U5.15 (SYS), U5.16 (SYS), U6.2 (IN), U6.TH (IN)
+5V: D3.C, Q2.D, Q2.D2 (D); also elsewhere on the board
GND: BATT-.X, C12.2, C13.2, C14.2, C16.2, C17.2, C18.2, C19.2, C20.2, C22.2, C23.2, C24.2, C25.2, C26.2, C27.2, C28.2, C29.2, C30.2, C31.2, C32.1, C33.2, C34.2, C37.2, D2.A, D4.1, D5.1, D6.1, DL3.C, J7.2, J7.3 (SH), J7.4 (SH), Q3.S, Q5.4 (S), R19.1, R25.1, R28.2, R29.1, SIM1.GND, SIM1.SH1 (GND), SIM1.SH2 (GND), SIM1.SH3 (GND), SIM1.SH4 (GND), SIM1.SH5 (GND), U1.5 (GNDANA), U1.18 (GND), U1.35 (GND), U1.42 (GND), U1.49 (EP), U3.1 (GND), U3.3 (GND), U3.5 (GND), U3.14 (GND), U3.20 (GND), U3.21 (GND), U3.22 (GND), U3.30 (GND), U3.32 (GND), U3.33 (RSVD), U3.43 (GND), U3.50 (GND), U3.54 (GND), U3.55 (GND), U3.57 (GND), U3.58 (GND), U3.59 (GND), U3.60 (GND), U3.61 (GND), U3.63 (GND), U3.64 (GND), U3.65 (GND), U3.66 (GND), U3.67 (GND), U3.68 (GND), U3.69 (GND), U3.70 (GND), U3.71 (GND), U3.72 (GND), U3.73 (GND), U3.74 (GND), U3.75 (GND), U3.76 (GND), U3.77 (GND), U3.78 (GND), U3.79 (GND), U3.80 (GND), U3.81 (GND), U3.82 (GND), U3.83 (GND), U3.84 (GND), U3.85 (GND), U3.86 (GND), U3.87 (GND), U3.88 (GND), U3.89 (GND), U3.90 (GND), U3.91 (GND), U3.92 (GND), U3.93 (GND), U3.94 (GND), U3.95 (GND), U3.96 (GND), U5.17 (PGND), U5.18 (PGND), U5.25 (TH), U6.1 (GND/ADJ); also elsewhere on the board
N17798864: DL2.A, R23.1
N17834267: DL3.A, R27.1
N17852357: C23.1, C27.1, L3.2, U1.6 (VDDANA)
N17852431: C25.1, U1.43 (VDDCORE)
unnamed: J7.1, R33.1
unnamed: Q5.3 (D), U3.42 (SIM_DET)
unnamed: L4.2, U3.51 (VCC), U3.52 (VCC), U3.53 (VCC)
unnamed: C15.2, L2.1, U5.19 (SW), U5.20 (SW)
unnamed: R7.2, U5.2 (D+)
unnamed: C14.1, Q2.K (C), Q2.K2 (C), Q2.S, R27.2, U5.1 (VBUS), U5.24 (VBUS)
unnamed: C15.1, U5.21 (BTST)
unnamed: R28.1, U5.10 (ILIM)
unnamed: R17.2, U5.3 (D-)
unnamed: C16.1, R30.1, U5.22 (REGN)
unnamed: Q3.D, R26.2, U5.8 (OTG)
unnamed: R29.2, R30.2, U5.11 (TS1), U5.12 (TS2)
unnamed: R25.2, U5.9 (CE)
PA08_S0_I2C_SDA: U5.6 (SDA); also elsewhere on the board
PA09_S0_I2C_SCL: U5.5 (SCL); also elsewhere on the board
PA18_OTG: Q3.G, R21.2; also elsewhere on the board
PA27_INT: R24.2, U5.7 (INT); also elsewhere on the board
SCLK: D5.2, SIM1.CLK, U3.38 (SIM_CLK)
SIO: D6.2, SIM1.IO (I/O), U3.39 (SIM_IO)
SRST: D4.2, SIM1.RST, U3.40 (SIM_RST)
SSW: Q5.5 (G), R31.1, SIM1.SW
STAT: DL2.C, U5.4 (STAT)
SVCC: C32.2, SIM1.VCC, U3.41 (VSIM)
USB_N: R17.1; also elsewhere on the board
USB_P: R7.1; also elsewhere on the board
VBATT: BATT+.X, D2.C, R33.2, U5.13 (BAT), U5.14 (BAT); also elsewhere on the board
VIN: Q2.A, Q2.G, R19.2
VUSB1: C12.1, C13.1, D3.A, U5.23 (PMID)
V_BCKP: U3.2 (V_BCKP); also elsewhere on the board

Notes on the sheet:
IoT project schematic, ITESO, spring 2020 by Leon Arpio Fernandez. Based on the schematic of Arduino MKR GSM 1400, Arturo Guadalupi
IoT projec schematic
17/04/2020

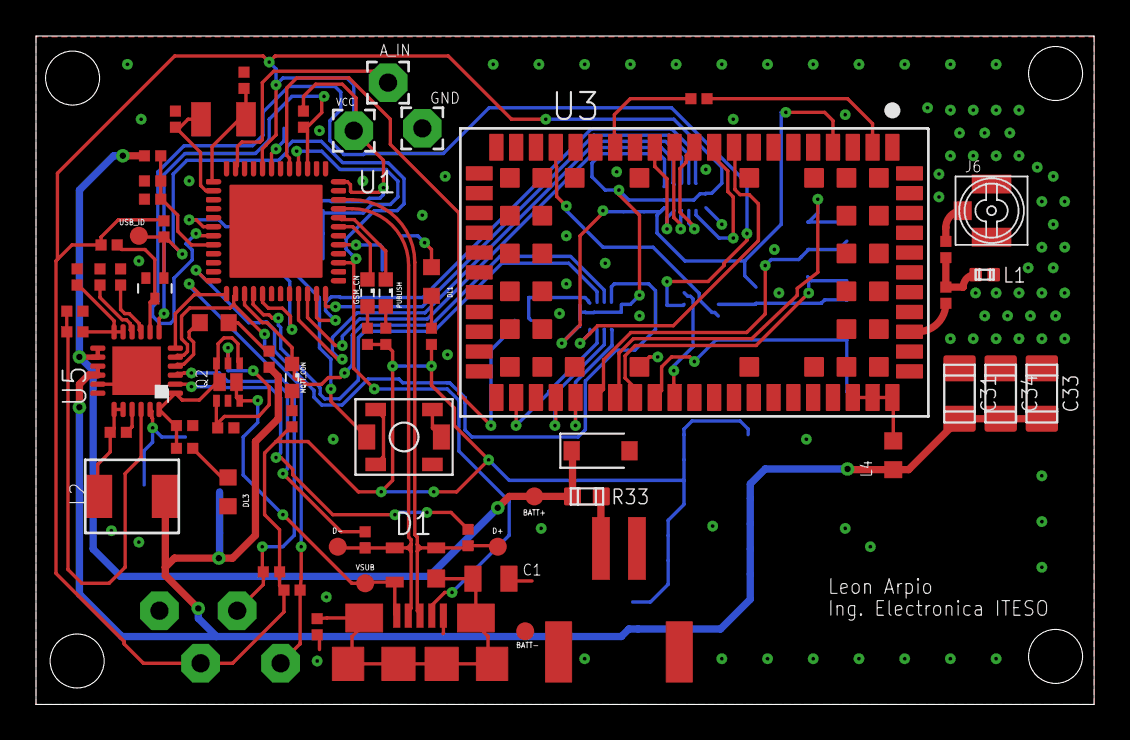
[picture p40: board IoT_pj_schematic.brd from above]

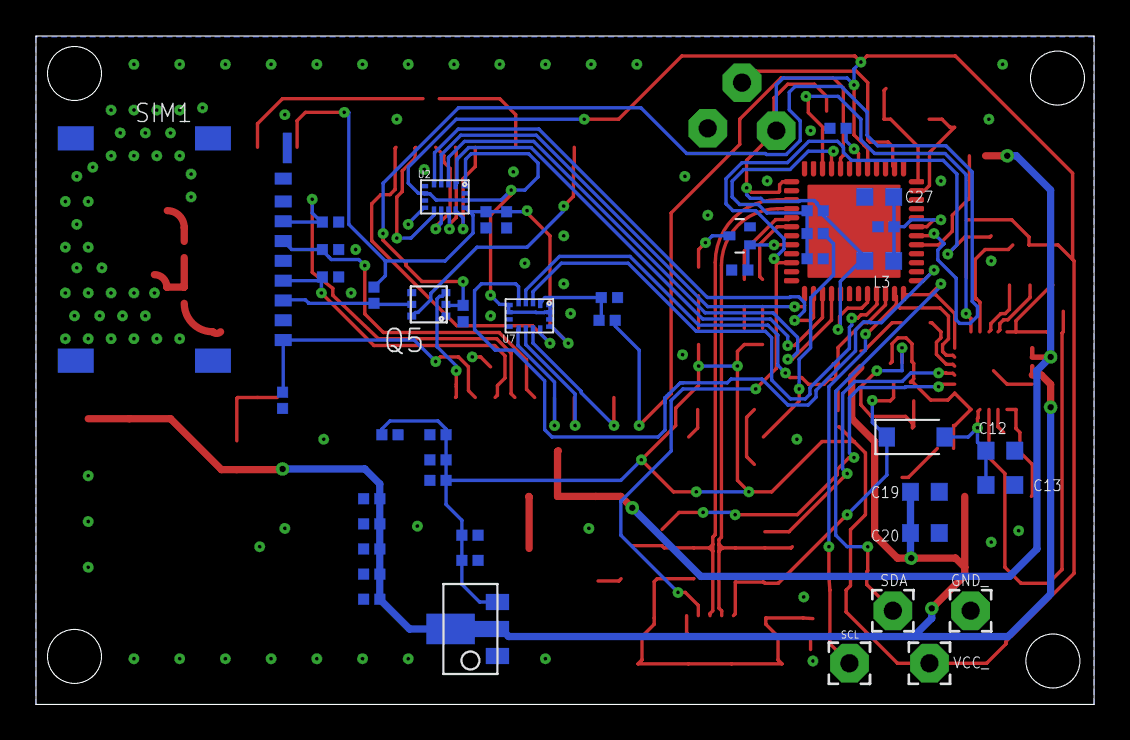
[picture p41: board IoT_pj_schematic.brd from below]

Board: 2 copper layers, 58.8 x 37.1 mm, 109 parts (50 on the bottom side), 76 nets.

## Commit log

2020-04-10 Add: Arduino example to publish a message to an MQTT broker
    No SSL/TLS authentication, dummy message sent
    [Proyecto_IoT.ino]
2020-04-11 Add: MQTT over SSL (RSA 2048)
    Commit NOT WORKING
    [Proyecto_IoT.ino]
2020-04-13 Add: Sensors readings
2020-04-13 Fix: Remove prints
2020-04-14 Fix: Error when building the message
    Commas, quotes and bracers need to be arrays, not single variables as in C
    [Proyecto_IoT.ino]
2020-04-14 Data is published correctly in Ubidots
    [Proyecto_IoT.ino]
2020-04-14 Lambda according to Arduino message
2020-04-14 Add: LEDs logic to show the device's status
    Fix: Luminosity model was incomplete
    [Proyecto_IoT.ino]
2020-04-17 Add: Schematic
    [IoT_pj_schematic.sch]
2020-04-17 Add: Board (Placed, unrouted)
    [IoT_pj_schematic.brd]
2020-04-18 Add: Board fully routed
    2-layer board
    [IoT_pj_schematic.brd]
2020-04-18 FIx: Silkscreen names and values corrected
    Corrected the position so they wouldn't overlap
    [IoT_pj_schematic.brd, IoT_pj_schematic.sch]
2020-04-18 Add: Credits
    whoops
    [IoT_pj_schematic.brd]
2020-04-18 Fix: LED 3 name to MQTT_Conn
    Add: Shielding vias
    [IoT_pj_schematic.brd, IoT_pj_schematic.sch]
2020-04-18 Add: BOM
    [BOM_IoT.xlsx]
2020-04-19 Add: Total BOM price sum
    [BOM_IoT.xlsx]
2020-04-19 Add: Price in BOM per 10 prototypes
    [BOM_IoT.xlsx]
2020-04-20 Fix: Incorrect formula for luminosity
    [Proyecto_IoT.ino]

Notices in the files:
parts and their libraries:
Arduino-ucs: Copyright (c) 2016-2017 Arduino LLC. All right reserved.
